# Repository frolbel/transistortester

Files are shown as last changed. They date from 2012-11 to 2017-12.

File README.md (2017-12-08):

# TransistorTester with AVR microcontroller

This repository is based on the software repository of the TransistorTester of Markus F. and Karl-Heinz Kubbeler.

The current revision of the authors you can see on the following: [https://www.mikrocontroller.net/svnbrowser/transistortester/](https://www.mikrocontroller.net/svnbrowser/transistortester/?sortby=author)

Initially, this repository is **GitHub** clone of **SVN** repo svn://mikrocontroller.net/transistortester/

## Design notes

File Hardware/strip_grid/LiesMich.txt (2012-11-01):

Die Datei ttester_strip_grid.diy ist ein Streifenleiter-Karten Entwurf für
den Transistortester. Die Datei TTester_strip.pdf zeigt das Ergebnis im PDF-Format.

Der Entwurf wurde mit der Software diy-layout-creator (DIYLC) gemacht.
Da das Programm DIYLC in Java programmiert ist, sollte es Betriebssystem unabhängig
genutzt werden können.
Siehe dazu für nähere Information: http://code.google.com/p/diy-layout-creator

Es wurde sowohl die Abschalt-Automatik als auch der Quarz und die Präzisions-
Spannungsreferenz integriert.
Aber die Pinbelegung des ATmega wurde für dieses Layout angepaßt!
Die erforderlichen Programm-Anpassungen für den ATmega werden mit der
Makefile Option STRIP_GRID_BOARD gemacht.
Das Programm mit der Standard Pinbelegung kann auf diesem Board nicht laufen !!
Genauso wenig läuft ein für die Streifenleiter-Karte angepaßtes Programm auf
einer Standard-Karte!

Eine Standard 100mm x 100mm Streifenleiter-Karte kann auf das erforderliche Maß
verkleinert werden.
Es ist ratsam, zuerst die Befestigungslöcher zu bohren und danach die Drahtbrücken
zu verlöten. Die Leiterbahnunterbrechungen sollten an den angegebenen Stellen auf
keinen Fall vergessen werden. Beim ISP-Stecker und bei REF1 liegen die Unterbrechungen
zwischen den Rasterpunkten!

Auf der Platine ist der Spannungsregler IC2 (78L05) eingezeichnet, ein Low Drop Regler
wie der MCP1702-5002 kann in der neben der Platine gezeichneten Weise eingebaut werden.
Die Anschlußbelegung ist nicht kompatibel!
Der Widerstand R1 (680 Ohm) ist unter dem ATmega-Sockel montiert und sollte deswegen
als einer der ersten Bauteile verlötet werden. Um einen Kurzschluß auszuschließen,
sollte der Anschlußdraht mit einem Isolierschlauch überzogen werden.

Die GND Leitung ist an den ATmega von beiden Seiten herangeführt und ist zusätzlich
unter dem Sockel gebrückt.
Der Widerstand R10 ist als einziger Widerstand stehend montiert.
Wenn das Potentiometer VR1 vom LCD-Display verdeckt wird, kann man das Potentiometer
auch auf der Lötseite verbauen. Anderenfalls muß man die VEE Spannung ohne das eingesteckte
Display einstellen.

Nach der Montage aller Bauteile, aber ohne das eingesteckte Display und den ATmega
sollte man die Verbindungen mit einem Ohmmeter oder Durchgangsprüfer testen.
Die GND Verbindungen sollten nur an den vorgesehenen Pinnen (ATmega, ISP und LCD) 
vorhanden sein. Ebenso sollten die VCC Verbindungen nur an den vorgesehenen Pinnen
vorhanden sein.
Nach diesem Test kann man die Spannungsquelle anschließen und die VCC Spannung bei
gedrücktem Taster überprüfen. Wenn hier die erwarteten 5V vorhanden sind, kann
man den ATmega und das LCD einstecken.

Wenn der ATmega noch nicht programmiert ist, muß als nächste Aktion die Programmierung
des ATmega über die ISP-Schnittstelle erfolgen.

Für die eventuelle Fehlersuche sollte man die Hinweise in der PDF-Dokumentation beachten.

Viel Erfolg beim Nachbau!

Karl-Heinz

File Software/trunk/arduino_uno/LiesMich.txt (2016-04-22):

Sie müssen eine "shield" Platine für den Arduino UNO benutzen, um das Transistortester Programm zu nutzen.
Sie finden eine Beispielplatine im Ordner Hardware/ArduinoUno_shield, welche aus einem Stück Streifenraster Platinenmaterial gebildet wurde.
Diese Implementation des Transistortesters benutzt derzeit kein LCD Display.
Alle Daten werden nur auf dem seriellen Port mit 115200 Baud ausgegeben.
Natürlich hat ein unabhängiger Tester einige Vorteile.
Aber der Arduino Uno ist ein einfacher Weg um die Software auszuprobieren
weil man keinen Programmierer oder keine externe Stromversorgung braucht.

Auf meinem Mint Linux-System habe ich die Arduino Sketch Entwicklungsumgebung benutzt, um das 
Board zu wählen (Tools/Board -> Arduino Uno).
Dann konnte ich den richtigen seriellen Port prüfen und auswählen (Tools/Serieller Port -> /dev/ttyACM0) .
Bitte überprüfen Sie auf ihrem Rechner die Port Nummer (ttyACM0, ttyACM1 ...).
Benutzen Sie bitte nicht die Sketch Umgebung, um das Transistortester Programm zu übersetzen.
Benutzen Sie bitte nur meine Makefile mit dem avr-gcc Paket und dem avrdude Programm um die Software
zu übersetzen und zum ATmega zu übertragen.
Ich habe das "make flash" Kommando auf einer Linux Terminal Fenster benutzt, um das Programm zum
ATmega328P auf der Arduino Platine zu übertragen.
Wenn ich den "make upload" Befehl benutzt habe, wurde die Programm-Daten zwar richtig zum ATmega328P
übertragen, aber die EEprom Daten wurden nicht korrekt übertragen.
Auf meinem Board hat das Laden der EEprom Daten einige Daten aus dem Flash Speicher zerstört und
deshalb war das Programm nicht mehr lauffähig.
Dieses Problem mit den EEprom Daten ist der Grund, warum Sie die Makefile Option USE_EEPROM nicht
benutzen sollten und warum Sie die Kalibration zwei Mal laufen lassen sollten.

Für die Tests habe ich zwei chinesische Arduino Uno Nachbildungen benutzt, die aber im Original Zustand
viele Probleme zeigten. Der Grund war ein Hardware Problem bei diesen Arduino Boards mit einer DIP Version
des ATmega328P. Das GND Signal von Pin 8 des ATmega328 war bei diesen Boards nicht angeschlossen.
Sie sollten also besser die chinesischen Boards prüfen, wenn Sie eine DIP version des ATmega328
auf einem Sockel finden.
Der Widerstand zwischen Pin 8 und Pin 22 des ATmega328P sollte unter 0.5 Ohm liegen!!!
Beide Pinne des ATmega328P sind auch intern verbunden, aber diese Verbindung hat gewöhnlich mehr als 1 Ohm.
Wenn Sie nicht sicher sind, ob Ihr Board das gleiche Problem hat, können Sie auch den ATmega328 (DIP)
entfernen und der Widerstand zwischen Pin 8 und Pin 22 des Sockels erneut messen.
Sie sollten im Fehlerfall eine Drahtbrücke auf der Arduino Uno Platine nachrüsten.
Sie können auch eine Beschreibung mit Bildern auf https://www.mikrocontroller.net/topic/395590 finden!
Ich habe zusätzlich auch einen SMD Kondensator (220nF) zwischen Pin 7 und Pin 8 nachgerüstet.

Um die Daten des Transistortesters anzuzeigen, wird der serielle Port (TXD, PD1) benutzt.
Dieser Port ist mit der USB-Schnittstelle des Arduino verbunden.
Um die Daten darzustellen, sollten Sie das Terminal Fenster (Tools/Serial Monitor) ihres Arduino Sketchs benutzen.
Das Terminal Fenster startet mit der vorher ausgewählten seriellen Schnittstelle (Tools/Serieller Port).
Sie müssen eine Baud Rate von 115200 auf ihrem "Seriell Monitor" Fenster einstellen.
Bitte beenden Sie den "Seriell Monitor", bevor Sie versuchen neue Software hochladen.

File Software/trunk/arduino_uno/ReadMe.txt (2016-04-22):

You must setup a shield board for the Arduino UNO to use the transistortester program.
You can find a board example build with strip grid material in the Hardware/ArduinoUno_shield.
This implementation currently don't use any LCD display.
All the data output is written only to the serial port at 115200 baud.
Of course a stand alone version of the tester have some advantages.
But the Arduino Uno is a easy way to test the software because you need no programmer
and no external power supply.

On my Mint Linux-system I have used the Arduino sketch environment to select the board (Tools/Board -> Arduino Uno).Then I could check and select the right serial port (Tools/Serieller Port -> /dev/ttyACM0).
Please check the number of the port (ttyACM0, ttyACM1 ...).
Your transistortester Makefile in the directory trunk/arduino_uno should use the same
USB PORT (behind PROGRAMMER=arduino).
Please do not use the sketch to build a transistortester program for the Arduino.
You should use my Makefile with the avr-gcc and the avrdude to build and upload the program data.
I did use the "make flash" command at the linux command window to upload the program data to the ATmega328P.
If you use the "make upload" command, the program data are loaded correctly, but the EEprom data are 
not written correctly.
With my board the loading of EEprom data had destroyed some data in the flash memory and the program
was not useable after this.
This problem with the EEprom is the reason why you should not use the Makefile option USE_EEPROM and 
why you should run the calibration twice.

For the tests I did use two chinese clones of the Arduino Uno, which have worked not proper in the original state.
The reason for this was a hardware problem at the Arduino boards with a DIP version of the ATmega328.
The GND signal for pin 8 of the ATmega was not connected at both boards. You should better check your
board, if you find a DIP ATmega328 at a socket.
The resistance between pin 8 and pin 22 of the ATmega328P should be below 0.5 Ohm!!!
Both pins of the ATmega328P are internaly connected, but this connection has usually a resistance
of more than 1 Ohm. When you are not shure, if your board has the same problem, you can remove the ATmega328 (DIP)
and check the resistance between pin 8 and pin 22 at the socket again.
You should solder a wire jumper to the Arduino Uno board, if you detect the same problem.
You can find a report with pictures at https://www.mikrocontroller.net/topic/395590  !
I have also added a additional SMD capacitor (220nF) between pin 7 and pin 8. 

To display the data of your transistor tester, the serial port (TXD, PD1) is used.
This is connected to the USB-port of your Arduino Board.
To show the results, you should start the terminal window (Tools/Serial Monitor) at your Arduino sketch.
The terminal window starts with the previous selected serial port (Tools/Serieller Port).
You must select a baud rate of 115200 at your "Serial Monitor" window.
Please finish your "Serial Monitor" before you try to upload new software !

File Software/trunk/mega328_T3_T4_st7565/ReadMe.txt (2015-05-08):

This configuration is made for the chinese printed board
T3 or T4  with a graphical display.
Pictures and some usefull information is published from user Tomas P.
at the transistortester thread:
https://www.mikrocontroller.net/topic/248078?goto=4120737#4105488

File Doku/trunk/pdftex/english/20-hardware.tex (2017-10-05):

\chapter{Hardware}

\section{Circuit of the TransistorTester}
\label{sec:hardware}
The circuit of the TransistorTester in figure \ref{fig:ttester} is based on the circuit of
 Markus F. released in Abb.~1 of AVR-Transistortester report \cite{Frejek}.
Changed or moved parts are marked with green color, optional parts are marked with red color.

Some changes are made because the electronical power switch make problems in some implementations.
Therefore the resistor R7 is reduced to \(3.3k\Omega\). The capacitor C2 is reduced to
10~nF and R8 is moved so that the PD6 output does not try to switch the C2 capacitor directly.
 Additional blocking capacitors are added and should be placed
near the power connection of the Atmega and near the Voltage regulator.

Because the PD7 input and PC6 (RESET) are the only pins, where pull up resistors where
needed, one extra \(27k\Omega\) resistor is added to the PD7 (pin~13) input. With this modification
the software can disable all internal pull up resistors of the ATmega.

The additional crystal with its \(22pF\) capacitors are optional added. 
The accuracy of a crystal has the benefit of more stable time measurement for getting the
capacitor values.

New software version can use a voltage scale switch of the ADC. The speed of switching is reduced
by the external capacitor C1 at the AREF (21) pin of the ATmega. To avoid slowing down the
measurement speed more than necessary, the value of this capacitor should be reduced to 1nF.
Removing of the capacitor C1 is also possible.
For adapting the software to the actual circuit take a look to the Makefile options in the
configuring chapter \ref{sec:config} at page~\pageref{sec:config}.

Some different versions of R11 / R12 resistor combinations circulates
in the internet. I~have adapted my software to the original of Markus F. \cite{Frejek} with \(10k\Omega\) and \(3.3k\Omega\).
The voltage ration of the divider can be set with Makefile options.

The additional \(2.5V\) precision voltage reference connected at pin PC4 (ADC4) can be used to
check and calibrate the VCC voltage, but is not required. You can use a LM4040-AIZ2.5 (0.1\%),
a LT1004CZ-2.5 (0.8\%) or a LM336-Z2.5 (0.8\%) as voltage reference.
If you don't install the precision voltage reference and you don't add the relay extension,
you should install a pull up resistor R16 to PC4 with a higher resistance value (\(47k\Omega\)).
This helps the software to detect the missing voltage reference.
A optional ISP connector has been added to easier load new software versions to the tester.

\begin{figure}[H]
\centering

\caption{New circuit of TransistorTester}
\label{fig:ttester}
\end{figure}

The table~\ref{tab:display-con} show the assignment of the port D for different display versions
and the assignment of the additional functions.
For the SPI interface a signal LCD-CE is available at the ATmega port. The controller input CE (Chip Enable) can 
be also connected to GND instead of connecting this input to the ATmega output LCD-CE.

\begin{table}[H]
  \begin{center}
    \begin{tabular}{| c || c | c | c | c | c | c |}
    \hline
           & Character     & ST7565 LCD & ST7920 LCD     & NT7108 LCD  & SSD1306     & additional function \\
      Port & LCD           &   SPI      & serial         & serial      &   I\textsuperscript{2}C      & \\
    \hline
    \hline
    PD0    &  LCD-D4       &  LCD-REST  & LCD-REST       & 595-PCLK        &            & \\
    \hline
    PD1    &  LCD-D5       &  LCD-RS    &                & LCD-CS2     &             & rotary encoder 2 \\
    \hline
    PD2    &  LCD-D6       &  LCD-SCLK  & LCD-B0         & 164-595-CLK &  LCD-SDA    & \\
    \hline
    PD3    &  LCD-D7       &  LCD-SI    &                & LCD-CS1     &             & rotary encoder 1 \\
    \hline
    PD4    &  LCD-RS       &            &                & LCD-RS      &             & frequency counter \\
           &               &            &                & 164-595-SER &             &                \\
    \hline
    PD5    &  LCD-E        & (LCD-CE)   & LCD-EN         & LCD-EN      &   LCD--SCL  & \\
    \hline
    PD7    &  pushbutton   & pushbutton & pushbutton     & pushbutton  & pushbutton  & \\
    \hline
    \end{tabular}
  \end{center}
  \caption{Pin assignments for different displays}
  \label{tab:display-con}
\end{table}

The software can follow to another pin assignment of port D for a simpler connection of the
LCD display. 
The following table \ref{tab:grid-change} shows the modifies assignments for the strip grid layout and
the alternativ connection of a graphical display for the micocontrollers ATmega328.
Also the using of port inputs for additional functions is shown.
With the connections for the graphical display with the strip grid option (STRIP\_GRID\_BOARD=1)
the frequency counter function can not be used, because the port PD4 (T0) is used.
But this connection is used by a chinese version with graphical display. 
In most cases the additional functions like rotary encoder or frequency counter are easier to
build with the board versions for a character display, because the required data signals are
routed to the display connector.

\begin{table}[H]
  \begin{center}
    \begin{tabular}{| c || c | c | c | c | c | c |}
    \hline
           & char. LCD    & ST7565 LCD & ST7565 LCD    & additional function \\
      Port &   =1         &   =1       & STRIP\_GRID   & \\
    \hline
    \hline
    PD0    &  pushbutton  &              &             & \\
    \hline
    PD1    &  LCD-D7      &  LCD-SI      & LCD-A0 (RS) &  rotary encoder 2  \\
    \hline
    PD2    &  LCD-D6      &  LCD-SCLK    & LCD-REST    & \\
    \hline
    PD3    &  LCD-D5      &  LCD-A0 (RS) & LCD-SCLK    & rotary encoder 1 \\
    \hline
    PD4    &  LCD-D4      &  LCD-REST    & LCD-SI      & frequency counter \\
    \hline
    PD5    &  LCD-E       &  (LCD-CE)    &             & \\
    \hline
    PD7    &  LCD-RS      &  pushbutton  & pushbutton  & \\
    \hline
    \end{tabular}
  \end{center}
  \caption{port assignments with option STRIP\_GRID\_BOARD}
  \label{tab:grid-change}
\end{table}

\section {Extensions for the TransistorTester}

\subsection{Protection of the ATmega inputs}

For better protection of the ATmega inputs one of the additional circuits~ \ref{fig:relay_addon} 
can be integrated. The de-energized contacts of the relay protect the ATmega without power.
The contacts will be opened by software only for measurement.
Also with the additional diode protection the chance of the ATmega will be better to survive the connection
of a capacitor with higher residual voltage.
A complete protection is not possible. Therefore capacitors should always be discharged before measuring.

\begin{figure}[H]
  \begin{subfigure}[b]{9cm}
    \centering
    
    \caption{with Relay}
  \end{subfigure}
  ~
  \begin{subfigure}[b]{9cm}
    \centering
    
    \caption{with Diodes}
  \end{subfigure}
  \caption{Additional protection of the ATmega inputs}
  \label{fig:relay_addon}
\end{figure}

You can get a better protection with a relay with 3 changeover contacts, which is shown in figure~\ref{fig:relay_um_addon}.
The discharge current is limited with the resistors and the ATmega-inputs are disconnected in the protected mode.
But you don't forget, that the tester remains unprotected during the measurement sequence.

\begin{figure}[H]
\centering

\caption{Improved protection with relay}
\label{fig:relay_um_addon}
\end{figure}

\subsection{Measurement of zener voltage above 4~Volt}

If the serial output of text is not required, the Pin PC3 of the ATmega can be used as analog
input for measuring a external voltage. The voltage can be up to \(50V\) with the optional 10:1 resistor
divider and can be used for measuring the breakdown voltage of a zener diode. 
A current limiting power supply with up to \(50V\) can be switched on with low signal at PD7 pin of the
ATmega to deliver current for testing the break down voltage of a zener diode.
Figure~\ref{fig:zener} shows a suggestion for this expansion.
The tester shows the external voltage as long as you hold the key pressed.
About \(40mA\) more battery current is used by this expansion during key pressing.

\begin{figure}[H]
\centering

\caption{Expansion for measuring of break down voltage of Zener diodes}
\label{fig:zener}
\end{figure}

The 10:1 voltage divider can be used with the optional dialog part for the ATmega328 without the 
activated DC-DC converter for the zener diode measurement.
Without the pressed key the voltage converter is not powered. For that the external voltage 
(for example battery voltage) can be measured at the zener diode port.
You can only measure positiv DC voltages up to \(50V\).
You have also to respect the correct polarity.

\subsection{Frequency generator}

With the dialog part of the ATmega you can also select a frequency generator, which supports
currently a selection of frequencies from \(1Hz\) up to \(2MHz\).
The output of the \(5V\) signal is done with a \(680\Omega\) resistor to test port TP2.
You can use the GND signal from the minus pin of the zener diode extension or the test port TP1.
The test port TP3 is connected to GND with a \(680\Omega\) resistor.
Of course you can also connect a driver circuit to the ATmega port PB2 with a separate output
driver circuit and a additional output terminal. But the input of this circuit should not insert a
big capacity load for the ATmega output.

\subsection{Frequency measurement}
\label{sec:frequency_counter}

For using the with the dialog selectable frequency measurement is a little hardware extension
necessary. The input pin PD4 (T0/PCINT20) of the ATmega is used for the frequency measurement.
The same pin is also used for the connection of the LCD. With normal layout, the PD4 pin is connected
to the LCD-RS signal, with the strip grid design it is connected to LCD-D4.
For both signals the PD4 pin can be switched to input as long as no output to the LCD is
required. The LCD respect the input value only, if the LCD-E signal is switched to GND.
For driving the input pin from external clock source at least one serial resistor of \(270\Omega\) should be used.
Better you should use the circuit of figure~\ref{fig:FreqMes} .
The voltage at the PD4 pin (LCD-RS or LCD-D4) should be adjusted to \(2.4V\) without the assembled ATmega
or during frequency measurement of the ATmega, to get the best sensivity for the input frequency signal.
The LCD should always be installed for adjusting, because the pull up resistor of the LCD change the voltage.

\begin{figure}[H]
\centering

\caption{Extension for measurement of frequency}
\label{fig:FreqMes}
\end{figure}

\subsection{Using of a rotary pulse encoder}

For easier control of the menu function for the ATmega328 you can expand the circuit 
by a rotary pulse encoder with a push button.
The circuit~\ref{fig:RotExt} shows a standard expansion for a normal character LCD.
All signals for the connection of the rotary pulse encoder are available at the plug connector
for the LCD. For this reason the expansion can also be easy upgraded for many existing testers.
In many cases the graphical LCD is assembled on a adapter board with some connection pins
of the character LCD. Also in this cases the upgrade with a rotary encoder is not very difficult to do.

\begin{figure}[H]
\centering

\caption{Expansion with a rotary pulse encoder}
\label{fig:RotExt}
\end{figure}

The figure~\ref{fig:RotEnc} shows the feature of two different rotary pulse encoder.
The version 1 has twice as much indexed positions (detents) per turn as pulses per turn.
The version 2 has the same count of detents as pulses per turn.
The slope of one of the two switch signals is sometimes exactly at the detent of the 
rotary pulse encoder.

\begin{figure}[H]
\centering

\caption{Feature of two different rotary pulse encoder}
\label{fig:RotEnc}
\end{figure}

The figure~\ref{fig:RotBounce} shows a rotary pulse encoder, which has not only
bouncing contacts, but also has a unstable state of one of the switches at the indexed
position (detent). Every change of the state of the switches is detected by the program
and saved in a cyclic buffer. Therefore the last three states of the switches can be checked
after every status change.
For every cycle of switch states a total of four sequences of state can be defined for every direction of rotation.
If there is only one indexed position (detent) for every cycle of switch states, only
one of the state sequence pair must be monitored (WITH\_ROTARY\_SWITCH=2 or 3) for correct counting.
If there are two indexed positions for every cycle of the switch states, as shown in figure~\ref{fig:RotBounce},
you must monitor two pairs of switch state sequences (WITH\_ROTARY\_SWITCH=1).
You can choise any resolution for the WITH\_ROTARY\_SWITCH for a rotary pulse encoder without
indexed positions. A value of 2 or 3 selects the lowest resolution, 1 selects a middle resolution
and 5 selects the highest resulution.
A oscillation of the selection (counter up, counter down) can be avoided with the type of monitoring,
but sometimes a count can be missed with a bad placement of the indexed position.

\begin{figure}[H]
\centering

\caption{A rotary pulse encoder with bouncing switches}
\label{fig:RotBounce}
\end{figure}

In place of the two switches of a rotary switch encoder you can also install two seperate
key buttons for Up and Down movement, if no rotation switch encoder is present or favored.
In this case the option WITH\_ROTARY\_SWITCH must be set to 4 for a correct handling of
the program.

\subsection{Connection of a graphical display}

Many thanks to Wolfgang Sch. for his work to support a chinese version with ST7565 controller.
By now you can also connect a graphical 128x64 pixel LCD with a ST7565 controller.
Because the ST7565 controller is connected with a serial interface, only four signal
lines are required. Two port D pins of the ATmega can be used otherwise.
The ATmega processor should have at least 32k flash memory for the support of a graphical display.
The ST7565 controller works with a operating voltage of \(3.3V\) .
Therefore a additional \(3.3V\) voltage regulator is required.
The data sheet of the ST7565 controller does not allow the direct connection of input pins to
\(5V\) signal level. So the extension of figure \ref{fig:ST7565lcd} uses a additional 74HC4050 CMOS
device for the conversion of the voltage level.
You can try to exchange the four 74HC4050 gates with four resistors of about \(2.7k\Omega\).
With the voltage drop at the resistors you will prevent the increase of the \(3.3V\) controller power voltage 
across the diodes of the controller inputs from the \(5V\) ATmega outputs signals.
You have to try, if the signal form with the resistors can be accepted from the ST7565 controller inputs.
The signal form at the controller inputs will be more simular to the output shape of the ATmega with the 74HC4050 gates in any case.\\

\begin{figure}[H]
\centering

\caption{Connection of a graphical display with ST7565 controller}
\label{fig:ST7565lcd}
\end{figure}

The table \ref{tab:spi-processor} shows more alternativs to connect a 
ATmega328 or other prozessors with the SPI (LCD\_INTERFACE\_MODE=4) or the
3LINE (LCD\_INTERFACE\_MODE=3) interface.
The different connector lists for one processor type
can be selected with the Makefile Option STRIP\_GRID\_BOARD.
The connector pin list is defined in the file config.h.
If you need a different wiring list, you should choose a new code number
for the option STRIP\_GRID\_BOARD and supplement the setting in the config.h file.

\begin{table}[H]
  \begin{center}
    \begin{tabular}{| c || c | c | c | c | c | c | c |}
    \hline
 Processor  & m644  & m1280 & m1280  & m328 & m328 & m328 & m328 \\
STRIP\_GRID\_BOARD &       &   -   &   1    &  -   &  1   &  2   &  5   \\
    \hline
    \hline
Signal:     &       &       &        &      &      &      &      \\
  RES       &  PB4  & PA0   &  PA4   & PD0  & PD4  & PD0  & PD2 \\
    \hline
  EN, CLK   &  PB6  & PA2   &  PA2   & PD2  & PD2  & PD2  & PD3 \\
    \hline
  RS, D/C   &  PB5  & PA1   &  PA3   & PD1  & PD3  & PD3  & PD1 \\
    \hline
  B0, MOSI  &  PB7  & PA3   &  PA1   & PD3  & PD1  & PD1  & PD4 \\
    \hline
  CE, CS    &  PB3  & PA4   &  PA5   & PD5  & PD5  & PD5  & PD5 \\
    \hline
    \end{tabular}
  \end{center}
  \caption{SPI wiring facility for different processors}
  \label{tab:spi-processor}
\end{table}

Normally the ST7565 or SSD1306 controller is connected with a 4-wire SPI interface.
But with the SSD1306 controller you can also use a I\textsuperscript{2}C interface with PD2 as SDA and PD5 as SCL signal.
The SDA and SCL signals must be equipped with pull-up resistors of about \(4.7k\Omega\) to \(3.3V\).
A solution for connecting the OLED display shows the figure  \ref{fig:ssd1306i2c}.
The outputs of the ATmega is only switched to \(0V\) for the I\textsuperscript{2}C signals.
Before connecting the pull-up resistors to \(5V\) you must check, if your display module can tolerate
a \(5V\) signal level. Normally the data inputs of the controller are protected with diodes to \(3.3V\).
You should make sure, that you have loaded a program with the I\textsuperscript{2}C support to the ATmega 
before the Display is connected. If you have loaded a program with another interface, 
the output are also switched to the \(5V\) side.
Because I have determined a influence to the tester results across the VCC connection of a OLED module,
a additional decoupling with a serial resistor of \(68\Omega\) with a additional \(10\mu F\) blocking capacitor
is recommended. Instead of the \(68\Omega\) resistor you can also use a inductor with about \(1mH\).
Without the additional filter my tester has reported collector residual currents with bipolar transistors and a
OLED display.
Also you should check the pin sequence of your OLED module, some moduls have a different location of GND and VCC.
 
\begin{figure}[H]
\centering

\caption{Connection of a graphical OLED display with I\textsuperscript{2}C interface}
\label{fig:ssd1306i2c}
\end{figure}

For connection to the ATmega644 series of processors the pins PB3 (SCL) and PB4 (SDA) instead of PD5 and PD2 are used.
For the ATmega1280 processor series the pins PA5 (SCL) and PA4 (SDA) are used.
The exchange of a text display to a graphical display is possible with a adapter printed board because
all required data signals and power signals are available at the LCD connector.

A little simpler is the connection of a graphical display with a ST7920 controller because
the controller can operate with \(5V\) power voltage.
For that the display should offer 128x64 visible pixels.
The display module with the ST7920 controller can be connected with the 4-bit parallel interface or with a
special serial interface., as shown in figure \ref{fig:ST7920lcd}.
 
\begin{figure}[H]
\centering

\caption{Connection of a display with ST7920 controller}
\label{fig:ST7920lcd}
\end{figure}

For both connection types the software must be configured in a special way.
The Makefile option ''WITH\_LCD\_ST7565 = 7920'' must be set in any case, for the serial
connection type you must set also the option ''CFLAGS += -DLCD\_INTERFACE\_MODE=5''.
The table~\ref{tab:ser-processor} shows the connection of the serial signals with
the INTERFACE\_MODE 5 (ST7920) and 7 (SSD1803) for different processors.

\begin{table}[H]
  \begin{center}
    \begin{tabular}{| c || c | c | c | c |}
    \hline
 Processor  & m644  & m644 & m1280  & m328 \\
STRIP\_GRID\_BOARD &   -   &   1   &        &     \\
    \hline
    \hline
Signal:     &       &       &        &         \\
  EN        &  PB3  & PB6   &  PA5   & PD5     \\
    \hline
  B0, R/W   &  PB4  & PB7   &  PA4   & PD2      \\
    \hline
  RESET     &  PB2  & PB4   &  PA0   & PD0      \\
    \hline
    \end{tabular}
  \end{center}
  \caption{Serial connection for different processors}
  \label{tab:ser-processor}
\end{table}

The orientation of the presentation can be changed with the options LCD\_ST7565\_H\_FLIP and 
LCD\_ST7565\_V\_FLIP in the same way as with the other graphical displays.\\

A special case is the connection of displays with a NT7108 (KS0108, S6B0108) controller. Because these displays can only use 
the 8-bit parallel interface, you must use a serial to parallel converter.
The simplest way seems to be the use of a 74HCT164 or a 74HCT595 chip.
A suitable suggestion of a connection circuit shows the figure \ref{fig:NT7108lcd} .

\begin{figure}[H]
  \begin{subfigure}[b]{9cm}
    \centering
    
    \caption{with 74HCT164}
  \end{subfigure}
  ~
  \begin{subfigure}[b]{9cm}
    \centering
    
    \caption{with 74HCT595}
  \end{subfigure}
  \caption{Connection of a graphical display with a NT7108 controller}
  \label{fig:NT7108lcd}
\end{figure}

You must check the pin layout of your LCD module, some moduls have different signal sequence.
Some different pin layouts found in data sheets for the ABG128064 series are shown in table~\ref{tab:NT7108types}.

\begin{table}[H]
  \begin{center}
    \begin{tabular}{| c || c | c | c | c |}
    \hline
           & 128064H  &  128064G  & 128064C  & 128064B \\
    Signal &         &          &         &         \\
    \hline
    \hline
  VDD (5V) &   1     &  2       &   4     & 2       \\
    \hline
  VSS (GND) &   2     &  1       &   3     & 1       \\
    \hline
 VO (Drive) &   3     &  3       &  (5)    & 3       \\
    \hline
  DB0-DB3   &   4-7   &  7-10    &   9-12  & 7-10    \\
    \hline
  DB4-DB7   &   8-11  &  11-14   &   13-16 & 11-14   \\
    \hline
  CS1       &   12    &  15      &   1     & 15      \\
  CS2       &   13    &  16      &   2     & 16      \\
    \hline
  Reset     &   14    &  17      &   -     & 17      \\
    \hline
  R/W       &   15    &  5       &   7     & 5       \\
    \hline
  RS        &   16    &  4       &   6     & 4       \\
    \hline
  E         &   17    &  7       &   8     & 6       \\
    \hline
  VEE       &   18    &  18      &   -     & 18      \\
    \hline
  LEDA      &   19    &  19      &   17    & (19)      \\
  LEDK      &   20    &  20      &   18    & -      \\
    \hline
    \end{tabular}
  \end{center}
  \caption{Pin layout of different NT7108 moduls}
  \label{tab:NT7108types}
\end{table}

The table \ref{tab:7108-processor} shows the connection of a serial NT7108 controller
for different processor series.
\begin{table}[H]
  \begin{center}
    \begin{tabular}{| c || c | c | c |}
    \hline
 Processor  & m644  &  m1280  & m328 \\
    \hline
    \hline
Signal:     &       &        &         \\
  EN        &  PB3  &  PA5   & PD5     \\
    \hline
  RS        &  PB2  &  PA4   & PD4      \\
  B0        &  PB2  &  PA4   & PD4      \\
    \hline
  CS1       &  PB7  &  PA3   & PD3      \\
    \hline
  CS2       &  PB5  &  PA1   & PD1      \\
    \hline
  CLK       &  PB6  &  PA2   & PD2      \\
    \hline
  PCLK      &  PB4  &  PA0   & PD0      \\
    \hline
    \end{tabular}
  \end{center}
  \caption{Serial NT7108 connection for different processors}
  \label{tab:7108-processor}
\end{table}

You can also use a display with a PCF8814 controller, which is usualy used in a Nokia 1100 handy for example.
You must check, which interface of the controller is used in your display module.
The PCF8814 controller can support the SPI-interface with 3 lines and 4 lines,
the I\textsuperscript{2}C-interface and a special 3-line interface, which receice
the data/instruction signal as first serial bit before the 8 data bits.
Because the display support only 96x65 pixels, the big icons for transistors are not
used with this controller. The output is simular to the character display.
As with the most graphical displays this controller also operated with 3.3~Volt.
Therefore a signal conversion for the \(5V\) outputs of the ATmega is required.
For the SPI interface and the 3-line interface you can use the outputs of the ATmega
like ''open collector'' outputs with the Makefile option LCD\_SPI\_OPEN\_COL.
You must use ''Pull-Up'' resistors with this option or you should not set
the option PULLUP\_DISABLE in the Makefile.
Currently only the 3-line interface is tested with the PCF8814 controller.

\begin{table}[H]
  \begin{center}
    \begin{tabular}{| c || c | c | c | c |}
    \hline
           &  PCF8814    & PCF8814        & PCF8814     & additional function \\
      Port &    SPI      & 3-line         &   I\textsuperscript{2}C      & \\
    \hline
    \hline
    PD0    &   LCD-RESet  & LCD-RESset       &            & \\
    \hline
    PD1    &   LCD-D/C   & LCD-SCE        &             & rotary encoder 2 \\
    \hline
    PD2    &   LCD-SCLK  & LCD-SCLK       &  LCD-SDIN   & \\
    \hline
    PD3    &   LCD-SDIN  & LCD-SDIN       &             & rotary encoder 1 \\
    \hline
    PD4    &             &                &             & frequency counter \\
    \hline
    PD5    &             & LCD-EN         &   LCD-SCLK  & \\
    \hline
    \end{tabular}
  \end{center}
  \caption{Pin assignments for different interface types of the PCF8814 controller}
  \label{tab:PCF8814-con}
\end{table}

Some code for supporting a PCF8812 controller with 102x65 pixels is also implemented,
but not yet tested.

\subsection{Connection of a graphical color display}

Some Chinese salesmen offer cheap color display modules with a SPI interface.
The picture \ref{fig:Color_both} shows the backsides of two supported modules with 128x128 pixel
and 128x160 pixel. 
The moduls are very small, so the shown text and symbols are very little.
But the appearance is sharp and clear.

\begin{figure}[H]
\centering
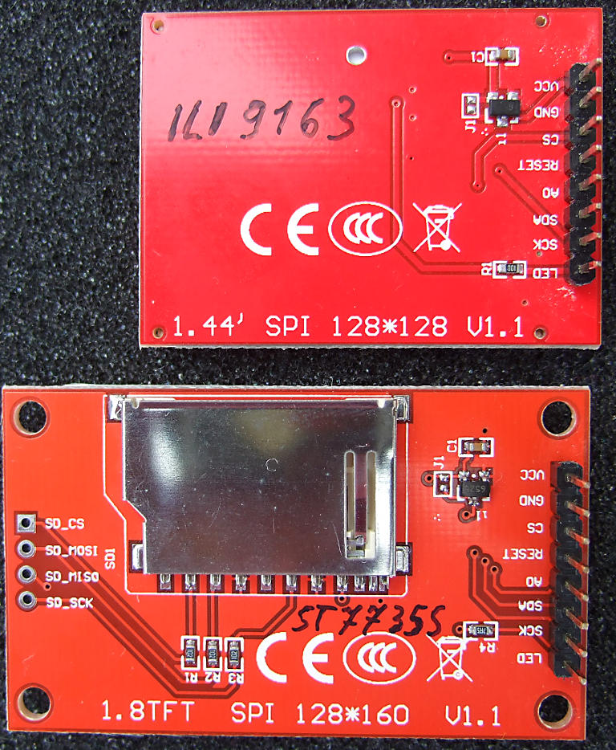
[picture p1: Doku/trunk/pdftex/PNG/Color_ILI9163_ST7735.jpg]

\caption{Back side of two Color-LCD's}
\label{fig:Color_both}
\end{figure}

The 128x128 pixel modul uses a ILI9163 controller.
The 128x160 pixel modul uses a very simular ST7735 controller.
The modules are tested with a adapter board, which connects the
SPI signals and the power to the terminal for the normal character display.
The adaption of the \(5V\) output signals of the ATmega to the \(3.3V\) inputs of the controller
is ensured with serial \(10k\Omega\) resistors.
The background light (LED) is required for this modules because nothing is readable without it.
Because of the high count of pixels in vertical direction you can display more text lines for this modules.
For the 128x128 pixel display you can display 8 lines of text with a 12x8 font,
for the 128x160 pixel display you can evel show 10 lines of text.
At the picture \ref{fig:Color_PNP} you can see the result of the measurement of a Germanium transistor
at a 128x128 pixel display.

\begin{figure}[H]
\centering
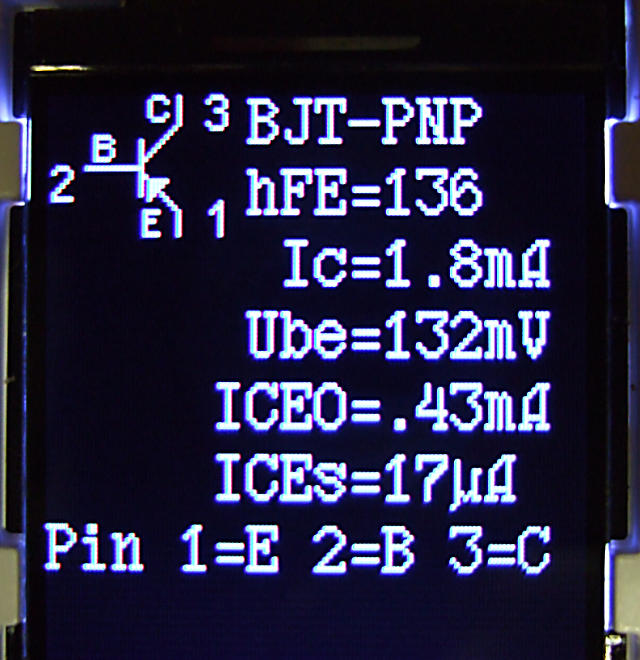
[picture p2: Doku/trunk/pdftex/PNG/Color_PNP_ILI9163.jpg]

\caption{Measurement of a bipolar PNP transistors}
\label{fig:Color_PNP}
\end{figure}

The color feature of the modules is currently not used.
Simply the background color and the foreground color can be changed in the file lcd\_defines.h or
in the Makefile.
The 16-bit color model of the controller is used by the software, the foreground color can be changed
with the constant LCD\_FG\_COLOR and the background color with the constant LCD\_BG\_COLOR .

\section{Hints for building the TransistorTester}
Every LCD-display with at least 2x16 character and a HD44780 compatible controller
can be used with the TransistorTester. You should respect the current needed for
illumination, some LCD need lower current than others.
I had tried OLED type displays, but this type cause interference with measurements
of the ATmega and are {\bf not} recommended. Also loading of special characters
for displaying the resistor symbol has caused problems with the OLED.

The resistors R1 to R6 are critical for measurements and this \(680\Omega\) and
\(470k\Omega\) resistors should be measurement type resistors (tolerance of 0.1\%) to
get the full accuracy.
You should use a precision socket for the ATmega microcontroller to enable
the replacement of the microcontroller.
The microcontroller ATmega8, ATmega168 and ATmega328 can be used.
Recommended is a ATmega328, if you wish to use all features.

Anyway you should assemble all parts to printed board without the microcontroller.
A up-to-date low voltage drop regulator like MCP1702-5002 is recommended as IC2, because it
need only \(2\mu A\) of standby current and can still deliver \(5V\), if your input
voltage is only \(5.4V\). But this part is not pin compatible to well known 78L05 with TO92 body!

After checking, that all needed parts are at the correct place, you should
first connect the battery or power supply to the printed board without LCD-display
and microcontroller. You should check the voltage at the power pins of the
microcontroller and LCD-display terminal during the Test key is pressed.
The voltage should disappear, if you release the Test key.
If the voltage had correct polarity and value,
you should disconnect the power and assemble the microcontroller with correct
alignment. Be careful and make sure, that all pins of the microcontroller
are in the socket holes.
Now you can also connect the LCD. Check if power pins of the LCD has the right connection to
GND and VCC of your board.

If you are sure that everything is all right, reconnect the power. 
If you have already programmed the ATmega, you can press the Test button.
By pressing the Test key, the background light of the LCD should switch on.
If you release the Test button, the LED should illuminate weak.
Notice, that the software for the microcontroller must be compiled for the
correct processor type. A program for the ATmega8 does not run on a ATmega168!

\section{Changeover for tester versions designed by Markus F.}
\label{sec:change_markus}
\begin{description}

\item[Voltage control]
If the problem exist, the tester will shut down immediately with every switch on.
With imy suggested setting of the fuses (Makefile) the voltage control of the different
ATmega versions is switched to \(4V\) (brown out level).
This may be the reason why the tester makes trouble with the power on sequence.
The Pin PD6 tries to switch the 100nF capacitor C2 to VCC level causing a voltage
breakdown of the VCC voltage (\(5V\)).
The capacitor C2 can be reduced to \textless~\(10nF\) without problems.
If possible, the direct connection of PD6 should be replaced by a resistor \textgreater~\(220\Omega\).
\item[Improvement of power on circuit]
Often this problem is the reason, if the tester starts with the button hold pressed, but switch off
directly by releasing. The problem is enforced by a high current background light for the LCD.
The resistor R7 to the base of the PNP transistor T3 was optimized with the value \(27k\Omega\) 
too much to save power consuming.
To improve the switching with lower battery voltage or lower current amplification factor of
the PNP transistor T3, you should reduce the resistance to \(3.3k\Omega\).
\item[Additional pull-up resistor at PD7]
The missing pull-up resistor results to a switch off of the tester with the message ''Timeout''
after a short display time.
The software is configured with the option PULLUP\_DISABLE, that all internal pull-up
resistors are switched off. For that reason the voltage of pin PD7 is not definded,
if the level is not switched by the push button or transistor T2 to GND.
One external pull-up resistor of \(27k\Omega\) to VCC avoid this error.
\item[Capacitor C1 at the AREF pin]
Many designs use a \(100nF\) capacitor at the AREF pin, like the design of Markus F. too.
As long as the reference voltage of the ADC is never changed, this is a good solution.
The software of the TransistorTester for the ATmega168/328 uses a automatic selection
of the internal \(1.1V\) reference voltage of the ADC, if the input voltage is below \(1V\).
With this solution a better resolution of the ADC can be reached for little input voltages.
Unfortunately the switching from \(5V\) to \(1.1V\) reference is very slowly. A additional
wait time of \(10ms\) must be respected for this reason.
With changing the capacity value to \(1nF\) this wait time can be reduced significant.
I have not noticed any degration of measurement quality with this change.
Even a removing of the capacitor has no significant change of measurement results.
If you prefer to leve the capacitor unchanged, you can remove the option NO\_AREF\_CAP
in the Makefile to activate longer wait times in the program.
\item[Expanding of a \(8MHz\) crystal]
With some skill you can expand a \(8MHz\) crystal to the backside of the printed board
directly to the pins PB6 and PB7 (pin 9 and pin 10).
My own expansion was done without the both \(22pF\) capacitors.
This solution has operated well with all tested ATmega.
But it is not required to use a crystal. You can still use the \(8MHz\) RC oszillator
by setting the fuses to get the better resolution of time constant for measuring  the capacity values.
\item[Smoothing of the operating voltage]
The original circuit of Markus F. shows only one \(100nF\) capacitor to block the VCC voltage.
This is clearly too little smoothing. You should at least use one \(100nF\) near the ATmega power pins
and one near the voltage regulator. The input of the voltage regulator should be
blocked with a \(100nF\) too.
Additional \(10\mu F\) capacitors (electrolytic or ceramic) at the input and
output of the voltage regulator can stable the voltage level.
Ceramic \(10\mu F\) capacitos with SMD mounting form are easier to use for backfitting
and have usually a lower ESR value. 
\item[Selection of the ATmega processor]
The using of the base function of the tester is still possible with a ATmega8.
The flash memory of that device is used near \(100\%\).
Because the ATmega168 or ATmeg328 processors are pin-compatible to the ATmega8,
I can recommend the replacement.
Actually the price for ATmega328 is so cheap, that there is no reason to take
a ATmega168 type.
With a ATmega168/328 you get the following advantages:
Self test with automatic calibration.\\
Improvement of measurement quality by automatic switching of ADC scale.\\
Measurement of inductors with resistance  below \(2100\Omega\).\\
Measurement of ESR value of capacitors with value of above  \(20nF\).\\
The resolution of resistor measurement below \(10\Omega\) is \(0.01\Omega\).\\
Using of pin PC4 as serial output.\\
\item[Missing precision voltage reference]
Usually the software should detect the missing voltage reference with the unconnected pin PC4.
In this case no VCC=x.xV message should appear in row 2 of the LCD on power on.
If this message appear without the reference, you should connect a \(2.2k\Omega\) resistor
to the PC4 input and VCC.

\end{description}

\section{Chinese clones with text display}
As I know, the tester is rebuild in China in two versions with character displays.
The first model is rebuild from the first design of Markus F. without the ISP port.
The assembled ATmega8 is placed in a socket, so you can replace it with a ATmega168 or ATmega328.
For this version you should consider all the hints of section \ref{sec:change_markus}.
Additional \(100nF\) ceramic cpacitors should be connected near by the VCC-GND and AVCC-GND pins of
the ATmega for better stabilization of the power voltage.
Because there is no ISP connector at the board, you must expand the board with a ISP connector or you
must plug the ATmega to a external socket for programming.
In addition you should notice, that if your ATmega should run with a \(8MHz\) crystal,
your external ISP programmer must have a external clock for programming or a crystal mounted at the socket.\\

The second version of rebuilded tester is build with SMD components. Also the fix installed ATmega168
is a SMD type with 32TQFP body.
Fortunately on the board is a 10-pole ISP connector provided for the programming.
I have analysed the board version ''2.1 2012/11/06''. One error is the assembly of the part ''D1'',
which should be a precision \(2.5V\) voltage reference. Assembled is only a zener diode.
This part should be removed. You can mount a LM4040AIZ2.5 or LT1004CZ-2.5 precision voltage reference
at this place. A missing voltage reference is noticed by the software, so that you must not install
the voltage reference.
My exemplar was delivered with software version 1.02k. The 10-pole ISP plug was not assembled and I must
install a jumper from ISP pin 6 to ISP pin 10. My programmer expect a GND connection at pin 10, but the
board has GND level only on pin 4 and pin 6 of the ISP.
The label of the ATmega168 was rub away and there was no documentation delivered with the part.
The lock fuses of the ATmega were set, so no readout was possible.
But I could install the software version 1.05k without any problems.
Another user has problems with the same software version 1.05k. This user has the chinese board ''2.2 2012/11/26''.
The software runs only without problems, if a additional \(100nF\) keramic capacitor was placed between
the pin 18-AVCC and 21-GND near by the ATmega.
The software 1.05k uses the sleep state of the ATmega for waiting time. For this reason the current alternates
often and the voltage regulator is stressed more.
Further I have noticed, that the VCC voltage is blocked with a \(100nF\) ceramic capacitor and with a
\(220\mu F\) electrolytic capacitor nearby the 78L05 voltage regulator.
The \(9V\) supply voltage is blocked with the same capacitors, but not at the input of the regulator but
at the emitter of the PNP transistor (parallel with the battery). 
The printed circuit board track from the ATmega168 to the test port is very thin, so that a resistance
of \(100m\Omega\) could be measured for one path. This will be the reason for measuring a resistance
of \(0.3\Omega\) for two direct connected pins.
The ESR measuring can usually consider this by zero compensation.
Beginning with version 1.07k  the software does respect this offset for measuring resistors below \(10\Omega\) too.

\section{Chinese clones with graphical display}
Newer rebuilds of the tester like a version from Fish8840  use a 128x64 pixel graphical display.
This version use a modified circuit for the switch on logic. 
The figure \ref{fig:Fish8840} shows a part of the modified circuit.

\begin{figure}[H]
\centering

\caption{Part of the circuit from the Fish8840 version}
\label{fig:Fish8840}
\end{figure}

How you can see at the values of resistor R8 and R15,
a 2:1 scaling factor for the battery voltage measurement is used instead of the original scaling factor.
In addition R15 is direct connected to the battery, what results to a power consumption in the switch off state.
The R15 should better be connected to the drain of Q1 or the input of the voltage regulator to prevent this
unneeded battery power consumption.
A suitable change of the printed board is shown in picture \ref{fig:Fish8840patch}.
A circuit path is cut between R17 and D5 and a new conductive path is inserted between Q1 and
R15 with a enameled copper wire.

\begin{figure}[H]
\centering
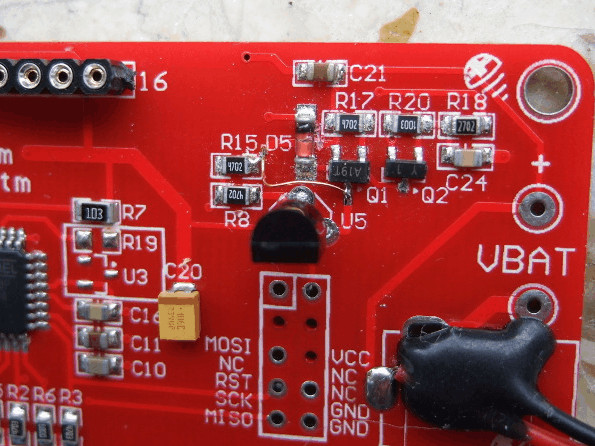
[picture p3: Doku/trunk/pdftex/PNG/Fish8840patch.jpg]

\caption{Picture of the changed Fish8840 printed board}
\label{fig:Fish8840patch}
\end{figure}

The scaling factor of the battery voltage must be specified in any case in the Makefile before any
attempt can be done to replace the original software (BAT\_NUMERATOR=66 for example).

The display module of the Fish8840 tester is equipped with a \(3.3V\) voltage regulator to adapt
the operating voltage of the display controller.
Because the \(3.3V\) operating voltage can be increased with the \(5V\) signal level of the data signals
from the ATmega, a adapter circuit according to the picture \ref{fig:Fish8840Adapt} is recommended.
The four data signal lines are equipped with four serial \(2.7k\Omega\) resistors at a little
breadboard.
Longer spacer bolts must be used to mount the display with the adapter board to the printed board
of the Fish8840 tester now.

\begin{figure}[H]
  \begin{subfigure}[b]{9cm}
    \centering
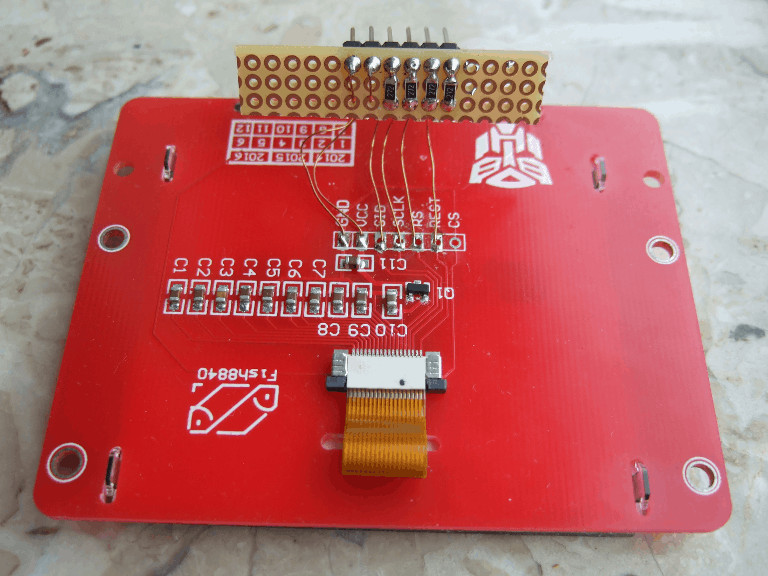
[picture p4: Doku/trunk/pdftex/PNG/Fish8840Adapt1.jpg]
    
    \caption{Display with the breadboard adapter}
  \end{subfigure}
  ~
  \begin{subfigure}[b]{9cm}
    \centering
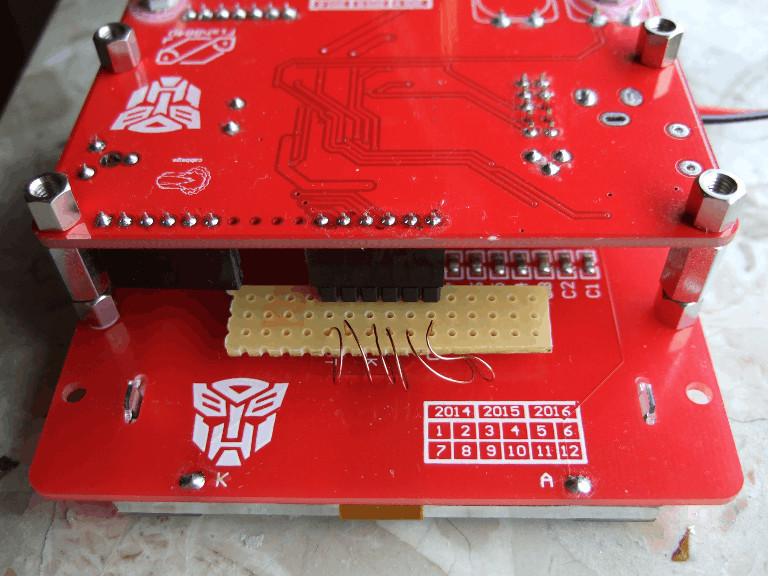
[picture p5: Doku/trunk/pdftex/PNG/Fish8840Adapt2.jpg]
    
    \caption{Ready mounted Tester}
  \end{subfigure}
  \caption{Adapter for a correctly display connection}
  \label{fig:Fish8840Adapt}
\end{figure}

Instead of this modification you can also use a special output mode of the 4~SPI signals of the ATmega
with the Makefile option LCD\_SPI\_OPEN\_COL .
With this option the outputs are not switched to VCC level,
but the internal ''pull-up'' resistors are switched on during the output of a high level.
If the option PULLUP\_DISABLE is set, additionally a external pull-up resistor for
the ''Reset'' signal (PD0) is required.
Because the data signals are never switched to VCC directly, the \(3.3V\) power of the LCD controller
can not be elevated.
My version of the Fish8840 tester has all signals for connecting a character display
routed to the LCD plug connector.
Therefore you can prepare the board for connection of a character display, if the
female header is completed and the potentiometer for the contrast level is added.
However the supply pin 15 for the background light is connected directly to the VCC level.
If you install a character display, you should check, that your display module
is equipped with a serial resistor for the background LED.
Of course iyou have to adapt the software for different displays. 
Also the hardware extension are possible with the Fish8840 board.\\

All attempt to replace the original software is allways done at one's own risk.
No guaranty can be given for operational capability of newer software versions.
Unfortunately the original state of the chinese software can not be saved because the 
security bits of the ATmega328 are set. So there is no way to get back to the original state.\\

A additional version with graphical display is the WEI\_M8 printed board, which is shown in picture~\ref{fig:WeiM8}.
This build use a LiIon accumulator with AA (mignon) size as power supply, which can be loaded
with the micro USB plug. Operating is also possible without the accumulator, only with the USB power.

\begin{figure}[H]
\centering
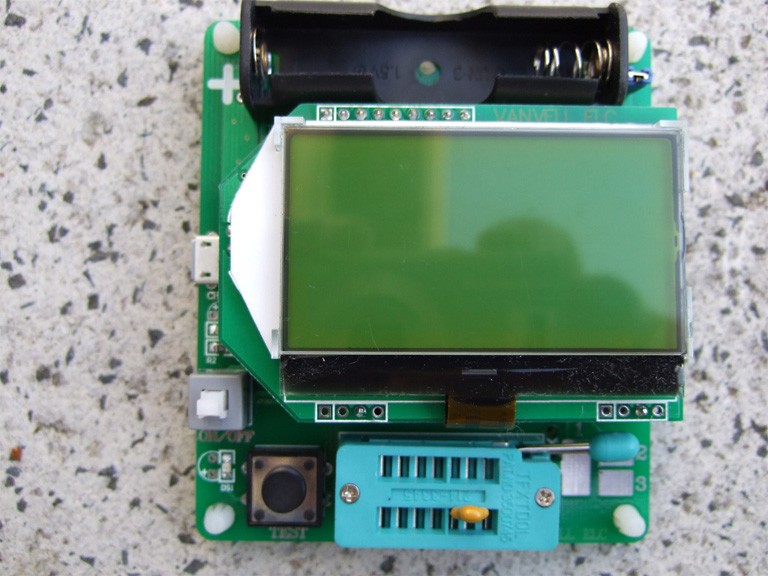
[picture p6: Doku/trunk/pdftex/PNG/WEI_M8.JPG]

\caption{Picture of the chinese WEI\_M8 tester}
\label{fig:WeiM8}
\end{figure}

It is pleasant, that the signal lines of the display are equipped with serial resistors
at the adapter board, as you can see in the left picture of~\ref{fig:WeiM8int}.
Therefore you must not be afraid that the \(5V\) signals of the ATmega can cause a excessive
increase of the \(3.3V\) power of the display controller.

\begin{figure}[H]
  \begin{subfigure}[b]{9cm}
    \centering
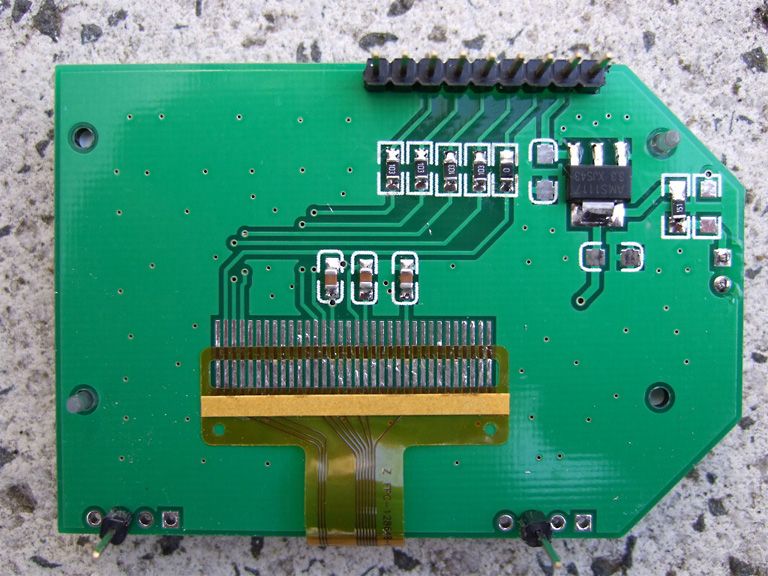
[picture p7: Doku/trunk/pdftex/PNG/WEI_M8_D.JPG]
    
    \caption{Adapter board for the display}
  \end{subfigure}
  ~
  \begin{subfigure}[b]{9cm}
    \centering
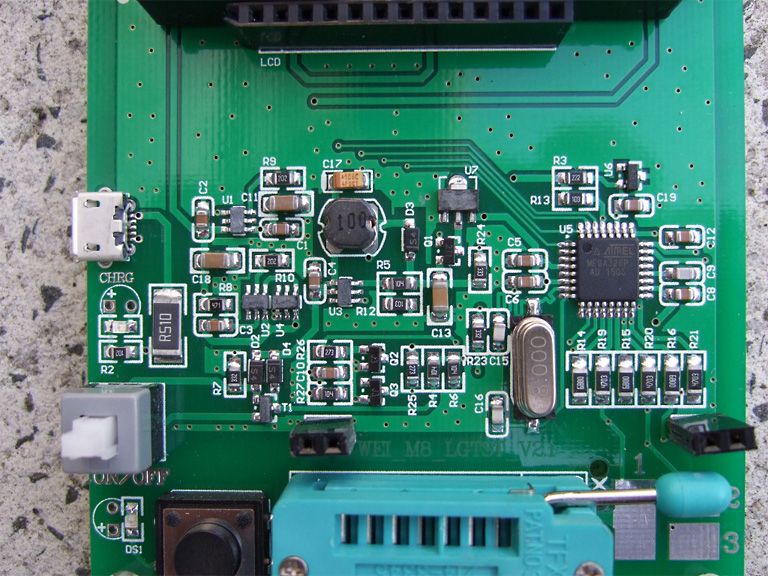
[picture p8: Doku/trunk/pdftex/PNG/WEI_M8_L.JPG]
    
    \caption{Base board}
  \end{subfigure}
  \caption{Inside look to the WEI\_M8 Testers}
  \label{fig:WeiM8int}
\end{figure}

With the upgrade to version 1.12k some problems has occured.
If the extended fuse is set to 0x04 (0xfc) as recommended, some measurements has
caused a ''Brown Out'' reset of the processor.
This resets are caused by short voltage drops of the VCC power.
I have added a additional \(4.7\mu F\) ceramic capacitor at the input side of
the voltage regulator and a \(10\mu F\) ceramic capacitor at the output side (VCC)
of the regulator.
Both before and after the upgrade I have noticed, that with bipolar transistors
a residual collector current (ICEO or ICEs) of about \(1\mu A\) was detected with this board.
Not until the unknown LDO voltage regulator was replaced with a MCP1702-5002 this
effect has disappeared. The figure \ref{fig:WeiM8mod} shows the modified board with
the slantwise mounted capacitors and the MCP1702 regulator.
If you don't wont to modify your board, you must set the extended fuse to 0x07 (0xff)
to enable a regular operation. With that setting the voltage drops remain undetected.

\begin{figure}[H]
\centering
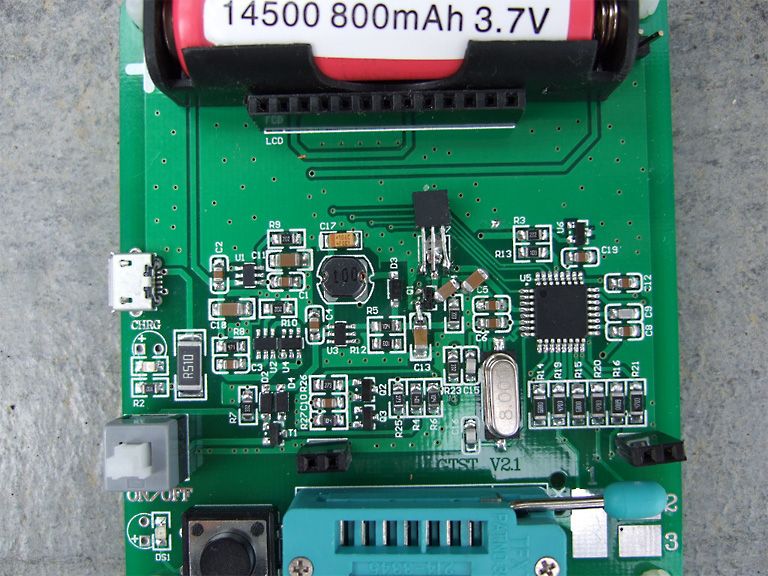
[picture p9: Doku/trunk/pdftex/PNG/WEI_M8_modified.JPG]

\caption{Picture of the modified WEI\_M8 Tester}
\label{fig:WeiM8mod}
\end{figure}

A additional chinese version with graphical display is the ''LCD-T4'' tester with a yellow 
printed board.
I have removed the display for replacing the software with a newer version.
At the right picture of figure~\ref{fig:T4_front} you can see in the right upper corner the ISP male connector
with correct orientation beside the six holes of the board.
For programming the ATmega I have not soldered the male connectorr. I have only pugged it into
the holes instead and have fixed it with a finger during the programming.
With that procedure the male connector can be easy removed an the display can be mounted again to
it's origin place.
The chinese software could be replaced with the 1.12k without any noticeable problem. 
Also the activating of the ''brown-out'' monitor by setting the extended fuse has not
shown any surprice.

\begin{figure}[H]
  \begin{subfigure}[b]{9cm}
    \centering
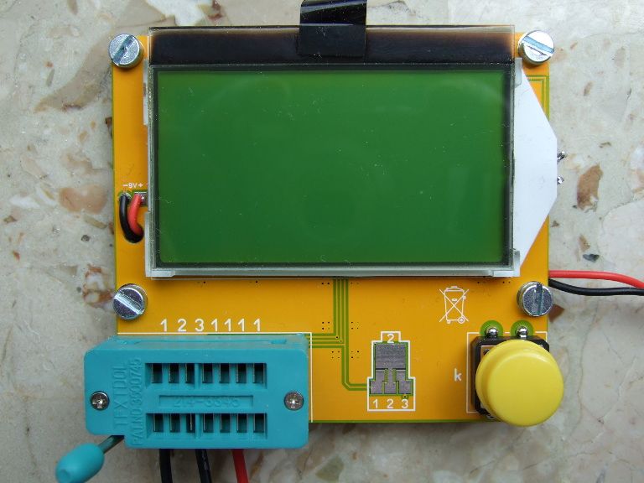
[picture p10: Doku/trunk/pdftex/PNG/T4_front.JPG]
    
    \caption{completely}
  \end{subfigure}
  ~
  \begin{subfigure}[b]{9cm}
    \centering
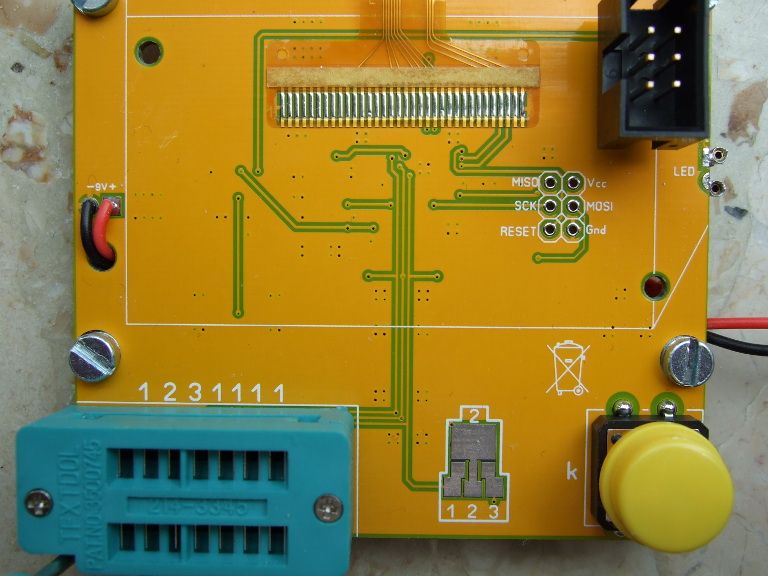
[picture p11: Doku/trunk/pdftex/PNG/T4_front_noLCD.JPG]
    
    \caption{with removed display}
  \end{subfigure}
  \caption{Front view of the T4 tester}
  \label{fig:T4_front}
\end{figure}

You can see the upgraded \(5mm\) threaded bolt and the upgraded cables with measurement clips
at the pictures of the back side in figure \ref{fig:T4_back}.
Because the data signals for the graphical LCD controller have also no
level adaption (\(5V\) -\textgreater~\(3.3V\)), the setting of the option LCD\_SPI\_OPEN\_COL is recommended.
Due to the fact, that the board can not be easy upgraded with a ''pull-up'' resistor,
it make sense to remove the option PULLUP\_DISABLE instead. 
This board is lesser practical for later extensions, a replacement of the display is
also difficult to realize.

\begin{figure}[H]
  \begin{subfigure}[b]{9cm}
    \centering
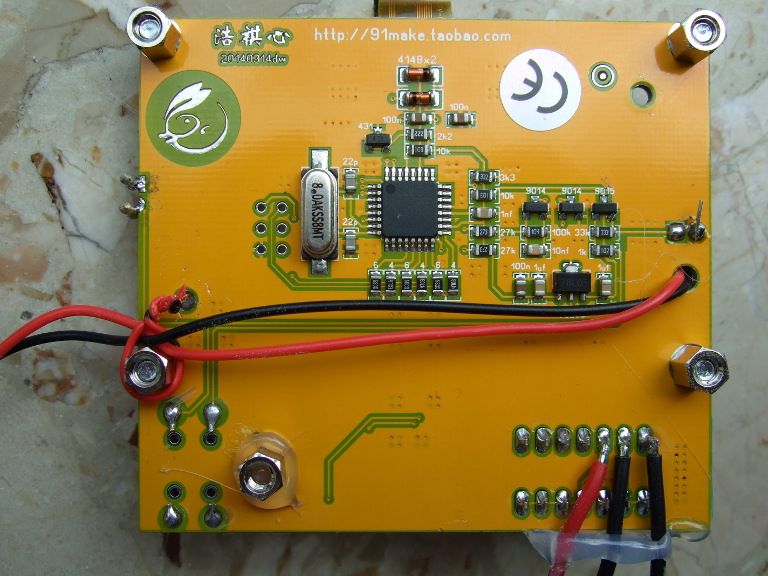
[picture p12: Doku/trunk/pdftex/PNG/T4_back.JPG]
    
    \caption{components side}
  \end{subfigure}
  ~
  \begin{subfigure}[b]{9cm}
    \centering
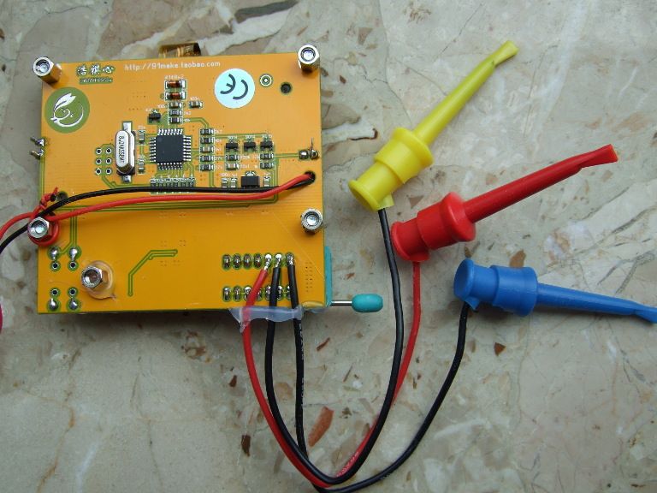
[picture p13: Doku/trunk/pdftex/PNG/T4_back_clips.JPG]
    
    \caption{with measurement cables}
  \end{subfigure}
  \caption{Back side of the T4 tester}
  \label{fig:T4_back}
\end{figure}

A additional chinese version with graphical display is offered with the name ''GM328''.
For this version the graphical display is connected with a adapter circuit board to the 16-pol female connector. 
The port PD5 of the ATmega is connected via pin 6 of the female connector to the CE (Chip Enable) input of the 
graphical controller.
The signal CE is also conneted at the adapter board to the \(0V\) power (GND).
This will resulte to a short-circuit if the ATmega will switch the PD5 output to \(5V\).
But newer versions of the software also switch the CE signal, even if the signal is not necessary for
correct operation.
For correct operation of the ''GM328'' tester with newer software versions you should cut the
connection of the CE signal to pin 6 of the male connector.

\section{Chinese kits with graphic displays}

Two different kit versions with graphical display and rotary encoder are known until now.
The first released kit use a display with a ST7565 or compatible controller (128x64 pixels).
In addition to the rotary encoder a additional input for frequency measurement is provided.
For the test ports a 14-pin Textool socket, three soldering pads for cables and a testpad
for SMD parts are provided at the main board.
The pictures~\ref{fig:Kit_mono} shows the mounted kid.
One of the both \(22 pF\) capacitors was replaced with a trimmer at the soldering side.
With a trimmer the frequency of the crystal can be adjusted for better accuracy of frequency measurement
and frequency generation. 

\begin{figure}[H]
  \begin{subfigure}[b]{9cm}
    \centering
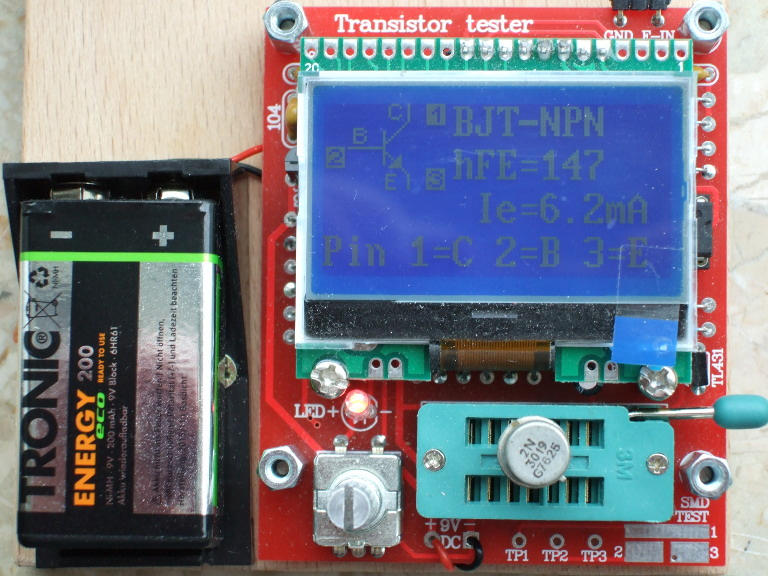
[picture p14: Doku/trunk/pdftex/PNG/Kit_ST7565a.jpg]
    
    \caption{build together}
  \end{subfigure}
  ~
  \begin{subfigure}[b]{9cm}
    \centering
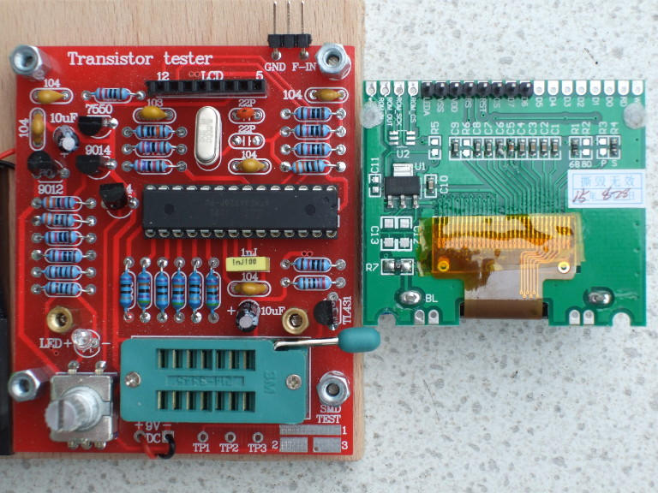
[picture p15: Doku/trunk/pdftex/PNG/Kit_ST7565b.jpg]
    
    \caption{with dismounted display}
  \end{subfigure}
  \caption{Assembled kit with 128x64 pixel display}
  \label{fig:Kit_mono}
\end{figure}

The later released kit use a color display with a ST7735 controller (160x128 pixel)
and is additionally equipped with a input for voltage measurement and a terminal for frequency output.
But the frequency output terminal is not buffered, it is simply connected parallel to the TP2 terminal.
The voltage measurement can handle positiv DC voltages up to 50V. A additional DC-DC converter
for the measurement of Zener diodes is not provided. 
The pictures~\ref{fig:Kit_color} shows this assembled kit.
Also in this version was one of the both \(22 pF\) capacitors replaced
by a trimmer (green color).

\begin{figure}[H]
  \begin{subfigure}[b]{9cm}
    \centering
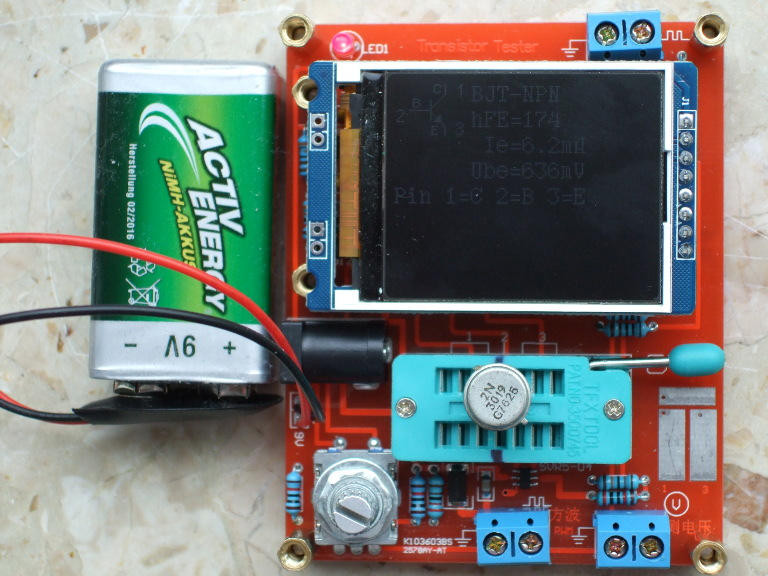
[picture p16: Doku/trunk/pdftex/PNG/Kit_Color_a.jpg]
    
    \caption{build together}
  \end{subfigure}
  ~
  \begin{subfigure}[b]{9cm}
    \centering
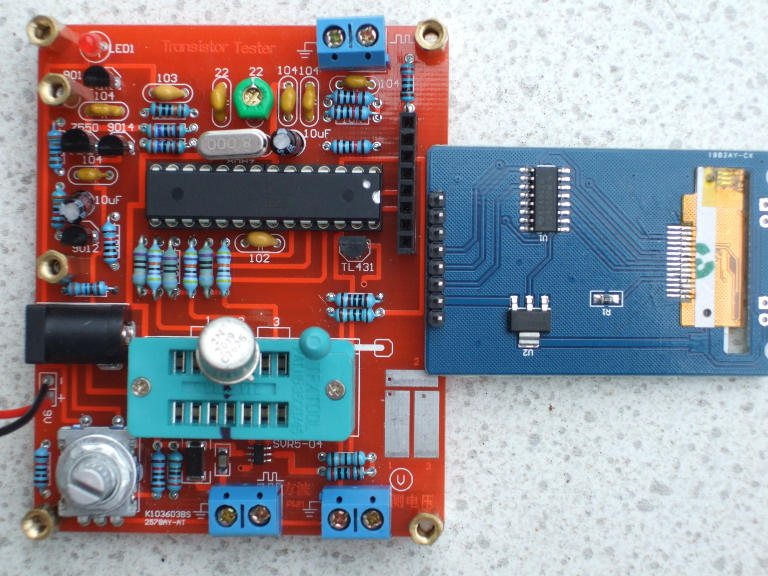
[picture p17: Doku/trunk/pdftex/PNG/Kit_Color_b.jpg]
    
    \caption{with dismounted display}
  \end{subfigure}
  \caption{Assembled kit with 160x128 pixel color display}
  \label{fig:Kit_color}
\end{figure}

Both kids use a DIP version of the ATmega328P mounted at a sockets and are
not equipped with a ISP connector for updating the ATmega with newer software versions.
The first version use
only leaded parts for the main circuit board. 
I have received measurement resistors \(680\Omega\) and \(470k\Omega\) with 0.1\% tolerance
with the Chinese kit. Also a \(220 nF\) capacitor for calibration was added
to the kit.
The kit with the color display was equipped with a connector for a DC power supply additionally
to the pads for the 9V battery.
Some few SMD parts was allready assembled at the main board, so that also only simple soldering
tasks are to do for this kit. 
A little disadvantage of the version with the color display is the speed of display output.
Especially for the menu handling the slower output speed will be noticed.
Otherwise the color display has a significant higher count of pixels, so more text can be shown at once.
Both kits use a 3.3V voltage regulator for the power of the display controller at the
full assembled display circuit boards.
Only the pin header must be soldered at the display circuit board.
The color version use a CD4050 buffer to adapt the different signal voltage levels.
I did not found any adaption of signal voltage levels at the board for the ST7565 version.
Probably the selected controller version tolerates the 5V signal levels of the ATmega328.
I could not find protection diodes at the input signals to the 3.3V supply side for this controller type.

\section{Extented circuit with ATmega644 or ATmega1284}

A extended circuit for ATmega644/1284 processors was developed with Nick L. from the Ukraine.
The circuit \ref{fig:t644tester} enables a additional test of crystals and a extended range
for the frequency measurement.
Although the basic circuit is very simular to the circuit \ref{fig:ttester}, the
port assignment is different.
A rotary pulse encoder with circuit \ref{fig:RotExt} can be connected here at the pins PB5 and PB7 (instead of PD1 and PD3).
Both signals and also the power signals VCC and GND are available at the ISP connector,
so that the extension can also be connected here.\\

The 16:1 frequency divider of the 74HC4060 is allways used for frequencies above \(2MHz\).
The frequency divider can also be used for frequencies between \(25kHz\) and \(400kHz\) to
upgrade the frequency resolution by using the period measurement.
For switching between the operational states (frequency divider and crystal oszillator)
the analog switches 74HC4052 are used.
The table \ref{tab:mega644-display} shows the pin assignments for the ATmega324/644/1284
microcontrollers for different display connections.
The using of the I\textsuperscript{2}C interface is only possible with the SSD1306 controller.
The signals of the I\textsuperscript{2}C interface require a pull-up resistor of \(4.7k\Omega\) to \(3.3V\).
The outputs of the ATmega is only switched to \(0V\) for the I\textsuperscript{2}C signals.

\begin{table}[H]
  \begin{center}
    \begin{tabular}{| c || c | c | c | c |}
    \hline
      Port & Character LCD &  Graphic LCD  & Graphic LCD  & additional function\\
           &               &  SPI 4-wire   &   I\textsuperscript{2}C        &            \\
    \hline
    \hline
    PB2    &  LCD-RS         &            &             &       \\
    \hline
    PB3    &  LCD-E          &  (LCD-CE)  &  LCD-SCL    &       \\
    \hline
    PB4    &  LCD-D4         &  LCD-REST  &  LCD-SDA    &       \\
    \hline
    PB5    &  LCD-D5         &  LCD-RS    &             & ISP-MOSI \\
           &                 &            &             & Rotary encoder 2 \\
    \hline
    PB6    &  LCD-D6         &  LCD-SCLK  &             & ISP-MISO \\
    \hline
    PB7    &  LCD-D7         &  LCD-SI    &             & ISP-SCK  \\
           &                 &            &             & Rotary encoder 1 \\
    \hline
    \end{tabular}
  \end{center}
  \caption{Different variations of the display port assignments}
  \label{tab:mega644-display}
\end{table}

You can also connect a display with the NT7108 (KS0108, S6B0108) controller to the ATmega644 or ATmega1284 by using
a little circuit as shown in figure~\ref{fig:NT7108lcd_644}.
You should also respect the different pin assignments of display modules with NT7108 controllers as 
shown in table~\ref{tab:NT7108types} at page~\pageref{tab:NT7108types}.

\begin{figure}[H]
  \begin{subfigure}[b]{9cm}
    \centering
    
    \caption{with 74HCT164}
  \end{subfigure}
  ~
  \begin{subfigure}[b]{9cm}
    \centering
    
    \caption{with 74HCT595}
  \end{subfigure}
  \caption{Connection of a NT7108 Controller to a ATmega644/1284}
  \label{fig:NT7108lcd_644}
\end{figure}

\begin{figure}[H]
\centering

\caption{Extended Transistor Tester circuit with ATmega644}
\label{fig:t644tester}
\end{figure}

\section{Buildup of a tester with ATmega1280 or Arduino Mega}
The basic circuit of the tester can also be also build with a Arduino Mega with a ATmega1280
or ATmega2560 microcontroller with a shield.
The required connections are shown in figure~\ref{fig:t1280tester}.
The names for the connections of the display signals of the Arduino are shown with green color.
Components with red color identification are not required for operating.
The ATmega2560 controller has many connectors, but only one connector has the required
functions for both techniques of the frequency measurement.
The connector must be used as clock input for a build in counter and must also be 
used as interrupt source for change of signal level.
This feature is only available for the pin PE6 (T3/INT6).
The other clock inputs of counters PD7 (T0), PD6 (T1), PH7 (T4) and PL2 (T5) can not be 
used as interrupt source for status change.
Unfortunately the PE6 pin is not connected to a pin of the Arduino female connector strip.
The PE5 pin (7) is connected to the connector 3 of the PWM socket strip and
can be jumpered with the PE6 pin (8) of the ATmega2560.
The output signal of the frequency generation is available at the PB6 (OC1B) pin.
This pin is connected to the connector 12 of the PWM socket strip.
The ISP-connector is not required, because the program can be loaded with the bootloader
and the USB interface to the ATmega. With the bootloader there is always a
little delay for the power up start of the program.

\begin{figure}[H]
\centering

\caption{TransistorTester circuit with ATmega1280, ATmega2560 or Arduino Mega}
\label{fig:t1280tester}
\end{figure}

Of course you can connect all supported displays also to the ATmega1280 or ATmega2560
as shown in table~\ref{tab:display-1280} .

\begin{table}[H]
  \begin{center}
    \begin{tabular}{| c || c | c | c | c | c | c |}
    \hline
           & Character     &  ST7565     & ST7920       & NT7108       & SSD1306     & additional function \\
      Port & LCD           &    SPI      & seriell      & seriell      &    I\textsuperscript{2}C      & \\
    \hline
    \hline
    PA0    &  LCD-D4       &   LCD-REST  &  LCD-RESET   & HC595-RCK      &             & \\
    \hline
    PA1    &  LCD-D5       &   LCD-RS    &              & LCD-CS2        &             & rotary encoder 2 \\
    \hline
    PA2    &  LCD-D6       &   LCD-SCLK  &              & HC164-CLK      &             & \\
    \hline
    PA3    &  LCD-D7       &   LCD-SI    &              & LCD-CS1        &             & rotary encoder 1 \\
    \hline
    PA4    &  LCD-RS       &             &   LCD-B0     & LCD-RS         &   LCD-SDA   & \\
           &               &             &              & HC164-SER      &             & \\
    \hline
    PA5    &  LCD-E        &   (LCD-CE)  &   LCD-EN     & LCD-EN         &   LCD--SCL  & \\
    \hline
    PA7    &  key signal   &             &              &                &             & \\
    \hline
    \end{tabular}
  \end{center}
  \caption{Connections for different display to the ATmega1280/2560 processors}
  \label{tab:display-1280}
\end{table}

\section{Programming of the microcontroller}
I release the software for the microcontroller with source code.
The developement is done with Linux operationg system (Ubuntu) and
is controlled with a Makefile. The Makefile makes sure, that your
software will be compiled with the prior selected Makefile options. Some constellations
are precompiled with the source. Please take a look to the ReadMe.txt file
in the directory Software/default and to the chapter~\ref{sec:config} at page~\pageref{sec:config}.
The result of compilation have the extensions .hex and .eep .
Usually the names will be TransistorTester.hex and TransistorTester.eep .
The .hex file contains the data for the program memory (flash) of the ATmega processor.
The .eep file contains the data for the EEprom memory of the ATmega. Both data files
must be loaded to the correct memory.

Additionally the operating state of the
ATmega processor must be programmed with the ``fuses''.
If you can use my Makefile and additionally the program avrdude \cite{avrdude}, you need no exact
knowledge of the details about the fuses. You have only to type ``make fuses'' if you
have no crystal or ``make fuses-crystal'' if you have installed the \(8MHz\) crystal to your printed board.
With the ATmega168 series of the microcontroller you can also use ``make fuses-crystal-lp'' to use
a crytal with the low power mode.
Never choose the crystal mode of clock generation, if you don't have installed
the \(8MHz\) crystal. If you are not sure with the fuses, leave them as default
set by manufactor and first bring the the tester to operation in this mode.
Maybe your program runs too slow, if you use program data compiled for
\(8MHz\) operation, but you can correct this later! But a wrong set of fuses may inhibit
later ISP-programming.

\subsection{Using the Makefile with Linux}
You can install packages with Debian based Linux versions by using a package manager as synaptic or dpkg.
The package ``subversion'' must be installed for downloading the sources or the documentation from the SVN archive.
With the command \\
``svn checkout svn://www.mikrocontroller.net/transistortester'' \\
you can download the complete archive.
Of course you can also download only subdirectories of the archive.
For using the Makefile in one of the subdirectories you must install the packages
make, binutils-avr, avrdude, avr-libc and gcc-avr.
Once you must prepare the access to the interfaces for the user.
If you open a consol window and you have also connected a ISP programmer with USB interface,
you can see the recognized USB devices with the command ''lsusb''.
A sample of the result of lsusb you can see here:
\begin{verbatim}
Bus 001 Device 001: ID 1d6b:0002 Linux Foundation 2.0 root hub
Bus 002 Device 003: ID 046d:c050 Logitech, Inc. RX 250 Optical Mouse
Bus 002 Device 058: ID 03eb:2104 Atmel Corp. AVR ISP mkII
Bus 002 Device 059: ID 2341:0042 Arduino SA Mega 2560 R3 (CDC ACM)
Bus 002 Device 001: ID 1d6b:0001 Linux Foundation 1.1 root hub
\end{verbatim}
A Device 58 is detected here a a AVR ISP mkII type (DIAMEX ALL-AVR).
The ID 03eb is a vendor ID and the ID 2104 is a product ID.
Both ID's are required for a entry in the file /etc/udev/rules.d/90-atmel.rules .
In this example the file 90-atmel.rules has one line:
\begin{verbatim}
SUBSYSTEM=="usb", ATTRS{idVendor}=="03eb", ATTRS{idProduct}=="2104", MODE="0660",
GROUP="plugdev"
\end{verbatim}
This entry allow the access to the USB device 58 for members of the group ''plugdev''.
The also detected USB device 59 allows a access to the serial device ''/dev/ttyACM0'' for
members of the group ''dialout''.

Therefore your user identification should be a member of the group plugdev and also
a member of the group dialout.
With the command ''usermod -a -G dialout,plugdev \$USER'' the membership of both groups should be established.
Now the program avrdude should have permission to access both devices.
In a console window you must first change the directory with the command ``cd'' to a proper
subdirectory of the directory trunk.
Now you can change options of the Makefile with any text editor.
For compiling the source you must only type the simple command ``make''.
If the ISP programmer is configured proper in the Makefile, a command ``make upload''
should result to load the program with the ISP interface to the ATmega.
The ``fuses'' of the ATmega must also be set correctly once.
You can achieve this with the command ``make fuses'' or ``make fuses-crystal''.
The program avrdude probably reports a error for setting the extended fuse efuse.
The reading of unused fuse bits is specified as ''1'' for the ATmega, but the
avrdude program mask the unused bits, so that it expect a ''0'' for all unused bits.
Normally the efuse should be set to 0xfc, but avrdude read back 0x04 with the mask.
You can change the file avrdude.conf to change the behaviour of avrdude or
you can set the efuse to 0x04. 
The value for all efuses can be set with the identifier EFUSE\_VAL at the begin of file setup.mk
in the trunk directory.
Probably the fuses are also set correctly with the error message.

\subsection{Using the WinAVR package with Windows}
If you use the Windows operating system, the easiest way to get a correct programmed
ATmega is to use the WinAVR package \cite{winavr1},\cite{winavr2}.
With my patch \cite{winavr3} you can also set the fuses by using the Makefile.
Of course the avrdude program must support your programmer and the configuration
in the Makefile must match to your environment.

The figures \ref{fig:WinAVR1} show the File menu of the graphical user interface of WinAVR for
open the file Makefile and for saving the changed Makefile (Save).

\begin{figure}[H]
  \begin{subfigure}[b]{9cm}
    \centering
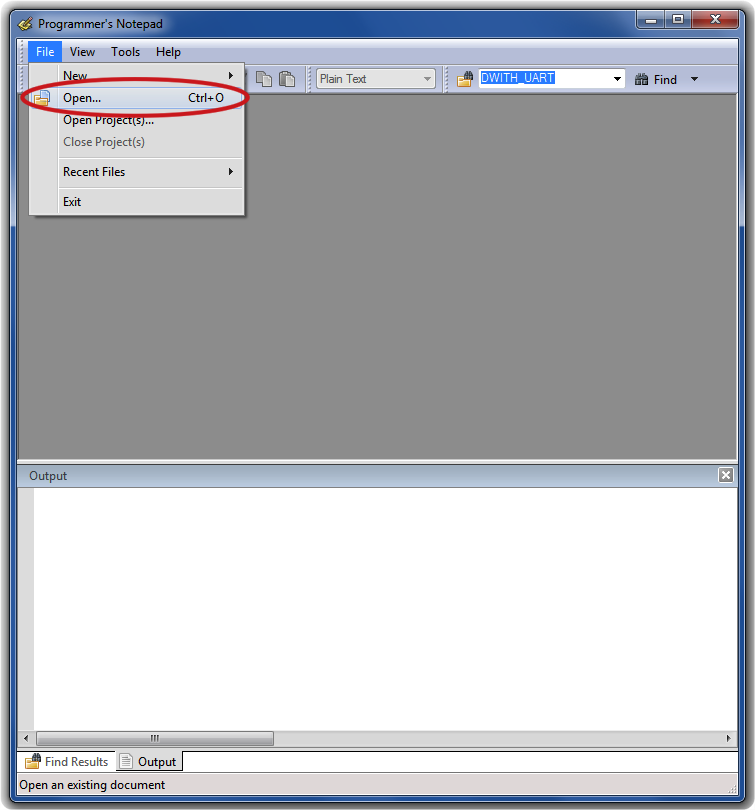
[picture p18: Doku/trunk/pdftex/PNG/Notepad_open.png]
    
    \caption{open Makefile}
  \end{subfigure}
  ~
  \begin{subfigure}[b]{9cm}
    \centering
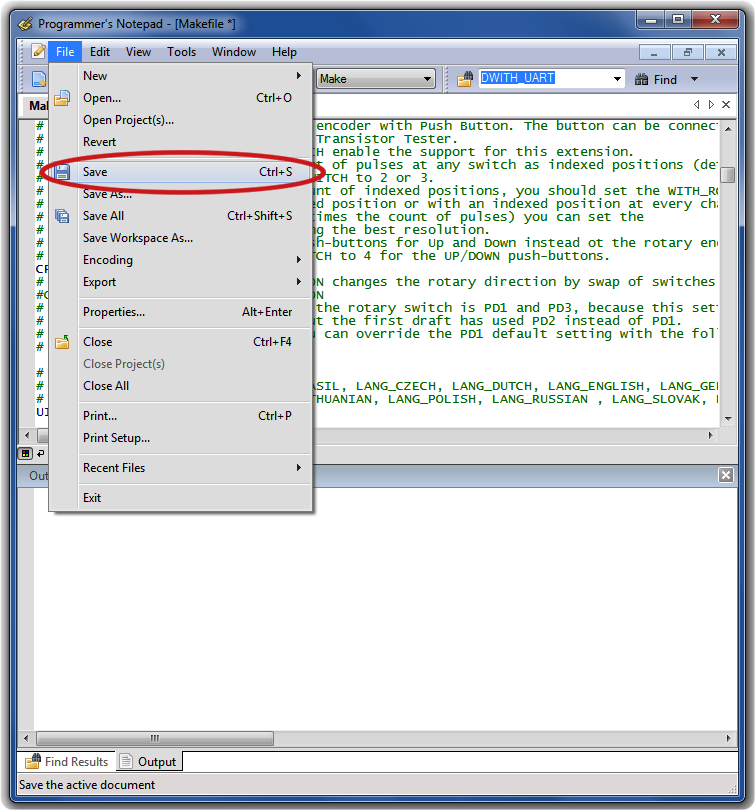
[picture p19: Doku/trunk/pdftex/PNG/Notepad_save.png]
    
    \caption{save Makefile}
  \end{subfigure}
  \caption{Using of the WinAVR user interface Programmer's Notepad}
  \label{fig:WinAVR1}
\end{figure}

The next figures \ref{fig:WinAVR2} show the Tools menu of the Programmer's Notepad
for compiling the program (Make All) and for programming the ATmega (Program) with avrdude.

\begin{figure}[H]
  \begin{subfigure}[b]{9cm}
    \centering
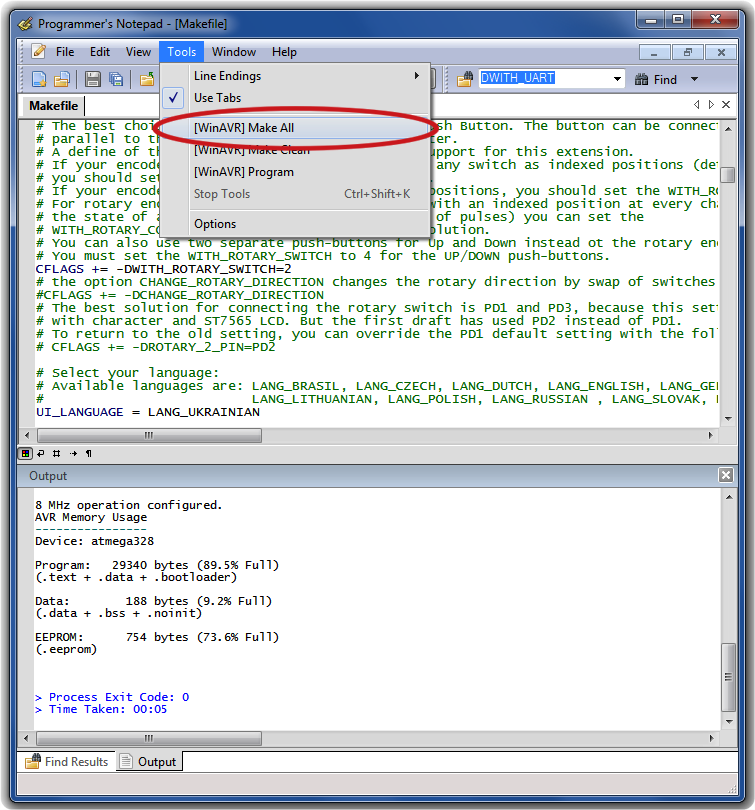
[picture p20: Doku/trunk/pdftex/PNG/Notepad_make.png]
    
    \caption{Build programming data (.hex/.eep)}
  \end{subfigure}
  ~
  \begin{subfigure}[b]{9cm}
    \centering
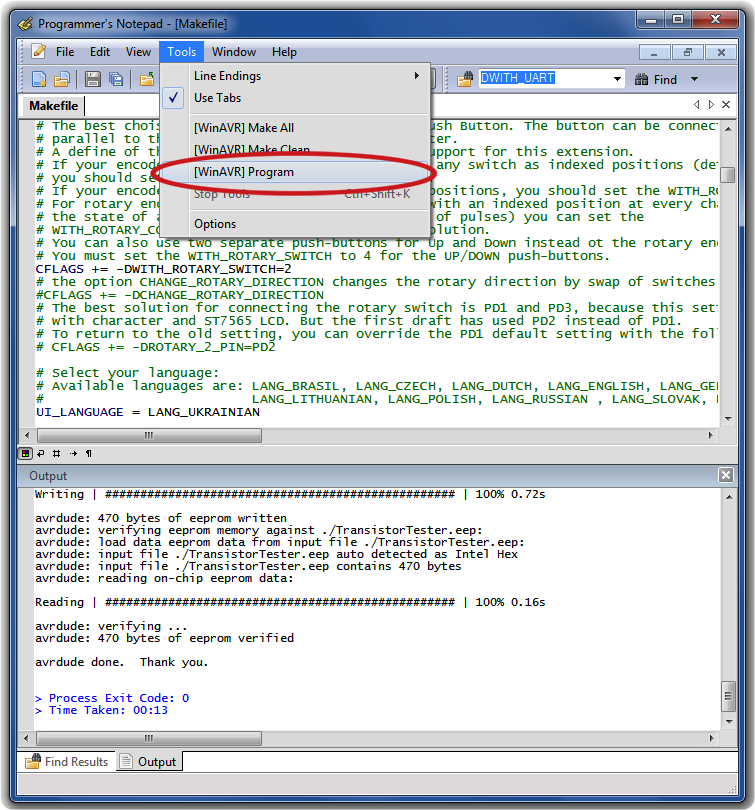
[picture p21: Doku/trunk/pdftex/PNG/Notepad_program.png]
    
    \caption{Programming the ATmega}
  \end{subfigure}
  \caption{Using of the WinAVR user interface Programmer's Notepad}
  \label{fig:WinAVR2}
\end{figure}

\section{Troubleshooting}
In most cases of problems you will miss the text output to the LCD-display.
At first you should check, if the LED was illuminated weak, if you release
the Test button. 
\begin{description}

\item[Power does not switch on.]
If the LED is without light and the VCC power has correct
\(5V\) voltage during holding the Test button, the microcontroller does not switch the power
correctly. The microcontroller should hold the power by switching the
PD6 output to \(5V\), which is usually done as one of the first actions.
If you hold the Test key pressed, the power is switched on anyway.
So you can check the value of VCC power and additionally the voltage value
of the PD6 output, if you hold the key pressed.
If VCC voltage has correct value (\(5V\)), but PD6 voltage is
below \(4V\), your microcontroller does not start the program. In this case
you should check if the microcontroller flash has been loaded with proper data for your
installed type and if ATmega is correctly configured with the fuses.
If your ATmega put the PD6 output to \(5V\) and the power does not stay if you
release the Test key, it is more difficult to find the reason.
First you can shorten the LED and try again. If your Tester now starts,
your LED may be faulty or mounted with wrong polarity. If this is not
the reason, the current amplification factor of your T3 transistor (BC557C)
is insufficient. The current to the base of T3 is lower in the microcontroller
state as in the ``key pressed'' state.

\item[Nothing is readable on the LCD display]
Check the voltage at the contrast pin at the LCD display (pin 3). Adjust to
correct value specified in the data sheet of your display and optimize by viewing.
If you have a high temperature display type, you must provide a negative contrast voltage
for operation. In this case you can use the ICL~7660 device for generating
a negative voltage from positive \(5V\).

The tester software can be configured for many different controller with different connection
types. You should check, if your software matches to your mounted display type.
If there is no output readable on the LCD and the background light is on,
you should disconnect the power and check all four data plus the two control signal connections.
If all connection are well, the only reason I see is a uncorrect timing of
control signals. This can be caused by a slower LCD controller than expected by
the software or the ATmega software runs at wrong clock speed. Please check for which
clock speed your programming data was compiled  and if the fuses of the
ATmega are correct set to that speed. You find the clock parameter in the corresponding
Makefile.
If the tester is build without the switch off electronic, you can test with
a LED connected to the test pins, if the program operates normally.
If the LED flickers, the program operates well. The missing text on the
LCD must be caused by wrong connection or timing.
For some graphical displays the contrast is changeable with a menu function.
If you have changed the contrast value, that nothing is readable at the screen,
you cannot handle the menu function any more. You can try to read the display
from a slanting look to the display, not from the front side.
In this case you can try to handle the menu function with this view.
Otherwise you can write the EEprom data new with a ISP programmer to reset the contrast value.

\item[Something but not all is readable on the LCD display]
Check if the .eep data are loaded to the EEprom memory of ATmega.
If all data are loaded correctly, you should check the clock speed of your
programming data (Makefile) and ATmega processor settings (fuses).

\item[Measurement is slow and Capacitors are measured about 8 times too small]
You run software compiled for \(8MHz\) clock at real clock speed of \(1MHz\).
Please set the fuses of the ATmega correctly.

\item[Measurement has strangely values]
Check if your programmer is still connected to the ISP-plug.
The ISP interface should be disconnected for measuring.
Very often the reason of wrong measurements is the use of software compiled with
the AUTOSCALE\_ADC option and with the option NO\_REF\_CAP, but the capacitor
at the AREF pin has still a value of \(100nF\).
Wrong assembly of components or remaining soft solder flux can disturb the 
measurements too. Please check with the selftest function of your TransistorTester software
if possible. For the details see Chapter \ref{sec:selftest}.

Otherwise inspect your board visually and check the resistor values
with a ohmmeter. You can use the pins of the ATmega for this check, for example
to check the R1 you can measure between pin 23 and pin 14. Take a look at the
circuit diagram \ref{fig:ttester} for details. There is no need to
remove the microcontroller, only battery or power supply should be removed before.

\item[The Tester switch off the power after 2 seconds display time] 
This condition exists, if the external Pull-Up resistor at the PD7 input
is missing or the key button is keep pressed.
The software switch off the internal Pull-Up resistors to prevent a influence
to the measurement results. Therefore a external Pull-Up resistor (27k) is required.

\item[Der Tester shows only Vext=xx.xV in row 2]
This problem exists, if the Pull-Up resistor at the PD7 input
is missing or the key button is keep pressed.
Additionally the software is configured without the serial output (without option WITH\_UART) and
without the internal Pull-Up resistors (with option PULLUP\_DISABLE).
You should install the Pull-Up resistor at pin PD7.

\end{description}

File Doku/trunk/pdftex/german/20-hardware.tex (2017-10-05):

\chapter{Hardware}

\section{Die Schaltung des TransistorTesters}
\label{sec:hardware}
Die Schaltung des TransistorTesters in Abbildung~\ref{fig:ttester} basiert auf der Schaltung von
Markus F., die er in Abb. 1 des AVR-Transistortester Reports \cite{Frejek} veröffentlicht hat.
Geänderte oder verschobene Bauteile sind mit \textcolor{green}{grüner Farbe} markiert, optionale Teile sind
mit \textcolor{red}{roter Farbe} gekennzeichnet.

Einige Änderungen wurden gemacht, weil die Strom-Abschaltung in einigen Nachbauten Probleme
bereitet hatte.
Deshalb ist der Widerstand R7 auf \(3,3k\Omega\) reduziert. 
Der Kondensator C2 ist auf 10nF verkleinert und der Widerstand R8 ist verschoben, so dass der
Ausgang PD6 nicht versucht, den C2-Kondensator direkt zu laden.
Zusätzliche Abblock-Kondensatoren wurden hinzugefügt und sollten nahe den Versorgungs-Anschlüssen
des ATmega und nahe bei dem Spannungsregler plaziert werden.

Weil der PD7-Eingang und der PC6-Anschluss (RESET) die einzigen Anschlüsse sind, wo
,,pull-up'' Widerstände gebraucht werden, wurde ein zusätzlicher \(27k\Omega\) Widerstand am PD7 (Pin 13) vorgesehen.
Mit dieser Änderung können die internen ,,Pull-Up''-Widerstände des ATmega abgeschaltet werden.

Ein Quarz mit seinen \(22pF\)-Kondensatoren wurde zusätzlich vorgesehen.
Ein Quarz hat Vorteile für die Kapazitätsmessung wegen der genaueren Zeitmessung.

Die neue Software kann den Spannungsbereich für den ADC umschalten. Die Um\-schalt-Ge\-schwin\-dig\-keit
wird durch den externen Kondensator C1 am AREF-Pin (21) des ATmega reduziert.
Um die Messung nicht langsamer als notwendig machen zu müssen, sollte der Kondensator auf
1nF reduziert werden. Ein Entfernen des Kondensators ist ebenfalls möglich.
Zum Anpassen der Software an die jeweilige Schaltung schauen Sie bitte in dem
Kon\-fi\-gura\-tions-Kapitel~\ref{sec:config} ab Seite~\pageref{sec:config} nach. 

Einige unterschiedliche Kombinationen von R11 / R12 zirkulieren im Internet.
Ich habe die Software an den Original-Entwurf von Markus F.~\cite{Frejek} mit \(10k\Omega\) und \(3,3k\Omega\) angepasst.
Da Spannungsverhältnis kann in der Makefile angepaßt werden.

Die zusätzliche \(2,5V\) Präzisions-Spannungsreferenz, die an Pin PC4 (ADC4) angeschlossen ist,
wird für die Überprüfung und Kalibration der VCC-Versorgungsspannung benutzt, ist aber nicht
erforderlich.
Sie können eine LM4040-AIZ2.5 (0,1\%),
eine LT1004CZ-2.5 (0,8\%) oder eine LM336-Z2.5 (0,8\%) Spannungsreferenz benutzen.
Wenn sie weder die Präzisionsreferenz noch die Relais-Erweiterung zum Schutz der Eingänge benutzen,
sollten Sie wenigstens einen ,,Pull Up''-Widerstand R16 an PC4 installieren mit einem
höheren Widerstandswert (\(47k\Omega\)).
Dies hilft der Software, die fehlende Spannungsreferenz zu entdecken.
Ein zusätzlicher ISP-Anschluss wurde hinzugefügt, um leichter neue Software-Versionen
laden zu können.

\begin{figure}[H]
\centering

\caption{Neue TransistorTester-Schaltung}
\label{fig:ttester}
\end{figure}

Die Tabelle~\ref{tab:display-con} zeigt die Belegung des PD Ports für verschiedene Display-Versionen
und die Belegung der Zusatzfunktionen.
Bei allen Varianten dieser Tabelle sollten die Zusatzfunktionen möglich sein.
Das Signal LCD-CE bei der SPI Schnittstelle ist am ATmega-Port verfügbar. Der Eingang CE (Chip Enable) des
Controllers kann aber auch fest auf GND gelegt werden anstelle mit dem LCD-CE Ausgang des ATmega verbunden zu werden.

\begin{table}[H]
  \begin{center}
    \begin{tabular}{| c || c | c | c | c | c | c |}
    \hline
           & Character     & ST7565 LCD & ST7920 LCD     & NT7108 LCD  & SSD1306     & Zusatzfunktion \\
      Port & LCD           &   SPI      & serial         & serial      &   I\textsuperscript{2}C      & \\
    \hline
    \hline
    PD0    &  LCD-D4       &  LCD-REST  & LCD-REST       & 595-PCLK        &            & \\
    \hline
    PD1    &  LCD-D5       &  LCD-RS    &                & LCD-CS2     &             & Drehgeber-2 \\
    \hline
    PD2    &  LCD-D6       &  LCD-SCLK  & LCD-B0         & 164-595-CLK &  LCD-SDA    & \\
    \hline
    PD3    &  LCD-D7       &  LCD-SI    &                & LCD-CS1     &             & Drehgeber-1 \\
    \hline
    PD4    &  LCD-RS       &            &                & LCD-RS      &             & Frequenzzähler \\
           &               &            &                & 164-595-SER &             &                \\
    \hline
    PD5    &  LCD-E        &  (LCD-CE)  & LCD-EN         & LCD-EN      &   LCD--SCL  & \\
    \hline
    PD7    & Tastensignal & Tastensignal & Tastensignal  & Tastensignal & Tastensignal & \\
    \hline
    \end{tabular}
  \end{center}
  \caption{Pinbelegung für verschiedene Displays}
  \label{tab:display-con}
\end{table}

Um einen einfacheren Anschluss des Displays an den ATmega auf Streifenleiterplatinen zu erreichen,
kann die Software auch eine andere Port-D-Belegung berücksichtigen.
Die folgende Tabelle \ref{tab:grid-change} zeigt die Änderungen der Pinbelegungen für ein Textdisplay und 
alternative Anschlüsse für graphische Displays bei einem ATmega328 Mikrocontroller.
Außerdem werden die Belegungen der Port-Eingänge für zusätzliche Funktionen gezeigt. 
Bei der Belegung für das grafische Display mit der Streifenraster-Option (STRIP\_GRID\_BOARD=1)
kann die Frequenzzähler-Funktion nicht benutzt werden, da diese den Port PD4 (T0) benutzt.
Diese Belegung wird aber von einer chinesischen Version mit graphischem Display benutzt.
In den meisten Fällen sind die Platinenversionen mit einem Textdisplay für die Nachrüstung der
Frequenzzähler Funktion und der Drehgeber Option besser geeignet, weil die erforderlichen
Signale am Displayanschluß zur Verfügung stehen. 

\begin{table}[H]
  \begin{center}
    \begin{tabular}{| c || c | c | c | c |}
    \hline
           & Char. LCD      & ST7565 LCD     & ST7565 LCD   & Zusatzfunktion \\
      Port &    =1          &    =1          &    =5        &  \\
    \hline
    \hline
    PD0    &  Tastensignal  &                &              &  \\
    \hline
    PD1    &  LCD-D7        & LCD-SI         &  LCD-A0 (RS) &  Drehgeber-2 \\
    \hline
    PD2    &  LCD-D6        & LCD-SCLK       &  LCD-REST    &  \\
    \hline
    PD3    &  LCD-D5        & LCD-A0 (RS)    &  LCD-SCLK    &  Drehgeber-1 \\
    \hline
    PD4    &  LCD-D4        & LCD-REST       &  LCD-SI      &  Frequenzzähler \\
    \hline
    PD5    &  LCD-E         & (LCD-CE)       &              &  \\
    \hline
    PD7    & LCD-RS         & Tastensignal   & Tastensignal &  \\
    \hline
    \end{tabular}
  \end{center}
  \caption{Alternative Pinbelegungen mit der Option STRIP\_GRID\_BOARD}
  \label{tab:grid-change}
\end{table}

\section{Erweiterungen für den TransistorTester}

\subsection{Schutz der ATmega-Eingänge}  

Zum besseren Schutz der ATmega-Eingänge kann eine Erweiterung mit einem Relais oder mit Dioden
nach Schaltbild~\ref{fig:relay_addon} angeschlossen werden.
Die Ruhekontakte des Relais schützen den ATmega im spannungslosen Zustand.
Die Konkakte werden von der Software nur für die Messung freigegeben.
Auch der Einbau von einem Überspannungsschutz mit Dioden verbessert die Chancen des ATmega
den Anschluss eines Kondensators mit höherer Restspannung zu überleben.
Ein vollständiger Schutz ist aber nicht möglich. Deshalb sollten Kondensatoren vor dem Messen immer
entladen werden.

\begin{figure}[H]
  \begin{subfigure}[b]{9cm}
    \centering
    
    \caption{mit Relais}
  \end{subfigure}
  ~
  \begin{subfigure}[b]{9cm}
    \centering
    
    \caption{mit Dioden}
  \end{subfigure}
  \caption{Zusätzlicher Schutz der ATmega-Eingänge}
  \label{fig:relay_addon}
\end{figure}

Ein noch besserer Schutz ist mit einem Relais mit 3 Umschaltkontakten nach Abbildung~\ref{fig:relay_um_addon} möglich.
Der Entladestrom wird hier durch Widerstände begrenzt und die ATmega-Eingänge sind im geschützten Zustand getrennt.
Man darf aber nicht vergessen, daß der Tester während der Messung trotzdem ungeschützt bleibt.

\begin{figure}[H]
\centering

\caption{Verbesserter Schutz mit Relais}
\label{fig:relay_um_addon}
\end{figure}

\subsection{Zenerspannungsmessung}

Wenn die Ausgabe der seriellen Texte nicht gebraucht wird, kann der Pin PC3 des ATmega für die Messung
einer externen Spannung benutzt werden. Die Spannung kann mit dem optionalen 10:1-Widerstandsteiler
bis zu \(50V\) betragen und kann für die Messung der Zenerspannung einer Diode benutzt werden.
Ein Strombegrenzendes Netzteil mit bis zu \(50V\) Ausgangsspannung kann mit dem \(0V\)-Signal des ATmega PD7-Pins
eingeschaltet werden, um zum Beispiel die Durchbruchspannung von Zenerdioden zu messen.
Einen Vorschlag für diese Erweiterung zeigt Abbildung~\ref{fig:zener}.
Der Tester zeigt die externe Spannung so lange an, wie man den Taster gedrückt läßt.
Ungefähr \(40mA\) mehr Batteriestrom wird für diese Erweiterung bei gedrückter Taste gebraucht.

\begin{figure}[H]
\centering

\caption{Erweiterung zum Messen von Zenerspannungen}
\label{fig:zener}
\end{figure}

Der 10:1-Spannungsteiler kann mit dem optionalen Dialogteil für den ATmega328 auch ohne 
den Spannungswandler benutzt werden. Ohne die gedrückte Taste ist der Spannungswandler nicht in 
Betrieb, sodass eine externe Spannung (z.B. Batteriespannung) am Zenerdioden-Port gemessen werden kann.
Es können nur positive Gleichspannungen bis \(50V\) gemessen werden.
Man muss also auf die richtige Polarität achten.

\subsection{Frequenzgenerator}

Mit dem Dialogteil des ATmega kann außerdem ein Frequenzgenerator angewählt werden, der derzeit
Frequenzen von \(2MHz\) bis \(1Hz\) ausgeben kann. Der Ausgang des \(5V\)-Signals erfolgt über
einen \(680\Omega\)-Widerstand auf den Testport TP2. Als Massesignal kann der Minus-Anschluss
der Zenerdiodenerweiterung oder Anschluss TP1 benutzt werden.
Auch TP3 ist über den \(680\Omega\) Widerstand mit Masse verbunden.
Natürlich kann an den ATmega-Port PB2 auch eine Schaltung zum Verstärken des Ausgangssignals 
für einen getrennten Ausgang angeschlossen werden. Dabei sollte der Eingang dieser Schaltung
aber keine hohe kapazitive Last für den ATmega-Ausgang darstellen.

\subsection{Frequenzzähler}
\label{sec:frequency_counter}

Für die ebenfalls über die Dialogfunktion wählbare Frequenz-Messung ist eine kleine Erweiterung
der Schaltung erforderlich. Als Eingang für die Frequenzmessung wird der PD4-Pin (T0/PCINT20) des
ATmega benutzt. Der gleiche Pin wird auch zum Anschluss des LCD benutzt. Bei dem normalen Layout
ist dies LCD-RS, beim Streifenraster-Layout ist dies LCD-D4. Für beide Signale kann der PD4-Pin
auf Eingang geschaltet werden und für die Messung benutzt werden, solange keine Ausgabe auf das
LCD erfolgt. Das LCD interessiert sich für das Signal nur, wenn LCD-E auf GND geschaltet wird.
Für die Einspeisung des Testsignals ist mindestens ein Serienwiderstand von \(270\Omega\) erforderlich.
Besser ist eine Schaltung nach Abbildung~\ref{fig:FreqMes} zu benutzen. Die Spannung am PD4-Pin (LCD-RS oder
LCD-D4) sollte ohne eingesteckten ATmega oder im Frequenz-Messbetrieb auf etwa \(2,4V\) eingestellt sein,
damit die größte Empfindlichkeit für das Eingangssignal erzielt wird. Das LCD sollte aber eingesteckt sein,
weil dessen Pull-Up Widerstände die Spannung verändern.

\begin{figure}[H]
\centering

\caption{Erweiterung zum Messen von Frequenzen}
\label{fig:FreqMes}
\end{figure}

\subsection{Impulsdrehgeber}

Zur leichteren Bedienung der Menüfunktion für den ATmega328 kann die Schaltung um einen
Impulsdrehgeber mit Taster erweitert werden. Die Schaltung~\ref{fig:RotExt} gibt die Standard-Belegung
für ein normales LCD an. Alle Anschlüsse für den Impulsdrehgeber sind an der Steckerleiste für das LCD 
verfügbar. 
Deswegen kann der Impulsdrehgeber in vielen Fällen leicht nachgerüstet werden. 
Vielfach ist das graphische Display auch mit einem Adapter-Board an die Steckerleiste des LCD angeschlossen. 
Deswegen ist auch hier die Nachrüstung des Impulsdrehgebers nicht sehr schwierig.

\begin{figure}[H]
\centering

\caption{Erweiterung um einen Impulsdrehgeber}
\label{fig:RotExt}
\end{figure}

Die Abbildung~\ref{fig:RotEnc} zeigt zwei Versionen von Drehgebern.
Die Version 1 hat doppelt so viele Raststellungen (detent) pro Umdrehung
wie Pulse pro Umdrehung.
Die Version 2 hat gleich viele Pulse pro Umdrehung wie Raststellungen.
Manchmal liegt bei einigen Drehgebern die Schaltflanke eines der beiden Schalter genau an der
Raststellung.

\begin{figure}[H]
\centering

\caption{Zwei unterschiedliche Versionen eines Impulsdrehgeber}
\label{fig:RotEnc}
\end{figure}

Die Abbildung~\ref{fig:RotBounce} zeigt einen Impulsdrehgeber, der nicht nur
prellende Kontakte hat, sondern auch an den Raststellungen (detent) einen unsicheren Zustand
eines der Kontakte besitzt. Jeder Wechsel eines Schalterzustandes wird vom Programm 
überwacht und in einem zyklischen Puffer gespeichert. Damit kann bei einem Wechsel des
Zustandes auch die beiden vorigen Zustände geprüft werden.
Insgesamt können für einen Zyklus der Schaltzustände vier Zustandsfolgen für jede Drehrichtung
festgelegt werden. Wenn nur eine Raststellung pro Zyklus vorhanden ist, reicht die Abfrage eines
Paares dieser Zustandsfolgen für das Zählen der Raststellung in beide Richtungen aus (WITH\_ROTARY\_SWITCH=2 oder 3).
Bei zwei Raststellungen, wie in der Abbildung~\ref{fig:RotBounce} gezeigt ist,
müssen zwei Paare abgefragt werden (WITH\_ROTARY\_SWITCH=1).
Für Impulsdrehgeber ohne Rasterung kann die Einstellung für WITH\_ROTARY\_SWITCH beliebig auf
2 oder 3 für die niedrigste Empfindlichkeit, auf 1 für eine mittlere Empfindlichkeit und auf 5 für
die höchste Empfindlichkeit gesetzt werden. 
Ein Pendeln der Einstellung (Zähler rauf, Zähler runter) wird durch die Art der Abfrage vermieden, bei
ungünstiger Lage der Schaltflanken kann aber ein Zählpuls für eine Raststellung ausbleiben.

\begin{figure}[H]
\centering

\caption{Ein Impulsdrehgeber mit prellenden Kontakten}
\label{fig:RotBounce}
\end{figure}

Anstelle der beiden Kontakte für den Impulsdrehgeber können auch zwei Taster für Rauf (Up) und Runter (Down)
eingebaut werden, wenn kein Impulsdrehgeber vorhanden oder gewünscht ist.
Für diesen Fall muss die Option WITH\_ROTARY\_SWITCH auf 4 gesetzt werden, damit das Programm
entsprechend reagiert.

\subsection{Anschluss eines graphischen Displays}

Dank der Arbeit von Wolfgang Sch. für die Unterstützung der chinesischen Version mit
grafischem 128x64 Pixel LCD, kann mittlerweile auch ein grafisches LCD
mit ST7565-Controller angeschlossen werden. Da der ST7565-Controller seriell angesteuert wird,
werden nur vier Signalleitungen benötigt.
Dadurch werden zwei Pinne des Port D für andere Verwendung frei.
Der ATmega-Prozessor sollte mindestens 32k Flash-Speicher besitzen.
Der ST7565-Controller wird mit einer Betriebsspannung von \(3,3V\) betrieben.
Deswegen ist ein zusätzlicher Spannungsregler notwendig.
Nach dem Controller Datenblatt dürfen keine \(5V\) Signale direkt mit den Controller-Eingängen verbunden
werden. Deshalb ist in der Erweiterung nach Bild \ref{fig:ST7565lcd} ein zusätzlicher CMOS 74HC4050
für die Pegelanpassung vorgesehen. 
Man kann auch versuchen, die vier Gatter des 74HC4050 durch vier Widerstände von etwa \(2,7k\Omega\) zu ersetzen.
Über den Spannungsabfall an den Widerständen wird verhindert, dass die \(3,3V\)-Versorgung des Controllers über die Schutzdioden
der Controllereingänge von den \(5V\) ATmega-Ausgängen über die \(3,3V\)-Grenze angehoben werden kann.
Ob die Signalform für den ST7565-Controller so noch akzeptiert wird, sollte man vorher testen.
Mit den Gattern des 74HC4050 bleibt die Signalform jedenfalls besser erhalten.\\
 
\begin{figure}[H]
\centering

\caption{Anschluss eines graphischen Displays mit ST7565 Controller}
\label{fig:ST7565lcd}
\end{figure}

Die Tabelle \ref{tab:spi-processor} zeigt weitere Anschlußmöglichkeiten
für den ATmega328 und andere Prozessoren mit der SPI (LCD\_INTERFACE\_MODE=4)
oder der 3LINE (LCD\_INTERFACE\_MODE=3) Schnittstelle. Verschiedene Belegungen für
einen Prozessor werden mit der Makefile Option STRIP\_GRID\_BOARD
eingestellt.
Die Belegungen sind in der Datei config.h festgelegt. 
Wenn weitere Varianten der Belegung erforderlich sind, sollten diese
mit weiteren Kennziffern der Option STRIP\_GRID\_BOARD auswählbar sein
und in config.h ergänzt werden.

\begin{table}[H]
  \begin{center}
    \begin{tabular}{| c || c | c | c | c | c | c | c |}
    \hline
 Processor  & m644  & m1280 & m1280  & m328 & m328 & m328 & m328 \\
STRIP\_GRID\_BOARD &       &   -   &   1    &  -   &  1   &  2   &  5   \\
    \hline
    \hline
Signal:     &       &       &        &      &      &      &      \\
  RES       &  PB4  & PA0   &  PA4   & PD0  & PD4  & PD0  & PD2 \\
    \hline
  EN, CLK   &  PB6  & PA2   &  PA2   & PD2  & PD2  & PD2  & PD3 \\
    \hline
  RS, D/C   &  PB5  & PA1   &  PA3   & PD1  & PD3  & PD3  & PD1 \\
    \hline
  B0, MOSI  &  PB7  & PA3   &  PA1   & PD3  & PD1  & PD1  & PD4 \\
    \hline
  CE, CS    &  PB3  & PA4   &  PA5   & PD5  & PD5  & PD5  & PD5 \\
    \hline
    \end{tabular}
  \end{center}
  \caption{SPI Anschlußbelegungen für verschiedene Prozessoren}
  \label{tab:spi-processor}
\end{table}

Normalerweise wird der ST7565- oder der SSD1306-Controller mit einer 4-Wire SPI-Schnittstelle angeschlossen.
Beim SSD1306-Controller kann auch eine I\textsuperscript{2}C-Schnittstelle mit PD2 als SDA- und PD5 als SCL-Signal benutzt werden.
Die SDA- und SCL-Signale müssen mit einem ,,Pull-up'' Widerstand von ungefähr \(4,7k\Omega\) nach \(3,3V\) versehen sein.
Eine Anschlußmöglichkeit zeigt die Abbildung \ref{fig:ssd1306i2c}.
Vor der Verwendung der ,,Pull-up'' Widerstände nach \(5V\) sollte überprüft werden, ob die Eingänge dieses Signal vertragen.
Normalerweise sind die Eingänge des Kontrollers über Dioden nach \(3.3V\) geschützt.
Die Ausgänge des ATmega werden für die I\textsuperscript{2}C-Signale nur nach \(0V\) geschaltet.
Es sollte aber sichergestellt sein, daß das Programm mit der I\textsuperscript{2}C Schnittstelle in den ATmega geladen wurde,
bevor das Display angeschlossen wird. Wenn ein Programm für eine andere Schnittstelle geladen wurde,
werden die Ausgänge auch nach \(5V\) geschaltet.
Da ich eine Beeinflussung der Meßergebnisse der Testers über den VCC-Anschluß der OLED-Module festgestellt habe, 
ist eine Entkopplung über einen Serienwiderstand von \(68\Omega\) mit zusätzlichem \(10\mu F\)
 Abblock-Kondensator zu empfehlen. 
Anstelle des \(68\Omega\) Widerstand kann auch eine Drossel von etwa \(1mH\) verwendet werden.
Ohne das zusätzliche Filter wurde bei meinem Tester Kollektorrestströme bei bipolaren Transistoren mit einem OLED angezeigt.
Außerdem sollte die Belegung der Pinne beim OLED Modul geprüft werden, bei einigen Modulen ist GND und VCC vertauscht!
 
\begin{figure}[H]
\centering

\caption{Anschluss eines graphischen OLED Displays mit I\textsuperscript{2}C Schnittstelle}
\label{fig:ssd1306i2c}
\end{figure}

Bei der ATmega644 Prozessorserie werden die Pinne PB3 (SCL) und PB4 (SDA) anstelle PD5 und PD2 für den Anschluss benutzt.
Bei der ATmega1280 Prozessorserie werden die Pinne PA5 (SCL) und PA4 (SDA) benutzt.
Ein Austausch des Textdisplays gegen ein grafisches Display ist mit einer Adapterplatine möglich, da
alle notwendigen Datensignale und Versorgungssignale an der LCD-Steckerleiste vorhanden sind.
Etwas einfacher ist der Anschluß eines graphischen Displays mit einem ST7920 Controller weil 
der Controller mit \(5V\) Betriebsspannung läuft.
Dabei sollte das Display 128x64 sichtbare Pixel besitzen.
Das Display Modul mit dem ST7920 Controller kann entweder mit der 4-Bit Parallelschnittstelle oder mit einer 
speziellen Seriellschnittstelle angeschlossen werden, wie die Abbildung \ref{fig:ST7920lcd} zeigt.
 
\begin{figure}[H]
\centering

\caption{Anschluss eines Displays mit ST7920 Controller}
\label{fig:ST7920lcd}
\end{figure}

Für beide Anschlußarten muß die Software speziell konfiguriert werden. 
Die Makefile Option ,,WITH\_LCD\_ST7565 = 7920'' muß dazu auf jeden Fall gesetzt werden, für die serielle
Anschlußart muß außerdem die Option ,,CFLAGS += -DLCD\_INTERFACE\_MODE=5'' gesetzt sein.
Die Tabelle~\ref{tab:ser-processor} zeigt die Belegung der seriellen Anschlußsignale bei 
dem Anschlußtyp 5 (ST7920) und 7 (SSD1803) für verschiedene Prozessoren.

\begin{table}[H]
  \begin{center}
    \begin{tabular}{| c || c | c | c | c |}
    \hline
 Processor  & m644  & m644 & m1280  & m328 \\
STRIP\_GRID\_BOARD &       &   1   &        &     \\
    \hline
    \hline
Signal:     &       &       &        &         \\
  EN        &  PB3  & PB6   &  PA5   & PD5     \\
    \hline
  B0, R/W   &  PB4  & PB7   &  PA4   & PD2      \\
    \hline
  RESET     &  PB2  & PB4   &  PA0   & PD0      \\
    \hline
    \end{tabular}
  \end{center}
  \caption{Serielle Anschlußbelegungen für verschiedene Prozessoren}
  \label{tab:ser-processor}
\end{table}

Die Ausrichtung der Darstellung kann wie bei allen graphischen Displays  mit den Optionen
LCD\_ST7565\-\_H\_FLIP und LCD\_ST7565\-\_V\_FLIP angepaßt werden. \\
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

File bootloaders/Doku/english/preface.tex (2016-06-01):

\section*{Preface}

My interest for the AVR boot-loaders begun, as some users had told
me their interest to run the transistor tester software at
some boards of the Arduino family.
Of course the transistor tester software does not run as Arduino Sketch.
The Arduino development environment Sketch is only used to show
the output of the serial interface.
The transistor tester software do not use the Arduino library.
This is not necessary to use the boot-loader.
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

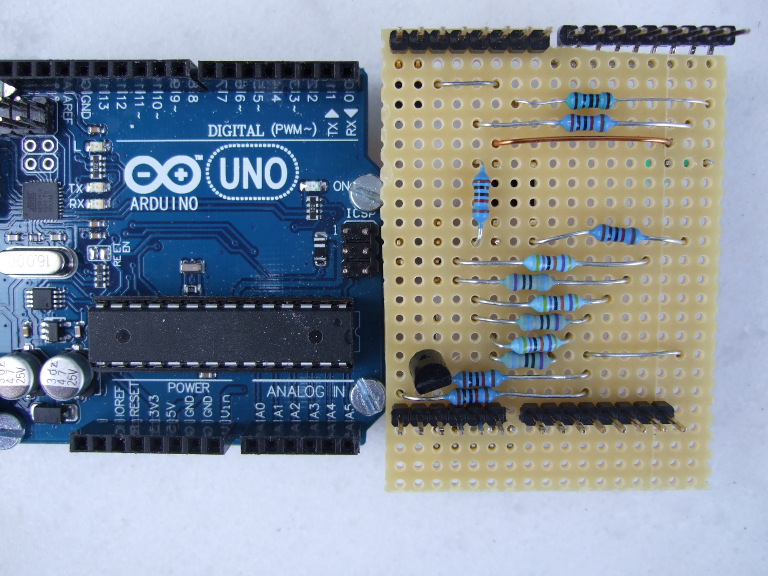
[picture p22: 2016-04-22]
Hardware/ArduinoUno_shield/ArduinoUno_TTshield_back.JPG

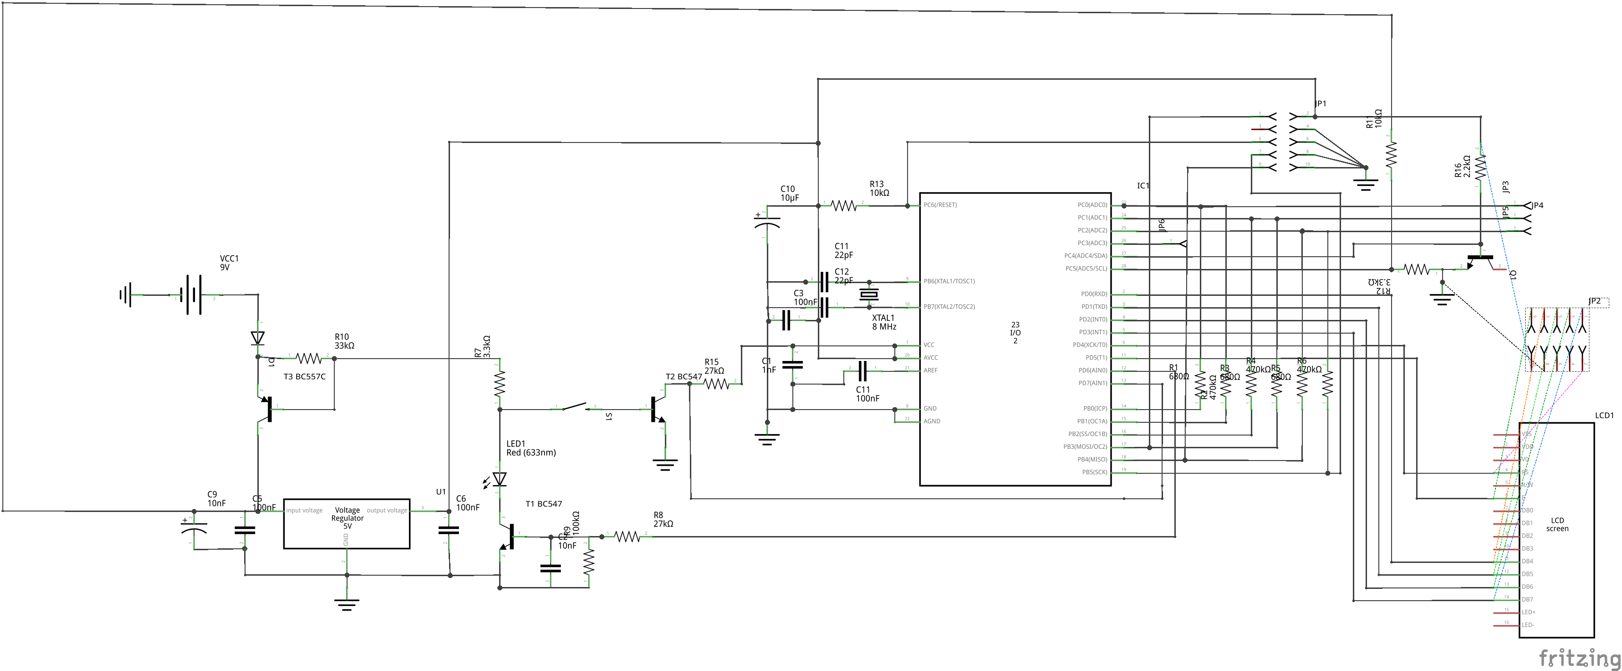
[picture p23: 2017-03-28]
Hardware/Max/fritzing_diagram.png

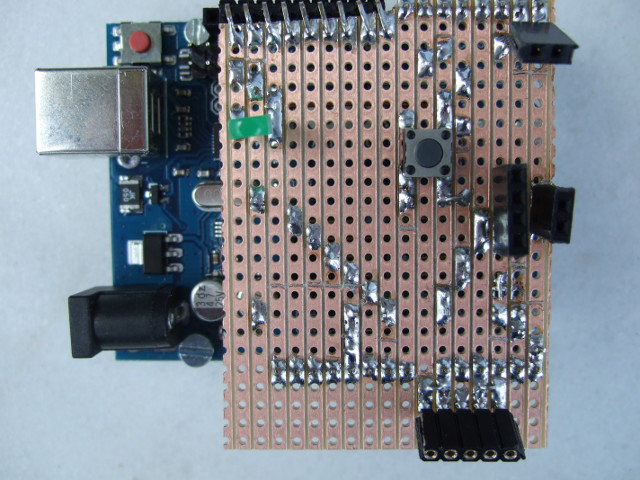
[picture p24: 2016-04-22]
Hardware/ArduinoUno_shield/ArduinoUno_TTshield_front.JPG

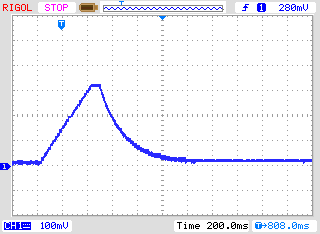
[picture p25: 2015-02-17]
Doku/trunk/pdftex/PNG/charge_5mF.png

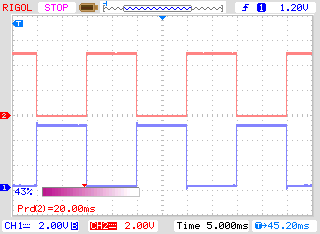
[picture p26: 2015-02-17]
Doku/trunk/pdftex/PNG/Frequency50.png

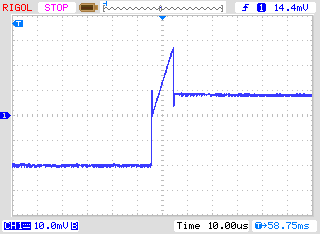
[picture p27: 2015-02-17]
Doku/trunk/pdftex/PNG/NewEsr2u2F2R7zoom.png

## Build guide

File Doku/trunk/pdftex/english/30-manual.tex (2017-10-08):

\chapter{Instructions for use}
\label{sec:manual}
\section{The measurement operation}
Using of the Transistor-Tester is simple.
Anyway some hints are required.
In most cases are wires with alligator clips connected to the test ports with plugs.
Also sockets for transistors can be connected.
In either case you can connect parts with three pins to the three test ports in any order.
If your part has only two pins, you can connect this pins to any two of the tree test ports.
Normally the polarity of part is irrelevant, you can also connect pins of electrolytical capacitors in any order. 
The measurement of capacity is normally done in a way, that the minus pole is at the test port with the lower number.
But, because the measurment voltage is only between \(0.3V\) and at most \(1.3V\), the polarity doesn\'t matter.
When the part is connected, you should not touch it during the measurement. You should put it down to a nonconducting pad
if it is not placed in a socket. You should also not touch to the isolation of wires connected with the test ports.
Otherwise the measurement results can be affected.
Then you should press the start button.
After displaying a start message, the measurement result should appear after two seconds.
If capacitors are measured, the time to result can be longer corresponding to the capacity.

How the transistor-tester continues, depends on the configuration of the software.
\begin{description}
  \item[Single measurement mode] If the tester is configured for single measurement mode (POWER\_OFF option), the tester shut off automatical 
after displaying the result for 28~seconds for a longer lifetime of battery. 
During the display time a next measurement can be started by pressing the start button.
After the shut off a next measurement can be started too of course.
The next measurement can be done with the same or another part.
If you have not installed the electronic for automatic shut down, your
last measurement result will be displayed until you start the next measurement.

  \item[Endless measurement mode] A special case is the configuration without automatical shut off.
For this case the POWER\_OFF option is not set in the Makefile.
This configuration is normally only used without the transistors for the shut off function.
A external off switch is necessary for this case. The tester will repeat measurements until power
is switched off.

  \item[Multi measurement mode] In this mode the tester will shut down not after the first measurement but 
after a configurable series of measurements.
For this condition a number (e.g.~5) is assigned to the POWER\_OFF option.
In the standard case the tester will shut down after five
measurements without found part. If any part is identified by test, the tester is shut down after double of
five (ten) measurements. A single measurement with unknown part after a series of measurement of known parts will
reset the counter of known measuerements to zero. Also a single measurement of known part will reset the counter
of unknown measurements to zero. This behavior can result in a nearly endless series of measurements without
pressing the start button, if parts are disconnected and connected in periodical manner.

In this mode there is a special feature for the display period. If the start button is pressed only short for switching
on the tester, the result of measurement ist only shown for 5 seconds. Buf if you press and hold the start button until
the first message is shown, the further measurement results are shown for 28~seconds.
The next measurement can started earlier by pressing the start button during the displaying of result.

\end{description}

\section{Optional menu functions for the ATmega328}
If the menu function is selected, the tester start a selection menu after a long key press (\textgreater~500ms)
for additional functions.
This function is also available for other processors with at least 32K flash memory.
The selectable functions are shown in row two of a 2-line display or as marked function in row 3 of a 4-line display.
The previous and next function is also shown in row 2 and 4 of the display in this case.
After a longer wait time without any interaction the program leave the menu and returns to the normal transistor tester function.
With a short key press the next selection can be shown.
A longer key press starts the shown or marked function.
After showing the last function ''switch off'', the first function will be shown next.

If your tester has also the rotary pulse encoder installed, you can call the menu with the additional functions
also with a fast rotation of the encoder during the result of a previous test is shown.
The menu functions can be selected with slow rotation of the encoder in every direction.
Starting of the selected menu function can only be done with a key press.
Within a selected function parameters can be selected with slow rotation of the encoder.
A fast rotarion of the encoder will return to the selection menu.

\begin{description}
 \item[frequency]
The additional function ''frequency'' (frequency measurement) uses the ATmega Pin PD4, which is also connected to the LCD.
First the frequency is allways measured by counting.
If the measured frequency is below \(25kHz\), additionally the mean period of the input signal
is measured and with this value the frequency is computed with a resolution of up to \(0.001Hz\).
By selecting the POWER\_OFF option in the Makefile, the period of frequency measurement is limited to 8~minutes.
The frequency measurement will be finished with a key press and the selectable functions are shown again.\\

 \item[f-Generator]
With the additional function ''f-Generator'' (frequency generator) you can select output frequencies between 1Hz and 2MHz.
You can change the selected frequency only at the highest shown digit location. 
For the locations 1Hz up to 10kHz digits between 0 and 9 can be selected.
For the highest 100kHz location you can select numericals between 0 and 20.
In row 1 of the frequency line is indicated with the symbol \textgreater~~or \textless~, 
if a longer key press (\textgreater~0.8s) select a higher or lower digit location.
You can only select a lower location (\textless), if the current location has selected the 0 digit and 
if the current location is not the lowest with 1Hz steps.
If you have selected the 100kHz location, the \textgreater~symbol is replaced by a R character. 
A longer key press (\textgreater~0.8s) will result a reset of the frequency value to the initial value of 1Hz in this case.
If the POWER\_OFF option is selected in the Makefile, the key must be pressed longer, because a
short key press (\textless~0.2s) only reset the time limit of 4~minutes.
The elapsed time is shown with a point for every 30 seconds in row 1 of the display.
With periodical short key press you can prevent the time out of the frequency generation.
With a long key press (\textgreater~2s) you will stop the frequency generator and return to the function menu.\\

\item[10-bit PWM]
The additional function ''10-bit PWM'' (Pulse Width Modulation) generates a fixed frequency with selectable
puls width at the pin TP2.
With a short key press (\textless~0.5s) the pulse width is increased by \(1\%\), with a longer key press the pulse width
is increased by \(10\%\).
If \(99\%\) is overstepped, \(100\%\) is subtracted from the result.
If the POWER\_OFF option is selected in the Makefile, the frequency generation is finished after 8~minutes without any key press.
The frequency generation can also be finished with a very long key press (\textgreater~1.3s).\\

\item[C+ESR@TP1:3]
The additional function ''C+ESR@TP1:3'' selects a stand-alone capacity measurement with 
ESR (Equivalent Series Resistance) measurement at the test pins TP1 and TP3. 
Capacities from \(2\mu F\) up to \(50mF\) can be measured. 
Because the measurement voltage is only about \(300mV\), in most cases the capacitor can be
measured ''in circuit'' without previous disassembling.
If the POWER\_OFF option is selected in the Makefile, the count of measurements is limited
to 250, but can be started immediately again.
The series of measurements can be finished with a long key press.\\

 \item[Resistor meter]
With the \mbox{1 \electricR 3} symbol the tester changes to a resistor meter at TP1 and TP3 . 
This operation mode will be marked with a {\bf[R]} at the right side of the first display line.
Because the ESR measurement is not used in this operation mode, the resolution of the measurement
result for resistors below \(10\Omega\) is only \(0.1\Omega\).
If the resistor measurement function is configured with the additional inductance measurement,
a \mbox{1 \electricR \electricL 3} symbol is shown at this menu.
Then the resistor meter function includes the measurement of inductance for resistors below \(2100\Omega\).
At the right side of the first display line a {\bf[RL]} is shown.
For resistors below \(10\Omega\) the ESR measurement is used,
if no inductance is find out. For this reason the resolution for resistors below \(10\Omega\) 
is increased to \(0.01\Omega\).
With this operation mode the measurement is repeated without any key press.
With a key press the tester finish this operation mode and returns to the menu.
The same resistor meter function is started automatically, if a single resistor is connected between TP1 and TP3
and the start key was pressed in the normal tester function. In this case the tester returns
from the special mode opration to the normal tester function with a key press.

 \item[Capacitor meter]
With the \mbox{1 \electricC 3} symbol the tester changes to a capacitor meter function at TP1 and TP3.
This operation mode will be marked with a {\bf[C]} at the right side of the first display line.
With this operation mode capacitors from \(1pF\) up to \(100mF\) can be measured.
In this operation mode the measurement is repeated without key press.
With a key press the tester finish this operation mode and returns to the menu.
In the same way as with resistors, the tester changes automatically to the capacitor meter function,
if a capacitor between TP1 and TP3 is measured with the normal tester function.
After a automatically start of the capacitor meter function the tester returns with a key press to
the normal tester function.

\item[rotary encoder]
With the function ''rotary encoder'' a rotary encoder can be checked.
The three pins of the rotary encoder must be connected in any order to the three probes of the transistor tester 
before the start of the function. 
After starting the function the rotary knob must be turned not too fast.
If the test is finished successfully, the connection of the encoder switches  is shown symbolic in display row 2.
The tester finds out the common contact of the two switches and shows, if the indexed position has
both contacts in open state ('o') or in closed state ('C').
A rotary encoder with open switches at the indexed positions is shows in row 2 for two seconds as ''1-/-2-/-3 o''.
This type of encoder has the same count of indexed positions as count of pulses for every turn. 
Of course the pin number of the right common contact is shown in the middle instead of '2'.
If also the closed switches state is detected at the indexed positions, the row 2 of the display is also
shown as ''1---2---3 C'' for two seconds.
I don't know any rotary encoder, which have the switches always closed at any indexed position.
The interim state of the switches between the indexed positions is also shown in row 2 for a short time (\textless\(~0.5s\))
without the characters 'o' or 'C'.
If you will use the rotary encoder for handling the tester, you should set the Makefile option WITH\_ROTARY\_SWITCH=2
for encoders with only the open state ('o') and set the option WITH\_ROTARY\_SWITCH=1 for encoders 
with the open ('o') and closed ('C') state at the indexed positions.\\

\item[C(\(\mu F\))-correction]
With this menu function you can change a correction factor for bigger capacity values.
You can preset the same factor with the Makefile option C\_H\_KORR.
Values above zero reduce the output value of the capacity with this percent value, values below zero will increase
the shown capacity value. A short key press will reduce the correction value about 0.1\%, a longer key press will
increase the correction value. A very long key press will save the correction value.
It is a characteristic of the used measurement method, that capacitors with low quality like electrolytic type will
result to a too high capacity value. You can detect a capacitor with low quality by a higher value of the Vloss parameter.
High quality capacitors have no Vloss or only 0.1\%.
For adjusting this parameter you should only use capacitors with high quality and a capacity value above \(50\mu F\).
By the way the exactly capacity value of electrolytic capacitors is unimportant, because the capacity value differ
with temperature and DC-voltage.

\item[Selftest]
With the menu function ''Selftest'' a full selftest with calibration is done.
With that call all the test functions T1 to T7 (if not inhibited with the NO\_TEST\_T1\_T7 option) 
and also the calibration with external capacitor is done every time.\\

\item[Voltage]
The additional function ''Voltage'' (Voltage measurement) is only possible, if the serial output is deselected
or the ATmega has at least 32 pins (PLCC) and one of the additional pins ADC6 or ADC7 is used for the measurement.
Because a 10:1 voltage divides is connected to PC3 (or ADC6/7), the maximum external voltage can be \(50V\).
A installed DC-DC converter for zener diode measurement can be switched on by pressing the key.
Thus connected zener diodes can be measured also.
By selecting the POWER\_OFF option in the Makefile and without key pressing, the period of voltage measurement is limited to 4~minutes.
The measurement can also be finished with a extra long key press (\textgreater~4~seconds).

\item[Contrast] 
This function is available for display controllers, which can adjust the contrast level with software.
The value can be decreased by a very short key press or left turn with the rotary encoder.
A longer key press (\textgreater~0.4s) or a right turn of the rotary encoder will increase the value.
The function will be finished and the selected value will be saved nonvolatile in the EEprom memory 
by a very long key press (\textgreater~1.3s).

\item[BackColor]
For color displays this menu item can be enabled with the Makefile option LCD\_CHANGE\_COLOR 
for selecting the background color. The rotary encoder extension must be installed.
You can select the colors red, green and blue with a longer key press. The intensity value of the
selected color, which is marked with a > symbol in column 1, can be changed by a turn of the rotary encoder.

\item[FrontColor]
For color displays this menu item can be enabled with the Makefile option LCD\_CHANGE\_COLOR 
for selecting the foreground color. The rotary encoder extension must be installed.
You can select the colors red, green and blue with a longer key press. The intensity value of the
selected color, which is marked with a > symbol in column 1, can be changed by a turn of the rotary encoder.

 \item[Show data]
The function ,,Show Data'' shows besides the version number of the software the data of the calibration.
These are the zero resistance (R0) of the pin combination 1:3, 2:3 and 1:2 .
In addition the resistance of the port outputs to the \(5V\) side (RiHi) and
to the \(0V\) side (RiLo) are shown.
The zero capacity values (C0) are also shown with all pin combinations (1:3, 2:3, 1:2 and 3:1, 3:2 2:1).
Next the correction values for the comparator (REF\_C) and for the reference voltage (REF\_R) are also shown.
With graphical displays the used icons for parts and the font set is also shown.
Every page is shown for 15 seconds, but you can select the next page by a key press or a right turn of the rotary encoder.
With a left turn of the rotary encoder you can repeat the output of the last page or return to the previous page.

\item[Switch off]
With the additional function ''Switch off'' the tester can be switched off immediately.\\

\item[Transistor]
Of course you can also select the function ''Transistor'' (Transistor tester) to return to a normal Transistor tester measurement. 
\end{description}

With the selected POWER\_OFF option in the Makefile, all additional functions are limited in time without interaction to prevent a discharged battery.

\section{Selftest and Calibration}

If the software is configured with the selftest function, the selftest can be prepared by connecting all three
test ports together and pushing of the start button.
To begin the self test, the start butten must be pressed again within 2 seconds, or else the tester will continue
with a normal measurement.

If the self test is started, all of the documented tests in the Selftest chapter \ref{sec:selftest} will be done.
If the tester is configured with the menu function (option WITH\_MENU), 
the full selftest with the tests T1 to T7 are only done with the ''Selftest'' function, 
which is selectable as menu function.
In addition the calibration with the external capacitor is done with every call from function menu,
otherwise this part of calibration is only done first time.
Thus the calibration with the automatically started selftest (shorted probes) can be done faster.
The repetition of the tests T1 to T7 can be avoided, if the start button is hold pressed.
So you can skip uninteresting tests fast and you can watch interresting tests by releasing the start button.
The test 4 will finish only automatically if you separate the test ports (release connection).

If the function AUTO\_CAL is selected in the Makefile, 
the zero offset for the capacity measurement will be calibrated with the selftest.
It is important for the calibration task, that the connection between the three test ports is relased 
during test number 4. 
You should not touch to any of the test ports or connected cables when calibration (after test 6) is done.
But the equipment should be the same, which is used for further measurements.
Otherwise the zero offset for capacity measurement is not detected correctly.
The resistance values of port outputs are determined at the beginning of every measurement with this option.\\

If you have selected the samplingADC function in the Makefile with the option ''WITH\_SamplingADC = 1'',
two special steps are included to the calibration precedure.
After the normal measuring of the zero capacity values, also the zero capacity values for the samplingADC function is
measured (C0samp). As last step of the calibration the connection of a test capacitor at pin~1 and pin~3 is requested for
later measurement of little coils with the message \mbox{1 \electricC 3  10-30nF[L]}.
The capacity value should be between \(10nF\) and \(30nF\),
to get a measurable resonant frequency by later parallel connection to a coil with less than \(2mH\).
For inspection of coils with more than \(2mH\) inductance the normal measurement method should result to a
sufficient accuracy. The parallel connection of the capacitor to use the other measurement method should
not be usefull.\\

A capacitor with any capacity between \(100nF\) and \(20\mu F\) connected to pin~1 and pin~3 is
required after the measurement of the zero capacity values.
To indicate that, the message \mbox{1 \electricC 3 \textgreater 100nF} is shown in row 1 of the display.
You should connect the capacitor not before the message C0= or this text is shown.
With this capacitor the offset voltage of the analog comparator will be compensated for better measurement
of capacity values.  
Additionally the gain for ADC measurements using the internal reference voltage will be adjusted too 
with the same capacitor for better resistor measurement results with the AUTOSCALE\_ADC option.
If the menu option is selected for the tester and the selftest is not started as menu function,
the calibration with the external capacitor is only done for the first time calibration.
The calibration  with the external capacitor can be repeated with a selftest call as menu selection.

The zero offset for the ESR measurement will be preset with the option ESR\_ZERO in the Makefile.
With every self test the ESR zero values for all three pin combinations are determined.
The solution for the ESR measurement is also used to get the values of resistors below \(10\Omega\) with
a resolution of \(0.01\Omega\).

\section{special using hints}
Normally the Tester shows the battery voltage with every start. If the voltage fall below a limit,
a warning is shown behind the battery voltage. If you use a rechargeable \(9V\) battery, you should replace
the battery as soon as possible or you should recharge.
If you use a tester with attached \(2.5V\) precision reference, the measured supply voltage will be shown
in display row two for 1 second with ''VCC=x.xxV''.

It can not repeat often enough, that capacitors should be discharged before measuring.
Otherwise the Tester can be damaged before the start button is pressed.
If you try to measure components in assembled condition, the equipment should be allways disconnected from power source.
Furthermore you should be sure, that no residual voltage reside in the equipment.
Every electronical equipment has capacitors inside!

If you try to measure little resistor values, you should keep the resistance of plug connectors and cables in mind.
The quality and condition of plug connectors are important, also the resistance of cables used for measurement.
The same is in force for the ESR measurement of capacitors.
With poor connection cable a ESR value of \(0.02\Omega\) can grow to \(0.61\Omega\).
If possible, you should connect the cables with the test clips steady to the tester (soldered).
Then you must not recalibrate the tester for measuring of capacitors with low capacity values,
if you measure with or without the plugged test cables. 
For the calibration of the zero resistance there is normaly a difference, if you connect the
three pins together directly at a socket or if you connect together the test clips at the end of cables.
Only in the last case the resistance of cables and clips is included in the calibration.
If you are in doubt, you should calibrate your tester with jumpers directly at the socket 
and then measure the resistance of shorten clips with the tester.

You should not expect very good accuracy of measurement results, especially the ESR measurement and the results of inductance measurement are not very exact.
You can find the results of my test series in chapter \ref{sec:measurement} at page~\pageref{sec:measurement}.

\section{Compoments with problems}
You should keep in mind by interpreting the measurement results, that the circuit of the TransistorTester is
designed for small signal semiconductors. In normal measurement condition the measurement current can only reach about \(6mA\).
Power semiconductors often make trouble by reason of residual current with the identification an the measurement of junction capacity value.
The Tester often can not deliver enough ignition current or holding current for power Thyristors or Triacs.
So a Thyristor can be detected as NPN transistor or diode. Also it is possible, that a Thyristor or Triac is detected as unknown.

Another problem is the identification of semiconductors with integrated resistors.
So the base - emitter diode of a BU508D transistor can not be detected by reason of the parallel connected
internal \(42\Omega\) resistor.
Therefore the transistor function can not be tested also.
Problem with detection is also given with power Darlington transistors. We can find often internal
base - emitter resistors, which make it difficult to identify the component with the undersized measurement current.

\section{Measurement of PNP and NPN transistors}
For normal measurement the three pins of the transistor will be connectet in any order to the measurement
inputs of the TransistorTester.
After pushing the start button, the Tester shows in row 1 the type (NPN or PNP), 
a possible integrated protecting diode of the Collector - Emitter path and the
sequence of pins. The diode symbol is shown with correct polarity.
Row 2 shows the current amplification factor \(B\) or \(hFE\) and the current, by which the
amplification factor is measured. If the common emitter circuit is used for the hFE determinatation,
the collector current \(Ic\) is output. If the common collector circuit is used for measuring of the
amplification factor, the emitter current \(Ie\) is shown.
Further parameters are shown for displays with two lines in sequence, one after the the other in line 2.
For displays with more lines further parameters are shown directly until the last line is allready used.
When the last line is allready used before, the next parameter is shown also in the last line
after a time delay automatically or earlier after a key press.
If more parameters are present than allready shown, a + character is shown at the end of the last line.
The next shown parameter is anyway the Base - Emitter threshold voltage.
If any collector cutoff current is measurable, the collector current without base current \(I_CE0\)
and the collector current with base connected to the emitter \(I_CES\) is also shown.
If a protecting diode is mounted, the flux voltage \(Uf\) is also shown as last parameter.

With the common Emitter circuit the tester has only two alternative to select the base current:
\begin{enumerate}
\item The \(680\Omega\) resistor results to a base current of about \(6.1mA\). 
This is too high for low level transistors with high amplification factor, because the base is saturated.
Because the collector current is also measured with a \(680\Omega\) resistor, the collector current
can not reach the with the amplification factor higher value.
The software version of Markus F. has measured the Base - Emitter threshold voltage in this ciruit (Uf=...).\\
\item The \(470k\Omega\) resistor results to a base current of only \(9.2\mu A\) .
This is very low for a power transistor with low current amplification factor.
The software version of Markus F. has identified the current amplification factor with this circuit (hFE=...).\\
\end{enumerate}

The software of the Tester figure out the current amplification factor additionally with the common Collector circuit.
The higher value of both measurement methodes is reported.
The common collector circuit has the advantage, that the base current is reduced by negative current feedback corresponding
to the amplification factor. 
In most cases a better measurement current can be reached with this methode for power transistors
with the \(680\Omega\) resistor and for Darlington Transistors with \(470k\Omega\) resistor.
The reported Base - Emitter threshold voltage Uf is now measured with the same current used 
for determination of the current amplification factor.
However, if you want to know the Base - Emitter threshold voltage with a measurement current of about \(6mA\),
you have to disconnect the Collector and to start a new measurement.
With this connection, the Base - Emitter threshold voltage at \(6mA\) is reported. The capacity value
in reverse direction of the diode is also reported.
Of course you can also analyse the base - collector diode.

With Germanium transistors often a Collector cutoff current \(I_{CE0}\) with currentless base or 
a Collector residual current \(I_{CES}\) with base hold to the emitter level is measured.
Only for ATmega328 processors the Collector cutoff current is shown in this case at the row 2 of the LCD 
for 5 seconds or until the next keypress before showing the current amplification factor. 
With cooling the cutoff current can be reduced significant for Germanium transistors.

\section{Measurement of JFET and D-MOS transistors}
Because the structure of JFET type is symmetrical, the Source and Drain of this transistores can not
be differed.
Normally one of the parameter of this transistor is the current of the transistor with the Gate at the same level as Source.
This current is often higher than the current, which can be reached with the measurement circuit of the TransistorTester
with the \(680\Omega\) resistor.
For this reason the \(680\Omega\) resistor is connected to the Source. Thus the Gate get with the growing of current a negative
bias voltage.
The Tester reports the Source current of this circuit and additionally the bias voltage of the Gate.
So various models can be differed.
The D-MOS transistors (depletion type) are measured with the same methode.

\section{Measurement of E-MOS transistors and IGBTs}
You should know for enhancement MOS transistors (P-E-MOS or N-E-MOS), that the measurement of the gate threshold voltage (Vth)
is more difficult with little gate capacity values. You can get a better voltage value, if you connect a capacitor with a value
of some nF parallel to the gate /source.
The gate threshold voltage will be find out with a drain current of about \(3.5mA\) for a P-E-MOS and about \(4mA\) for a N-E-MOS.
The RDS or better R\textsubscript{DSon} of E-MOS transistors is measured with a gate - source voltage of nearly \(5V\),
which is probably not the lowest value.
In addition, the RDS resistance is determined at a low drain current, which limits the resolution of the resistance value.
Often in the case of IGBTs and sometimes also withn enhancement MOS transistors, the available \(5V\) of the tester
is not sufficient to drive the transistor across the gate.
In this case, a battery with about \(3V\) will help to make a detection and measurements with the tester possible.
The battery is connected to the gate of the transistor with one pole and the other pole of the battery
is then connected to a test port (TP) of the tester instead of the transistor gate.
When the battery is correctly polarized, the battery voltage is added to the control voltage of the tester and
the detection of the transistor succeeds.
The battery voltage must then be added to the indicated gate threshold voltage of course,
in order to get the correct threshold voltage for this component

\section{Measurement of capacitors}
The capacity values are always computed from the time constant, which is build by the serial connection of the
build in resistors with the capacitor during charging. With little capacity values the \(470k\Omega\) resistors are
used for the measurement the time to reach a threshold voltage.
For bigger capacity values with some \(10\mu F\) the voltage grow at the capacitor is monitored after charge pulses with the
\(680\Omega\) resistors. With this voltage grow the capacity can be computed together with the count of fixed length pulses.
Very low capacity values can be measured with the samplingADC method.
For analysing the same load pulse is repeated many times and the voltage is monitored with the time shift of the ADC S\&H time
using interval-tics build from the processor clock. But a complete AD conversion take 1664 processor tics!
Up to 250 ADC samples are build by this way and from the voltage curve the capacity value is computed.
If the samplingADC function is selected in the Makefile, all capacitors with less than \(100pF\) are measured with
the samplingADC function in the capacitor-meter mode {\bf[C]}. The resolution is up to \(0.01pf\) with a clock 
frequency of \(16MHz\). The calibrated condition is difficult to build with this high resolution.
You can assume the use of the samplingADC methode every time, fractions of \(1pF\) are displayed at the screen.
By the way it should mentiored, that the junction capacitance of single diodes can also be measured with
this method. Because this method can measure the capacity value by charging or discharging, two capacity results are shown.
Both values differ be reason of the capacity diode effect.

\section{Measurement of coils}
The normal measurement of the inductance is based on the measurement of the time constant of the current grow.
The detection limit is about \(0.01mH\), if the resistance of the coil is below \(24\Omega\).
For bigger resistance values the resolution is only \(0.1mH\).
If the resistance is above \(2.1k\Omega\), this technique can never be used to detect coils.
The measurement results of this normal measurement is shown in the second line (resistance and inductance).
With the samplingADC method a resonant frequency of coils can be detected with greater inductance values.
If this effect is noticeable, the frequency and the quality factor Q of the coil is shown additionally in line 3. 

The method of resonant frequency measurement can also be used for the determination of the inductance value,
if a sufficient big capacitor mith know capacity value is connected parallel to a little inductance (\textless\(2mH\)).
With a parallel connected capacitor the normal measurement of inductance can no more operate well.
If the resonant frequency let assume a parallel connected capacitor, the inductance of the normal measurement
is not shown and the resistance value is shown in line 1.
For this resonant circuit the quality factor Q is also computed and shown behind the frequency value in line 3.
You can identify this type of measurement with the inductance value at the first position of line 2,
followed by the text '' if '' and the value of the assumed parallel capacity.
The value of this parallel capacitor can currently only be set with the calibration function (\mbox{1 \electricC 3 \(10-30nF\)(L)}).

For displays with only two lines, the content for the third line is shown time-delayed in line 2.

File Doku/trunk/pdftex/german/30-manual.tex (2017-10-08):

\chapter{Bedienungshinweise}
\label{sec:manual}
\section{Der Messbetrieb}
Die Bedienung des Transistortesters ist einfach.
Trotzdem sind einige Hinweise erforderlich.
Meistens sind an die drei Testports über Stecker-Leitungen mit Krokodilklemmen oder anderen Klemmen angeschlossen.
Es können auch Fassungen für Transistoren angeschlossen sein.
In jedem Fall können Sie Bauteile mit drei Anschlüssen mit den drei Testports in beliebiger Reihenfolge verbinden.
Bei zweipoligen Bauteilen können Sie die beiden Anschlüsse mit beliebigen Testports verbinden.
Normalerweise spielt die Polarität keine Rolle, auch Elektrolytkondensatoren können beliebig angeschlossen werden.
Die Messung der Kapazität wird aber so durchgeführt, dass der Minuspol am Testport mit der kleineren Nummer liegt.
Da die Messspannung aber zwischen \(0,3V\) und maximal \(1,3V\) liegt, spielt auch hier die Polarität keine wichtige Rolle.
Wenn das Bauteil angeschlossen ist, sollte es während der Messung nicht berührt werden. Legen Sie es auf einen
isolierenden Untergrund ab, wenn es nicht in einem Sockel steckt. Berühren Sie auch nicht die Isolation der Messkabel,
das Messergebnis kann beeinflusst werden.
Dann sollte der Starttaster gedrückt werden.
Nach einer Startmeldung erscheint nach circa zwei Sekunden das Messergebnis. Bei einer Kondensatormessung kann es
abhängig von der Kapazität auch deutlich länger dauern.

Was dann weiter geschieht, hängt von der Softwarekonfiguration des Testers ab.
\begin{description}
  \item[Einzelmessung] Wenn der Tester für Einzelmessung konfiguriert ist (POWER\_OFF-Option),
 schaltet der Tester nach einer Anzeigezeit
von 28 Sekunden (konfigurierbar) wieder automatisch aus, um die Batterie zu schonen.
Während der Anzeigezeit kann aber auch vorzeitig eine neue Messung gestartet werden.
Nach der Abschaltung kann natürlich auch wieder eine
neue Messung gestartet werden, entweder mit dem gleichen Bauteil oder mit einem anderen Bauteil.
Wenn die Elektronik zum Abschalten fehlt, wird das letzte Messergebnis weiter angezeigt.

  \item[Dauermessung] Einen Sonderfall stellt die Konfiguration ohne die automatische Abschaltfunktion dar.
Hierfür wird die POWER\_OFF-Option in der Makefile nicht gesetzt.
Diese Konfiguration wird normalerweise nur ohne die Transistoren für die Abschaltung benutzt.
Es wird stattdessen ein externer Ein-/Aus-Schalter benötigt. Hierbei wiederholt der Tester die
Messungen solange, bis ausgeschaltet wird.

  \item[Serienmessung] In diesem Konfigurationsfall wird der Tester nicht nach einer Messung sondern erst nach einer konfigurierbaren
Zahl von Messungen abgeschaltet. Hierfür wird der POWER\_OFF-Option in der Makefile eine Wiederholzahl (z.B. 5) zugewiesen.
Im Standardfall wird der Tester nach fünf Messungen ohne erkanntes Bauteil abgeschaltet.
Wird ein angeschlossenes Bauteil erkannt, wird erst bei der doppelten Anzahl, also zehn Messungen abgeschaltet.
Eine einzige Messung mit nicht erkanntem Bauteil setzt die Zählung für erkannte Bauteile auf Null zurück.
Ebenso setzt eine einzige Messung mit erkannten Bauteil die Zählung für die nicht erkannten Bauteile auf Null zurück.
Dies hat zur Folge, dass auch ohne Betätigung des Starttasters immer weiter gemessen werden kann,
 wenn Bauteile regelmässig gewechselt werden.
Ein Bauteilwechsel führt in der Regel durch die zwischenzeitlich leeren Klemmen zu einer Messung ohne erkanntes Bauteil.

Eine Besonderheit gibt es in diesem Betriebsmodus für die Anzeigezeit. Wenn beim Einschalten der Starttaster nur kurz
gedrückt wurde, beträgt die Anzeigezeit der Messergebnisse nur 5 Sekunden. Wenn der Starttaster bis zum Erscheinen der
ersten Meldung festgehalten wurde, beträgt die Anzeigezeit wie bei der Einzelmessung 28 Sekunden.
Ein vorzeitiger neuer Messbeginn ist aber während der Anzeigezeit durch erneutes Drücken des Starttasters möglich.

\end{description}

\section{Optionale Menüfunktionen für den ATmega328}
Wenn die Menüfunktion eingeschaltet ist, startet der Tester nach einem längeren Tastendruck (\textgreater~\(0.5s\)) ein Auswahlmenü
für zusätzliche Funktionen.
Diese Funktion ist auch für andere Prozessoren mit mindestens 32K Flash Speicher verfügbar.
Die wählbaren Funktionen erscheinen in Zeile~2 eines zweizeiligen Displays oder werden als gekennzeichnete
Funktion in Zeile 3 eines vierzeiligen Displays gezeigt. Dabei wird die vorige und nächste Funktion in Zeile 2 und 4 angezeigt.
Nach einer längeren Wartezeit ohne jegliche Bedienung kehrt das Programm zu der normalen Transistortester-Funktion zurück.
Durch kurzen Tastendruck kann zur nächsten Auswahl gewechselt werden.
Mit einem längeren Tastendruck startet die angezeigte Zusatzfunktion.
Nach Anzeige der letzten Funktion ,,Schalte aus'' wird wieder die erste Funktion angezeigt.\\

Wenn der Tester mit einem Drehimpulsgeber ausgerüstet ist, kann die Menü-Auswahl auch mit einem schnellen
Drehen des Encoders während der Anzeige einer vorausgegangenen Messung aufgerufen werden.
Die Menüfunktionen können mit einem langsamen Drehen des Encoders in beliebiger Richtung ausgewählt werden.
Die ausgewählte Menüfunktion kann aber nur mit einem längeren Tastendruck gestartet werden.
Innerhalb einer Menüfunktion können Parameter durch eine langsame Drehung des Encoders ausgewählt werden.
Eine schnelle Drehung des Encoders kehrt zur Menü-Auswahl zurück.

\begin{description}
 \item[Frequenz]
Die Zusatzfunktion ,,Frequenz'' (Frequenzmessung) benutzt als Eingang den PD4-Pin des ATmega, der auch an das LCD angeschlossen ist.
Es wird immer zunächst die Frequenz gemessen, bei Frequenzen unter \(25kHz\) wird auch die mittlere Periode des Eingangssignals
bestimmt und daraus die Frequenz mit einer Auflösung von bis zu \(0,001Hz\) berechnet.
Bei gesetzter POWER\_OFF-Option in der Makefile wird die Dauer der Frequenzmessung auf 8~Minuten beschränkt.
Die Frequenzmessung wird durch Tastendruck beendet und in das Auswahlmenü zurückgekehrt.\\

 \item[f-Generator]
Bei der Zusatzfunktion ,,f-Generator'' (Frequenz-Generator) können die Frequenzen zwischen 1Hz und 2MHz gewählt werden.
Die Einstellung der Frequenz kann jeweils nur für die höchste dargestellte Stelle (Ziffernposition) verändert werden.
Für die Stellen 1Hz bis 10kHz sind jeweils die Ziffern 0-9 wählbar. Bei der 100kHz Stelle ist 0-20 wählbar.
In Spalte 1 der Frequenzzeile wird durch ein \textgreater~oder \textless~Symbol angezeigt, ob durch einen längeren
Tastendruck (\textgreater~0.8s) zur höheren oder niedrigen Stelle geschaltet wird.
Zur niedrigeren Stelle (\textless) kann nur geschaltet werden, wenn die augenblickliche Stellee auf 0 gestellt wurde
und wenn nicht die Stelle mit 1Hz Schritten gewählt wurde.
Bei der gewählten 100kHz Stelle ist das \textgreater~Symbol durch ein R Zeichen ersetzt. Der längere Tastendruck bewirkt dann eine
Rücksetzung der Frequenz auf den Startwert 1Hz.
Bei gesetzter POWER\_OFF-Option in der Makefile muss für den Frequenzwechsel die Taste länger gedrückt werden, da
durch einen kurzen Tastendruck (\textless~0,2s) nur die Zeitüberwachung von 4~Minuten zurückgesetzt wird.
Die abgelaufene Zeit wird in Zeile 1 durch einen Punkt für jede abgelaufene 30 Sekunden angezeigt.
Durch einen regelmäßigen kurzen Tastendruck kann die vorzeitige Abschaltung der Frequenzerzeugung verhindert werden.
Ein längerer Tastendruck (\textgreater~2s) kehrt wieder zur Auswahl der Funktionen zurück.\\

 \item[10-bit PWM]
Bei der Zusatzfunktion ,,10-bit PWM'' (Pulsweitenmodulation) wird eine feste Frequenz mit einstellbarer Pulsweite an Pin TP2 erzeugt.
Mit einem kurzen Tastendruck (\textless~0,5s) wird die Pulsweite um \(1\%\) erhöht, mit einem längeren Tastendruck um \(10\%\).
Bei Überschreiten von \(99\%\) werden \(100\%\) vom erhöhten Wert abgezogen.
Bei gesetzter POWER\_OFF-Option in der Makefile wird die Frequenzerzeugung nach 8 Minuten ohne Bedienung beendet.
Durch sehr langen Tastendruck (\textgreater~1,3s) kann die Frequenzerzeugung auch beendet werden.\\

 \item[C+ESR@TP1:3]
Bei der Zusatzfunktion ,,C+ESR@TP1:3'' wird eine separate Kondensatormessung mit ESR-Messung an TP1 und TP3 gestartet.
Messbar sind Kondensatoren mit mehr als \(2\mu F\) bis zu \(50mF\). Wegen der geringen Messspannung von etwa 300mV sollte
in vielen Fällen die Messung in der Schaltung ohne vorherigen Ausbau möglich sein.
Bei gesetzter POWER\_OFF-Option in der Makefile ist die Anzahl der Messungen auf 250 beschränkt,
kann aber sofort wieder gestartet werden.
Die Mess-Serie kann durch einen längeren Tastendruck beendet werden.\\

 \item[Widerstandsmeßgerät]
Mit dem \mbox{1 \electricR 3} Symbol wird der Tester in ein Ohmmeter an TP1 und TP3 verwandelt. Diese Betriebsart wird durch
ein {\bf[R]} in der rechten Ecke der ersten Displayzeile angezeigt. Weil bei dieser Betriebsart die
ESR-Meßfunktion nicht benutzt wird, beträgt auch für Widerstände unter \(10\Omega\) die Auflösung
nur \(0.1\Omega\). Wenn die Ohmmeter Funktion mit der Induktitivitätsmessung konfiguriert wurde,
erscheint hier ein \mbox{1 \electricR \electricL 3} Symbol.
Dann beinhaltet die Ohmmeter Funktion die Messung von Induktivitäten für Widerstände unter \(2100\Omega\). 
In der rechten Ecke der ersten Zeile des Displays wird dann ein {\bf[RL]} angezeigt.
Für Widerstände unter \(10\Omega\) wird dann auch die ESR-Meßmethode benutzt,
wenn keine Induktivität festgestellt wurde. Damit erhöht sich die Auflösung für Widerstände
unter \(10\Omega\) auf \(0.01\Omega\).
In dieser Betriebsart werden die Meßwerte fortlaufend ermittelt.
Mit einem Tastendruck beendet der Tester diese Betriebsart und kehrt wieder zum Menü zurück.
Die gleiche Betriebsart wird auch automatisch gestartet, wenn zwischen TP1 und TP3 ein einzelner Widerstand
angeschlossen wurde und der Start-Taster gedrückt wurde. In diesen Fall kehrt der Tester mit einem Tastendruck 
wieder zu der normalen Teseterfunktion zurück.

 \item[Kondensatormeßgerät]
Mit dem \mbox{1 \electricC 3} Symbol wird der Tester
in ein reines Kondensator-Meßgerät an TP1 und TP3 verwandelt.
Die Betriebsart wird durch ein {\bf[C]} in der rechten Ecke der ersten Zeile des Displays angezeigt.
Bei dieser Betriebsart können Kondensatoren ab \(1pF\) bis zu \(100mF\) gemessen werden.
In dieser Betriebsart werden die Meßwerte fortlaufend ermittelt.
Mit einem Tastendruck wird dieser Sonderbetrieb beendet und der Tester kehrt wieder zum Menü zurück.
Auch hier wird wie bei der Widerstands-Meßfunktion in den  Betriebs-Modus automatisch gewechselt,
 wenn zwischen TP1 und TP3 ein Kondensator mit der normalen Testerfunktion gemessen wurde.
Der Tester kehrt nach dem automatischen Start wieder zu der normalen Testerfunktion zurück, wenn der Taster gedrückt wird.

 \item[Impulsdrehgeber]
Mit der Zusatzfunktion ,,Impulsdrehgeber'' kann ein Drehgeber untersucht werden.
Die drei Kontakte des Impulsdrehgebers müssen vor dem Start der Zusatzfunktion beliebig an die drei Testpins
 des Transistortesters angeschlossen werden.
Nach dem Start der Funktion muss der Drehknopf nicht zu schnell gedreht werden.
Wenn der Test erfolgreich abgeschlossen ist, wird die Pinbelegung der Kontakte symbolisch in Zeile 2 dargestellt.
Dabei wird der gemeinsame Anschluss herausgefunden und für etwa zwei Sekunden angezeigt,
ob an den Raststellung beide Kontake offen ('o') oder beide Kontakte geschlossen ('C') sind.
Ein Impulsdrehgeber mit offenen Kontakten an den Raststellungen wird so mit der Zeile 2 ,,1-/-2-/-3~o'' zwei Sekunden lang angezeigt.
Natürlich wird die richtige Pinnummer des gemeinsamen Kontaktes in der Mitte anstelle der '2' angezeigt.
Wenn auch die geschlossene Schalterstellung an den Raststellungen vorkommt,
wird außerdem in Zeile 2 ,,1---2---3~C'' zwei Sekunden lang angezeigt.
Mir ist kein Impulsdrehgeber bekannt, der immer nur geschlossene Kontakte an jeder Raststellung hat.
Die Stellungen der Kontakte zwischen den Raststellungen werden nur kurz (\textless\(~0,5s\)) ohne die Kennbuchstaben 'o' oder 'C' 
in Zeile 2 angezeigt.
Wenn der Impulsdrehgeber für die Bedienung des Testers eingesetzt werden soll, muß die Makefile Option WITH\_ROTARY\_SWITCH=2
für Drehgeber mit nur den offenen Kontakten ('o') und die Option WITH\_ROTARY\_SWITCH=1 für Drehgeber mit
offenen ('o') und geschlossenen ('C') Kontakten an den Raststellungen.\\

\item[C(\(\mu F\))-Korrektur]
Mit dieser Menüfunktion kann ein Korrekturwert für die Messung grösserer Kapazitätswerte geändert werden.
Die Funktion ist die gleiche, die auch mit der Makefile Option C\_H\_KORR voreingestellt werden kann.
Werte über Null reduzieren den Ausgabewert der Kapazität um diesen Prozent Wert, Werte unter Null würden den Ausgabewert
anwachsen lassen. Ein kurzer Tastendruck verringert den Korrekturwert um 0.1\%, ein längerer Tastendruck vergrößert
den Korrekturwert um 0.1\%. Ein sehr langer Tastendruck speichert den Wert.  Es ist eine Eigenschaft des
Meßverfahrens, daß Kondensatoren mit geringer Güte wie Elektrolyt-Kondensatoren mit zu großer Kapazität gemessen werden.
Erkennbar ist die Güte über den Parameter Vloss. Gute Kondensatoren haben kein Vloss oder nur 0.1\%.
Zum Abgleich dieses Parameters sollten also nur Kondensatoren mit über \(50\mu F\) hoher Güte verwendet werden.
Übrigens halte ich die Bestimmung des exakten Kapazitätswertes von Elektrolyt-Kondensatoren für überflüssig,
da die Kapazität sowohl von der Temperatur als auch der DC-Spannung abhängt.

 \item[Selbsttest]
Mit der Zusatzfunktion ,,Selbsttest'' wird ein vollständiger Selbsttest mit Kalibration durchgeführt.
Dabei werden sowohl die Testfunktionen T1 bis T7 (wenn nicht verhindert mit der Option NO\_TEST\_T1\_T7) 
als auch die Kalibration mit dem externen Kondensator jedes Mal durchgeführt.\\

 \item[Spannung]
Die Zusatzfunktion ,,Spannung'' (Spannungsmessung) ist nur möglich, wenn die serielle Ausgabe deaktiviert wurde
oder der ATmega mindestens 32 Pinne hat (PLCC) und einer der zusätzlichen Pinne ADC6 oder ADC7 für die Messung benutzt wird.
Da am Port PC3 (oder ADC6/7) ein 10:1-Spannungsteiler vorgesehen ist, können Spannungen bis \(50V\) gemessen werden.
Ein installierter DC-DC-Wandler für die Zenerdioden-Messung wird durch Tastendruck eingeschaltet.
So können auch angeschlossene Zenerdioden gemessen werden.
Bei gesetzter POWER\_OFF-Option in der Makefile und ohne Bedienung wird die Messung nach 4~Minuten beendet.
Die Messung kann aber durch einen besonders langen Tastendruck (\textgreater~4~Sekunden) vorher beendet werden.\\

\item[Kontrast] 
Diese Funktion steht für Controller mit Kontrasteinstellung per Software zur Verfügung.
Der Einstellwert kann mit einem sehr kurzen Tastendruck oder einer Linksdrehung des Impulsdrehgebers verringert werden.
Ein längerer Tastendruck oder eine Rechtsdrehung des Impulsdrehgebers vergrößert den Einstellwert.
Die Funktion wird beendet und der eingestellte Wert wird permanent in den EEPROM geschrieben, 
wenn die Taste noch länger gedrückt wird.

\item[BackColor]
Für Farbdisplays kann dieser Menüpunkt mit der Makefile Option LCD\_CHANGE\_COLOR eingeschaltet werden,
um die Hintergrundfarbe einstellen zu können. Die Impulsdrehgeber-Erweiterung muß dafür installiert sein.
Sie können eine der drei Farben rot, grün und blau mit einem längeren Tastendruck wählen.
Die Intensität der gewählten Farbe, die mit einem > Zeichen in Spalte 1 gekennzeichnet wird,
kann durch Drehen des Impulsdrehgebers verändert werden.

\item[FrontColor]
Für Farbdisplays kann dieser Menüpunkt mit der Makefile Option LCD\_CHANGE\_COLOR eingeschaltet werden,
um die Vordergrundfarbe einstellen zu können. Die Impulsdrehgeber-Erweiterung muß dafür installiert sein.
Sie können eine der drei Farben rot, grün und blau mit einem längeren Tastendruck wählen.
Die Intensität der gewählten Farbe, die mit einem > Zeichen in Spalte 1 gekennzeichnet wird,
kann durch Drehen des Impulsdrehgebers verändert werden.

 \item[Zeige Daten]
Die Funktion ,,Zeige Daten'' zeigt neben der Software-Versionsnummer die Daten des Abgleichs an.
Dies sind die Nullwiderstände R0 von Pin 1:3, 2:3 und 1:2 .
Außerdem werden die Ausgangswiderstände der Ports zur \(5V\)-Seite (RiHi) und 
zur \(0V\) Seite (RiLo) angezeigt.
Die Nullkapazitätswerte (C0) werden ebenfalls in allen Pinkombinationen angezeigt (1:3, 2:3, 1:2 und 3:1, 3:2 2:1).
Danach werden auch die Spannungskorrekturen für die Komparatorspannung (REF\_C) und für die Referenzspannung (REF\_R) angezeigt.
Bei Graphikdisplays werden danach noch die verwendeten Symbole für die Bauteile und der Fontsatz angezeigt.
Jede Seite wird 15 Sekunden angezeigt.
Es kann aber auch durch Tastendruck oder einer Rechtsdrehung des Impulsdrehgebers
zur nächsten Seite geblättert werden.
Mit einer Linksdrehung des Impulsdrehgebers kann die Ausgabe wiederholt werden oder zur vorigen Seite zurückgeblättert werden.

 \item[Schalte aus]
Mit der Zusatzfunktion ,,Schalte aus'' kann der Transistortester abgeschaltet werden.\\

 \item[Transistor]
Natürlich kann mit der Funktion ,,Transistor'' (Transistortester) wieder zu der normalen Transistortester-Funktion
zurückgekehrt werden.

\end{description}

Bei gesetzter POWER\_OFF-Option in der Makefile sind alle Zusatzfunktionen zeitbeschränkt, damit die Batterie nicht verbraucht wird.

\section{Selbsttest und Kalibration}

Wenn die Software mit der Selbsttestfunktion konfiguriert ist, kann der Selbsttest durch einen Kurzschluss aller drei
Testports und Drücken der Starttaste eingeleitet werden.
Für den Start des Selbsttests muss die Starttaste innerhalb von 2 Sekunden noch einmal gedrückt werden,
sonst wird mit einer normalen Messung fortgefahren.
Beim Selbsttest werden die im Selbsttest-Kapitel \ref{sec:selftest} beschriebenen Tests ausgeführt.
Wenn der Tester mit einer Menüfunktion (Option WITH\_MENU) konfiguriert ist, 
wird der vollständige Selbsttest mit den Tests T1 bis T7 nur bei dem ,,Selbsttest'' ausgeführt, 
der als Menüfunktion ausgewählt werden kann.
Außerdem wird beim Aufruf über die Menüfunktion der Abgleich mit dem externen Kondensator jedesmal durchgeführt,
sonst nur für den ersten Aufruf.
Damit kann der durch die kurgeschlossenen Testports automatisch gestartete Abgleich schneller durchgeführt werden. 
Die viermalige Testwiederholung bei T1 bis T7 kann vermieden werden, wenn der Starttaster gedrückt gehalten wird.
So kann man uninteressante Tests schnell beenden und
sich durch Loslassen des Starttasters interessante Tests viermal wiederholen lassen.
Der Test 4 läuft nur automatisch weiter, wenn die Verbindung zwischen den Testports gelöst wird.

Wenn die Funktion AUTO\_CAL in der Makefile gewählt ist, wird beim Selbsttest
eine Kalibration der Nullwertes für die Kondensatormessung durchgeführt.
Für die Kalibration des Nullwertes für die Kondensatormessung ist wichtig, 
dass die Verbindung zwischen den Testpins (Kurzschluß) während des Tests 4 wieder gelöst wird!
Sie sollten während der Kalibration (nach dem Test 6) weder die Testports noch angeschlossene Kabel berühren.
Die Ausrüstung sollte aber die gleiche sein, die später zum Messen verwendet wird.
Anderenfalls wird der Nullwert der Kondensatormessung nicht richtig bestimmt.
Die Kalibration des Innenwiderstandes der Port-Ausgänge wird mit dieser Option vor jeder
Messung durchgeführt. \\

Bei der Kalibration werden zwei Sonderschritte gemacht, wenn die samplingADC Funktion in der Makefile gewählt wurde (WITH\_SamplingADC = 1).
Nach der normalen Bestimmung der Nullwerte der Kapazitätsmessung werden dann auch die Nullwerte mit
der Sampling Methode (C0samp) bestimmt. Als letzter Teil der Kalibration wird der Anschluß eines Testkondensators für die
Spulenmessung an Pin~1 und Pin~3 angefordert mit der Meldung \mbox{1 \electricC 3  10-30nF(L)}.
Der Kapazitätswert sollte hierbei zwischen \(10nF\) und \(30nF\) liegen,
um eine meßbare Resonanzfrequenz bei der späteren Parallelschaltung mit einer Spule (\textless~\(2mH\)) zu erreichen.
Für Spulen mit mehr als 2mH Induktivität sollte die normale Testfunktion ohne die Parallelschaltung eines
Kondensators ausreichen. Ein Parallelschalten des Kondensators sollte hier nicht mehr 
zu einer Verbesserung des Meßergebnisses führen.\\

Nach der Bestimmung der Nullkapazitäten ist der Anschluss eines Kondensators 
mit einer beliebiger Kapazität zwischen \(100nF\) und \(20\mu F\) an Pin~1 und Pin~3 erforderlich.
Dazu wird in Zeile 1 ein \mbox{1 \electricC 3\textgreater 100nF} angezeigt.
Sie sollten den Kondensator erst nach der Ausgabe der C0 Werte oder nach der Ausgabe dieser Aufforderung anschließen.
Mit diesem Kondensator wird die Offset-Spannung des analogen Komparators kompensiert,
um genauere Kapazitätswerte ermitteln zu können.
Die Verstärkung für ADC-Messungen mit der internen Referenz-Spannung wird ebenfalls mit diesem Kondensator abgeglichen, um
bessere Widerstands-Messergebnisse mit der AUTOSCALE\_ADC-Option zu erreichen.
Wenn die Menüfunktion beim Tester ausgewählt wurde (Option WITH\_MENU) und der Selbsttest
nicht als Menüfunktion gestarte wurde, wird der Abgleich mit dem externen Kondensator nur bei
der ersten Kalibration durchgeführt.
Die Kalibration mit dem externen Kondensator kann nur wiederholt werden, wenn der Selbsttest
als Menüfunktion ausgewählt wird.

Der Nullwert für die ESR-Messung wird als Option ESR\_ZERO in der Makefile vorbesetzt.
Mit jedem Selbsttest wird der ESR Nullwert für alle drei Pinkombinationen neu bestimmt.
Das Verfahren der ESR-Messung wird auch für Widerstände mit Werten unter \(10\Omega\) benutzt um
hier eine Auflösung von \(0,01\Omega\) zu erreichen.

\section{Besondere Benutzungshinweise}
Normalerweise wird beim Start des Testers die Batteriespannung angezeigt. Wenn die Spannung eine Grenze unterschreitet, 
wird eine Warnung hinter der Batteriespannung ausgegeben. Wenn Sie eine aufladbare \(9V\)-Batterie benutzen, sollten Sie
den Akku möglichst bald austauschen oder nachladen.
Wenn Sie eine Version mit eingebauter \(2,5V\)-Präzisionsreferenz besitzen, wird beim Start für eine Sekunde die
gemessene Betriebsspannung in der Zeile 2 mit ,,VCC=x.xxV'' angezeigt.

Es kann nicht oft genug erwähnt werden, dass Kondensatoren vor dem Messen entladen sein müssen.
Sonst kann der Tester schon defekt sein, bevor der Startknopf gedrückt ist.
Wenn man versucht, Bauelemente im eingebauten Zustand zu messen, sollte das Gerät immer von
der Stromquelle getrennt sein. Außerdem sollte man sicher sein, dass keine Restspannung mehr
im Gerät vorhanden ist. Alle Geräte haben Kondensatoren verbaut!

Beim Messen kleiner Widerstandswerte muss man besonders auf die Übergangswiderstände achten.
Es spielt die Qualität und der Zustand von Steckverbindern eine große Rolle, genau so wie die
Widerstandwerte von Messkabeln. Dasselbe gilt auch für die Messung des ESR-Wertes von Kondensatoren.
Bei schlechten Anschlusskabeln mit Krokodilklemmen wird so aus einem ESR von \(0,02\Omega\) leicht
ein Wert von \(0,61\Omega\).
Wenn möglich sollte man Kabel mit Testklemmen an die drei Testports parallel zu vorhandenen Sockeln fest anschließen (anlöten).
Dann braucht der Tester für kleine Kapazitäten nicht jedesmal neu kalibriert werden, wenn mit oder ohne eingesteckte
Testkabel gemessen wird. Für die Kalibration des Nullwiderstandes macht es aber im allgemeinen einen Unterschied, 
ob die Testpins direkt am Sockel oder am Ende der Kabel mit den den Testklemmen verbunden wird. Nur im letzteren
Fall ist der Widerstand von Kabel und Klemmen mit kalibriert. Im Zweifelsfall kann man die Kalibration mit dem
Kurzschluß am Testsockel durchführen und danach den Widerstand der kurzgeschlossenen Klemmen mit dem Tester messen.

An die Genauigkeit der Messwerte sollte man keine übertriebenen Erwartungen haben, dies gilt besonders
für die ESR Messung und die Induktivitätsmessung.
Die Ergebnisse meiner Messreihen kann man im Kapitel \ref{sec:measurement} ab Seite~\pageref{sec:measurement} finden.

\section{Problemfälle}
Bei den Messergebnissen sollten Sie immer im Gedächtnis behalten, dass die Schaltung des Transistortesters für
Kleinsignal-Bauelemente ausgelegt ist. Normalerweise beträgt der maximale Messstrom etwa \(6mA\).
Leistungshalbleiter machen oft wegen hoher Reststöme Probleme bei der Erkennung oder beim Messen der
Sperrschicht-Kapazität.
Bei Thyristoren und Triacs werden oft die Zündströme oder die Halteströme nicht erreicht. Deswegen kann es
vorkommen, dass ein Thyristor als NPN-Transistor oder Diode erkannt wird. Ebenso ist es möglich, dass ein 
Thyristor oder Triac gar nicht erkannt wird.

Probleme bei der Erkennung machen auch Halbleiter mit integrierten Widerständen.
So wird die Basis-Emitter-Diode eines BU508D-Transistors wegen eines parallel geschalteten internen
\(42 \Omega\) Widerstandes nicht erkannt.
Folglich kann auch die Transistorfunktion nicht geprüft werden.
Probleme bei der Erkennung machen oft auch Darlington-Transistoren höherer Leistung. Hier sind auch
oft Basis-Emitter-Widerstände verbaut, welche die Erkennung wegen der hier verwendeten kleinen Messströme erschweren.

\section{Messung von PNP- und NPN-Transistoren}
Normalerweise werden die drei Anschlüsse des Transistors in beliebiger Reihenfolge an die Messeingänge des
Transistortesters angeschlossen.
Nach dem Drücken des Starttasters meldet der Tester in der Zeile 1 den Typ (NPN oder PNP), 
eine eventuell vorhandene Schutzdiode der Kollektor-Emitter-Strecke und
die Anschlussbelegung. Das Diodensymbol wird  polungsrichtig angezeigt.
In der Zeile 2 wird der Stromverstärkungsfaktor \(B\) oder \(hFE\) angegeben und der Strom, bei der die Verstärkung
bestimmt wurde. Wenn die Emitterschaltung für die Bestimmung des Verstärkungsfaktors verwendet wurde,
wird der Kollektorstrom \(Ic\) genannt. Bei Bestimmung des Verstärkungsfaktors in Kollektorschaltung (Emitterfolger)
wird der Emitterstrom \(Ie\) angegeben. Weitere Parameter werden bei einem zweizeiligen Display
nacheinander in Zeile 2 angegeben. Bei Displays mit mehr Zeilen werden weitere Zeilen benutzt bis
die letzte Zeile schon benutzt war.
Erst bei der letzten Zeile erfolgen weitere Ausgaben nacheinander in der letzten Zeile.
Wenn weitere Parameter vorhanden sind, wird am Ende der letzten Zeile ein + Zeichen ausgegeben.
Der nächste Wert erscheint auf Knopfdruck oder nach einer Wartezeit auch automatisch.
Der nächste ausgegebene Parameter ist jedenfalls die Basis-Emitter-Schwellspannung \(Ube\),
bei der der Verstärkungsfaktor bestimmt wurde.
Falls meßbar, werden auch der Kollektor-Reststrom mit offener Basis \(I_{CE0}\) und mit kurzgeschlossener
Basis \(I_{CES}\) ausgegeben.
Falls eine Schutzdiode vorhanden ist, wird die Flußspannung \(Uf\) dieser Schutzdiode als letzter Parameter ausgegeben.

Bei der Emitterschaltung hat der Tester nur zwei Möglichkeiten, den Basisstrom einzustellen:
\begin{enumerate}
\item Mit dem \(680\Omega\) Widerstand ergibt sich ein Basisstrom von etwa \(6,1mA\). Das ist für einen
Kleinsignaltransistor mit hohem Verstärkungsfaktor meist zu viel, weil die Basis gesättigt ist.
Da der Kollektorstrom ebenfalls mit einem \(680\Omega\) Widerstand gemessen wird, kann der Kollektorstrom
den um den Verstärkungsfaktor höheren Strom gar nicht erreichen. Die Softwareversion vom Markus F. hat
in diesem Zustand die Basis-Emitter Spannung gemessen (Uf=...).\\
\item Mit dem \(470k\Omega\) Widerstand] ergibt sich ein Basisstrom von nur \(9,2\mu A\) .
Das ist für einen Leistungstransistor mit geringem Verstärkungsfaktor sehr wenig.
Die Softwareversion von Markus F. hat in diesem Zustand den Stromverstärkungsfaktor bestimmt (hFE=...).\\
\end{enumerate}

Die Software des Testers bestimmt die Stromverstärkung jetzt auch in der Kollektorschaltung.
Ausgegeben wird der höhere Wert der beiden Mess-Methoden.
Die Kollektorschaltung hat den Vorteil, dass sich durch die Stromgegenkopplung der Basisstrom abhängig vom
Verstärkungsfaktor reduziert. Dadurch kann für Leistungstransistoren mit dem \(680\Omega\) und für Darlington-Transistoren
mit dem \(470k\Omega\) Widerstand meist ein günstigerer Messstrom ergeben.
Die ausgegebene Basis-Emitter-Schwellspannung \(Ube\) ist jetzt die Spannung,
die bei der Bestimmung des Stromverstärkungsfaktors gemessen wurde.
Wenn man trotzdem eine Basis-Emitter-Schwellspannung bei circa \(6mA\) ermitteln möchte, muss man den Kollektor
vom Tester trennen und noch einmal messen.
Dann wird die Schwellspannung bei etwa \(6mA\) ausgegeben und die Kapazität der Diode in Sperr-Richtung ermittelt.
Natürlich kann so auch die Basis-Kollektor-Diode gemessen werden.

Bei Germanium-Transistoren wird meistens ein Kollektor-Emitter-Reststrom \(I_{CE0}\) mit stromloser Basis oder
ein Kollektor-Emitter-Reststrom \(I_{CES}\) mit Basis auf Emitterpotential gemessen.
Durch Kühlen kann der Reststrom bei Germanium-Transistoren erheblich gesenkt werden. 

\section{Messung von JFET- und D-MOS-Transistoren}
Wegen des symmetrischen Aufbaus von JFET-Transistoren kann Source und Drain nicht unterschieden werden.
Normalerweise wird bei JFETs als eine Kenngröße der Strom bei kurzgeschlossenem Gate-Source angegeben.
Dieser Strom ist aber oft höher als der, der sich bei der Messschaltung mit dem \(680\Omega\) Widerstand erreichen läßt.
Deswegen wird der \(680\Omega\) Widerstand an den Source-Anschluss geschaltet. Dadurch erhält das Gate
stromabhängig eine negative Vorspannung. Als Kenngröße wird sowohl der ermittelte Strom als auch die
Gate-Source-Spannung ausgegeben. 
Damit können verschiedene Typen unterschieden werden.
Für D-MOS-Transistoren (Verarmungs-Typ) wird das gleiche Messverfahren verwendet.

\section{Messung von E-MOS Transistoren und IGBTs}
Für Anreicherungs-MOS-Transistoren (P-E-MOS oder N-E-MOS) sollte man wissen, dass die Bestimmung der Gate-Schwellspannung (Vth)
bei kleiner Gatekapazität schwierig wird. Hier können mit dem Tester genauere Spannungswerte ermittelt werden, wenn ein
Kondensator mit einigen nF parallel zum Gate / Source angeschlossen wird.
Die Schwellspannung wird bei Drain-Strömen von etwa \(3,6mA\) für P-E-MOS und bei etwa \(4mA\) für N-E-MOS bestimmt.
Der Widerstand RDS or besser R\textsubscript{DSon} von E-MOS Transistoren wird mit einer Gate - Source Spannung von annähernd \(5V\) bestimmt,
 was wahrscheinlich nicht der niedrigste Wert ist.
Außerdem wird der RDS Widerstand bei niedrigem Drain-Strom ermittelt, was die Auflösung des Widerstandswertes begrenzt.
Oft bei IGBTs und manchmal auch bei Anreicherungs-MOS Transistoren reichen die verfügbaren \(5V\) des Testers nicht aus, 
um den Transistor über das Gate anzusteuern.
In diesem Fall hilft eine Batterie mit etwa \(3V\) aus, um eine Erkennung und Messungen mit dem Tester möglich zu machen.
Die Batterie wird dazu mit einem Pol an das Gate des Transistors angeschlossen und der andere Pol der Batterie
 wird dann anstelle des Transistor-Gates an einen Testport (TP) des Testers angeschlossen.
Bei richtiger Polung der Batterie  addiert sich die Batteriespannung zu der Steuerspannung des Testers und die 
Erkennung des Transistors gelingt.
Natürlich muß dann die Batteriespannung zu der angezeigten Gate-Schwellspannung addiert werden,
um die richtige Schwellspannung für dieses Bauteil zu erhalten.

\section{Messen von Kondensatoren}
Die Kapazitätswerte werden immer aus einer Zeitkonstanten berechnet, die sich aus der Serienschaltung von eingebauten
Widerständen mit dem Kondensator bei Ladevorgängen ergeben. Bei kleineren Kondensatoren werden die \(470k\Omega\) Widerstände
für die Messung benutzt und die Zeit bis zum Erreichen einer Schwellspannung gemessen.
Bei größeren Kondensatoren mit einigen \(10\mu F\) wird die Spannungserhöhung des Kondensators nach Ladepulsen mit den \(680\Omega\) Widerständen 
beobachtet und daraus die Kapazität berechnet. Ganz kleine Kapazitäten können mit der samplingADC Methode gemessen werden.
Dabei wird ein Aufladevorgang immer wieder erzeugt und durch Verschiebung der ADC S\&H Zeit mit dem Zeitabstand abgetastet,
der sich aus der Taktfrequenz des Prozessors ergibt. Eine komplette ADC Wandlung braucht hingegen 1664 Prozessortakte!
Bis zu 250 ADC-Werte werden so ermittelt und aus dem Spannungsverlauf die Kapazität berechnet.
Wenn die samplingADC Funktion in der Makefile gewählt wurde, werden alle Kondensatoren \textless~\(100pF\) in der 
Kondensatormeßfunktion  {\bf[C]} mit der samplingADC Methode gemessen. Die Auflösung beträgt hier bis zu \(0.01pF\) bei
\(16MHz\) Taktfrequenz. Der Abgleich der Nullkapazität stellt bei dieser Auflösung eine besondere Herausforderung dar.
Die samplingADC Methode des Kapazitätsbestimmung wurde immer angewendet, wenn es Bruchteile von \(1pF\) dargestellt werden.
Übrigens können auch die Sperrschichtkapazitäten von Einzeldioden mit dieser Methode gemessen werden. Da die Methode
die Kapazität sowohl beim Laden als auch beim Entladen messen kann, werden zwei Kapazitätswerte angegeben. Wegen
des Kapazitätsdioden-Effektes unterscheiden sich die beiden Werte.

\section{Messen von Spulen}
Das angewandte Verfahren zum Messen der Induktivität besteht aus einer Zeitkonstantenbestimmung des Stromanstiegs.
Die Detektionsgrenze ist hier \(0.01mH\), wenn der Widerstandswert der Spule kleiner \(24\Omega\) beträgt.
Bei größeren Widerstandswerten beträgt die Auflösung nur \(0.1mH\).
Bei Widerstandswerten über \(2.1k\Omega\) kann die Methode gar nicht angewendet werden. 
Die Ausgabewerte der normalen Messung erscheinen in der zweiten Zeile (Widerstand und Induktivität).
Mit dem samplingADC Verfahren können bei größeren Spulenwerten Eigenresonanzen festgestellt werden.
Wenn diese deutlich genug ist, wird die Frequenz und die Güte Q zusätzlich zu der normalen Messung in Zeile 3 ausgegeben.

Daneben läßt sich diese Methode der Schwingfrequenz-Messung auch für die Bestimmung des Induktivitätswertes benutzen,
wenn ein ausreichend großer Kondensator mit bekanntem Kapazitätswert einer Spule mit kleiner Induktivität (\textless~\(2mH\))
parallelgeschaltet wird. Durch die Parallelschaltung des Kondensators funktioniert die normale Messung der
Zeitkonstante nicht mehr. Die Induktivität der normalen Messung wird gar nicht ausgegeben und der
Widerstandswert wird in der ersten Zeile ausgegeben, wenn die Resonanzfrequenz eine Parallelschaltung
des Kondensators erwarten lässt. Auch für diesen Fall wird eine Güte Q aus den Schwingverhalten berechnet.
Für diesen Fall wird die berechnete Induktivität an erster Stelle in Zeile 2 angegeben. Dahinter steht dann
der Text " if " gefolgt von dem Kapazitätswert des Parallelkondensators. Der Wert dieses Kondensators kann derzeit
nur in der Kalibrationsfunktion durch Messung festgelegt werden (\mbox{1 \electricC 3 \(10-30nF\)(L)}) .
Die dritte Zeile zeigt wieder die Schwingfrequenz und die ermittelte Güte Q. 
Bei zweizeiligen Displays wird der Inhalt der 3. Zeile zeitverzögert in Zeile 2 ausgegeben.

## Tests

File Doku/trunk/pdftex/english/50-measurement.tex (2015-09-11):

\chapter{Description of the measurement procedures}
\label{sec:measurement}
The simplified schematic of a Input/Output-Port pin of the ATmega is shown in figure~\ref{fig:port}.
The PUD switch isolates all ``pull up'' resistors of the ATmega. The output of a pin can be switched off
with the DD switch. The Input can operate regardless to the state of the switch DD.
The PORT switch usually defined the output level, but also switches the pull up resistor.
Because the Switches PORT and DD can not be changed at the same time but only one after another, the
pull up resistors can disturb the measurement. Therefore I prefere to disable the pull up resistors with the
PUD switch.
Of course all the switches are electronic type and the resistors \(19\Omega\) and \(22\Omega\) are approximated values.

\begin{figure}[H]
\centering

\caption{simplified diagram of each ATmega port pin}
\label{fig:port}
\end{figure}

Every of the three terminal probes of your Transistor Tester is build with three ATmega port pins,
which is shown as simplified diagram for the terminal probe TP2 (middle of three pins) in figure~\ref{fig:terminal}.

\begin{figure}[H]
\centering

\caption{simplified circuit of each measurement terminal probe TP}
\label{fig:terminal}
\end{figure}

Every test pin (measurement port) can be used as digital or analog input. This measurement capability is
independent of using the port as output.
Every test pin can be switched to output and in this mode it can be directly connected to GND (\(0V\)) or VCC (\(5V\)), 
or it can be connected via a \(680\Omega\) resistor or a \(470k\Omega\) resistor to either GND or VCC.
Table \ref{tab:case} shows all possible combination of measurements.
Notice, that the positive state can be switched directly to VCC (Port C) or it can be connected with the 
\(680\Omega\) resistor to VCC (Port B). The same possibility has the negative state of terminal probe to the GND side.
The test state means, that probe can be open (Input), connected with the \(470k\Omega\) resistor to VCC or GND,
or that the probe can be connected with the \(680\Omega\) resistor to VCC or GND.

\begin{table}[H]
  \begin{center}
    \begin{tabular}{| l | c | c | c |}
    \hline
      & state pin 1 & state pin 2 & state pin 3 \\
    \hline
   1. & positive    &  negative    &  test \\
   2. & positive    &  test       & negative \\
   3. & test        &  negative    & positive \\
   4. & test        &  positive    & negative \\
   5. & negative     &  test       & positive \\
   6. & negative     &  positive    &  test  \\
    \hline
    \end{tabular}
  \end{center}
  \caption{all combinations of measurement}
  \label{tab:case} 
\end{table}

If the capacitor measuring is configured for the tester, the tester will try to discharge the capacitors connected at all
test pins.
If discharge will fail, that means the remaining voltage is to high, the discharging will be aborted after about 12 seconds
with the meassage ''Cell!''. This can also be happen, if no capacitor is connected to any test pin.
The cause for this can be, that the cut-off voltage is choosed to low for this ATmega.
You can choose a higher voltage with the Makefile option CAP\_EMPTY\_LEVEL.

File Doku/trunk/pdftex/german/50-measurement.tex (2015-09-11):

\chapter{Beschreibung des Messverfahrens}
\label{sec:measurement}
Ein vereinfachtes Schaltbild eines Eingangs-/Ausgangs-Pin des ATmega wird in Abbildung~\ref{fig:port} gezeigt.
Der Schalter PUD schaltet die Versorgung für alle ,,Pull Up''-Widerstände des ATmega ab.
Mit dem Schalter DD kann der Ausgang abgeschaltet werden, der Eingang funktioniert sowohl im Ausgabe- wie im
Eingabe-Modus. Im Eingabe-Modus wird mit dem Ausgabewert (PORT) der ,,Pull Up''-Widerstand des Eingangs mit geschaltet.
Die beiden Schalter PORT und DD können nicht gleichzeitig, sondern nur nacheinander geschaltet werden.
Weil beim Umschalten der ,,Pull Up''-Widerstand die Messung stören könnte, bevorzuge ich die komplette
Abschaltung aller ,,Pull Up''-Widerstände mit dem PUD-Schalter.
Natürlich sind die Schalter elektronisch und die Widerstände \(19\Omega\) und \(22\Omega\) sind angenäherte Werte.
\begin{figure}[H]
\centering

\caption{Vereinfachtes Schaltbild jedes ATmega-Portpins}
\label{fig:port}
\end{figure}

Jeder der drei Testpins Ihres TransistorTesters wird aus drei ATmega-Portpins gebildet,
was im vereinfachten Schaltbild des Testpins TP2 (mittlerer der drei Pins) in Abbildung~\ref{fig:terminal} gezeigt wird.

\begin{figure}[H]
\centering

\caption{Vereinfachtes Schaltbild des Testpins TP2}
\label{fig:terminal}
\end{figure}

Jeder Testpin (Messport) kann als digitaler oder analoger Eingang benutzt werden.
Diese Mess\-fähig\-keit ist un\-abhän\-gig von der Verwendung des Ports als Ausgang.
Jeder Testpin kann als Ausgang verwendet werden und in diesem Zustand mit GND (\(0V\)) oder VCC (\(5V\)) verbunden werden,
oder er kann über die Widerstände (\(680\Omega\) oder \(470k\Omega\)) mit entweder GND oder VCC verbunden werden.
Tabelle \ref{tab:case} zeigt alle denkbaren Messmöglichkeiten.
Beachten Sie, dass der positive Zustand durch direktes Verbinden mit VCC (Port C) oder
durch Verbinden mit dem \(680\Omega\) Widerstand mit VCC (Port B) erreicht werden kann.
Die gleiche Möglichkeit hat der negative Zustand des Testpins zu der GND-Seite.
Der Test-Zustand meint, dass der Pin offen sein kann (Eingang), verbunden über den \(470k\Omega\)-Widerstand
mit VCC oder GND, oder der Pin kann über den \(680\Omega\)-Widerstand mit VCC oder GND verbunden sein.

\begin{table}[H]
  \begin{center}
    \begin{tabular}{| l | c | c | c |}
    \hline
      & Zustand Pin 1 & Zustand Pin 2 & Zustand Pin 3 \\
    \hline
   1. & positiv    &  negativ   &  test \\
   2. & positiv    &  test      & negativ \\
   3. & test       &  negativ   & positiv \\
   4. & test       &  positiv   & negativ \\
   5. & negativ    &  test      & positiv \\
   6. & negativ    &  positiv   &  test  \\
    \hline
    \end{tabular}
  \end{center}
  \caption{alle Messmöglichkeiten}
  \label{tab:case} 
\end{table}

Wenn die Kondensatormessung des Testers konfiguriert ist, versucht der Tester vor allen Messungen erst einmal,
die Kondensatoren an allen Anschlusspins zu entladen. Wenn das nicht gelingt, also die Restspannung zu hoch bleibt,
wird das Entladen nach etwa 12 Sekunden mit der Meldung ,,Cell!'' abgebrochen. Dies kann auch dann vorkommen, wenn
gar kein Kondensator angeschlossen ist. Die Ursache kann in diesem Fall sein, dass die Entlade-Grenzspannung für diesen
ATmega zu niedrig gewählt ist. Man kann eine höhere Restspannung mit der Makefile-Option CAP\_EMPTY\_LEVEL wählen.

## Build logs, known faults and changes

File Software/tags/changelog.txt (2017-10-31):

Geringerer Flash Benutzung mit Funktionen signed_diff und vcc_diff.
Maximale Anzahl der Auswahlzeilen für das Menü mit der Option MAX_MENU_LINES wählbar (Standard 5).
Einstellbarer Vorteiler für Frequenzmessung mit Option WITH_FREQUENCY_DIVIDER.
Keine Ausgabe von RDS bei IGBTs.
Zusätzliche Makefile Option NO_FREQ_COUNTER.
Anzeige  IDss mit der Option FET_Idss für JFETs, wenn unter 40mA.
Änderung der Anzeige bei unbekanntem Bauteil mit vielen Dioden.
Messung der Cut-off Spannung bei Verarmungs-FET und JFET (Pieter-Tjerk).
Fortschrittsanzeige durch Punktreihe beim Test (Pieter-Tjerk).
Bereich von get_log erweitert.
Analyse in sampling_lc und peaksearch überarbeitet. 
Zeit für Abbruch der Frequenzerzeugung auf 2s erhöht.
Vorbereitung zur Änderung der Portpin-Reihenfolge für TP1-TP3.
Zusätzliche CRLF auf serieller Schnittstelle, bei Option WITH_UART=2 mit Zeilennummer in Spalte 1. (MAURO)
1.12 / 22.01.2017
Zusätzlicher 470k bei der Hälfte der ESR Einzelmessungen.
Doppelte Ausgabe von Vloss bei 2-zeiligem Display verhindern.
Bei NPNp und PNPn Transistoren keinen Typ mit hFE < 5 automatisch wählen.
Unterstützung von ILI9341 Controllern (color Display 320x240).
ESR-Messung mit kürzeren Strompulsen für Kapazitäten > 20nF.
Vorbereitung für bessere Unterstützung anderer Frequenzen als 8 und 16 MHz.
Unterstützung für tschechischen Zeichensatz (Dank an Pavel Kanka). 
Optionales Menü für Einstellung der Vor- und Hintergrundfarbe.
Support für Color-kit mit ST7735 Controller und quer eingebautem Display (horizontal/vertikal vertauscht).
Unterstützung von anderen Quarzfrequenzen bei wait1000ms.
Unterstützung für Arduino UNO im Verzeichnis arduino_uno, strip-line shield in Hardware/ArduinoUno_shield.
Frequenzeinstellung in F-generator flexibler gestaltet.
Texte für fremde Sprachen in langXXX.h aus Transistortester.h ausgelagert. XXX = language
Auflösung des hFE auf 0.01 erhöht.
Detektion von BJT für Optokoppler ab hFE 0.1 angepasst.
hFE bzw. B bei bipolaren Transistoren mit einer Nachkommastelle.
Drehencoder-Test bei Mega328 nur mit Option WITH_ROTARX_CHECK.
Berichtigung der NO_NANO Option in DisplayValue wegen neuer femto "f" Einheit.
Verhindern des Quarztests für größere Kapazitäten.
Quarztest mit Option WITH_XTAL .
Unterstützung von Textdisplays mit anderer DD-RAM Adresse mit der Option DD_RAM_OFFSET=128 .
Verlegung der Messung der Kapazität des Kondensators für die Spulenmessung an das Ende der Kalibration.
Tausch von Counter1 compare match Interrupts wegen samplingADC (benutzt Counter1 compare match A mit).
Menü-Auswahl wird bis zu 6 Zeilen lang, wenn Platz auf dem Display ausreicht.
Überschreiben der Transistor-Icons bei 6x8 und 8x8 Font vermieden.
Optionsbits der samplingADC Funktion anders definiert, damit auch Assembler die Definitionen benutzt.
Funktion samplingADC für 8 MHz angepasst.
Funktion samplingADC für erhöhte Auflösung von Kapazitätsmessung von Pieter-Tjerk (16 MHz).
Problem mit DC_Pwr_mode in Sonderfunktions-Schleifen beseitigt.
Neuer Menüfunktion zum Setzen des Korrekturwertes für große Kapazitätswerte, C_H_KORR .
Kleine Korrekturen, besonders bei Kommentaren.
Die ADC-Ports für die Testfunktion können auch nicht bei 0 beginnen (- TP1).
Neue Organisation der Ausgabe zur Beschleunigung der Ausgabe (Menüfunktion).
Mehr Zeilenwechsel und Leerzeichen für die serielle Ausgabe
Erweiterung für 128x128 und 128x160 pixel Farbdisplay mit SPI Schnittstelle.
Erweiterung für 3-zeiliges DOGM LCD.
Überarbeitung der lcd_init Befehlsfolge für DOG-M (4-line, hflip, vflip).
Serielle Ausgabe für SSD1803 Controller MODE_1803_SERIAL=7 .
Wahlmöglichkeit für Schnittstelle bei Textdisplay (4-Bit parallel, SPI und I2C).
Neue Option LCD_ST7565_Y_START set eine Startzeile für den ST7565/ST7108/SSD1306/ST7920 Controller
Unterstützung des 3-line seriell Interfaces für den PCF8814 Controller.
Unterstützung für Displays mit PCF8812 und PCF8814 Controllern.
Option LCD_SPI_OPEN_COL für SPI Schnittstelle ohne direktes VCC Signal, nur Pull-Up.
Angabe Flußspannung der Schutzdiode von Transistoren auch für ATmega168.
Angabe Kollektor-Reststrom bei BJT auch für ATmega168.
Bei graphischen Displays kann mit der Option NO_LONG_PINLAYOUT die Darstellung der Transistorpins 
 "123=EBC" statt "1=E 2=B 3=C" gewählt werden.
Optimierung mit avr-gcc mit Linker-Option --relax
Bei der Transistoruntersuchung mit dem 470k Widerstand wird das Schalten kurz mit dem 680 Ohm Widerstand unterstützt. 
Option DC_PWR bestimmt die Batteriespannung, oberhalb derer der DC_Pwr_Mode eingeschaltet wird.
Korrekturfaktor bei der C*ESR@TP1:3 Kapazitätsmessung durch 2.5% höhere Spannung.
Auch bei C+ESR@TP1:3 wird negative Restspannung berücksichtigt.
Bei Kondensatormessung mit grosser Kapazität wird negative Restspannung berücksichtigt.
Bei "DC Pwr Mode" keine Zeitbeschränkung der Sonderfunktionen.
Bei graphischen Displays Pin-Belegung von Transistoren als "Pin 1=E 2=B 3=C" in extra Zeile.
Erkennung des "DC Pwr Mode" bei Batteriespannung unter 0.9V .
Zeitsteuerung bei GetESR für mega2560 (arduino) angepasst.
Wartezeit nach Batterie-Unterspannung von 2s auf 5s erhöht.
Wartezeit für Ir Bestimmung von Dioden verlängert wegen möglicher Kapazität.
Bestimmung von RDSon für E-MOS Transistoren mit ATmega328/644/1280.
Frequenz-Eingang für Arduino mega, ATmega2560 ergänzt, PE6 muß mit PE5 gebrückt werden.
Bei Messungen C+ESR, [RL], [C] und Spannungsmessung wird alle 16 Messungen die Batteriespannung geprüft. 
Der Kapazitäts- und  Widerstands-Modus sind für Prozessoren mit mehr als 32k Flash ohne Menü verfügbar.
Der Kapazitäts-Modus wird am Ende der 1. Zeile durch [C] angezeigt.
Der Widerstands-Modus wird am Ende der 1. Zeile durch [R] oder [RL] angezeigt.
Der ESR bei der Kapazitätsmessung im rechten Bildschirmbereich angezeigt, wenn meßbar.
Die Widerstandsmeßfunktion beinhaltet jetzt auch wählbar die Induktivitäten (Option RMETER_WITH_L).
Beim Kondensator-Meßmodus wird bei Displays mit mehr als 2 Zeilen auch Vloss angezeigt.
Bei Kondensatoren an TP1:TP3 wechselt das Programm automatisch in den Kondensator-Meßmodus,
 der durch Tastendruck wieder beendet wird.
Bei Einzelwiderständen an TP1:TP3 wechselt das Programm automatisch in den Widerstands-Meßmodus,
  bei Tastendruck wird der Modus beendet.
Bei kleinen Fonthöhen (<=8) sind 8 Zeilen auf den graphischen Display möglich.
Getrennte Kondensatormessung an TP1:TP3 ab 1pF über Menü wählbar.
Interne Struktur der Daten für die Widerstandsmessung geändert.
Getrennte Widerstandsmessung an TP1:TP3 mit Menü wählbar.
Bei BJT wird die Flußspannung der Schutzdiode mit angezeigt.
Bei D-MOS Transistoren wird auch die Gate-Kapazität gemessen.
Für den ST7108 Controller kann das CS1 / CS2 Signal invertiert werden.
Bei Fortsetzungszeile wird ein + als letztes Zeichen ausgegeben.
Die Anordnung der Meßparameter bei Transistoren wurde neu organisiert.
Bei BJT wird der Kollektor oder Emitterstrom ausgegeben, bei dem hFE gemessen wurde.
Bei Kondensatoren mit ESR wird der Widerstand auch als Symbol angezeigt bei 4-zeiligem Display.
Neuanordnung der gemessenen Parameter für graphisches Display, das Icon wird oben links gezeichnet.
Bei graphischen Display wird auf die zusätzliche Angabe der Pinbelegung und der Schutzdiode als Text verzichtet.
Interne Überarbeitung der Display-Font Parameter.
Tester kann nicht mehr ohne Abgleichkondensator kalibriert werden bei Zeitüberschreitung der C>100nF Schleife.
Überarbeitung der Icons und update bitmaps, großes Fragezeichen bei unbekannten Bauteil.
lcd_draw_trans_pins und lcd_draw_pin brauchen jetzt relative Adresse bezogen auf die Icon-Position.
ShowData Funktion um Demonstration der verwendeten Icons erweitert.
Die Funktion lcd_update_icon() arbeitet immer relativ zur letzten Icon Position.
Die Funktion lcd_big_icon() kann als Ziel eine der 4 Quadranten des LCD angeben. Standard = unten rechts.
SetCursor verwendet als vertikal Position (y) eine Auflösung von 8 Pixel, unabhängig von der Fonthöhe.
Verschiedene Versionen der Transistor-Icons sind mit ICON_TYPE wählbar (1=thin, 2=bold).
Die Spule wird bei graphischer Ausgabe mit zwei neuen Zeichen, beim Character-display mit "-ww-" gezeichnet.
Die Update Teile für die Transistor-Icons werden als bitmap mit relativer Lage + Größe (x+y) definiert.
Die Basis Transistor-Symbole werden als Icons in einem 24x32 pixel font definiert.
Unbenutze Teile der Font-Dateien wurden entfernt, die Lage der kyrillischen Zeichen verschoben.
Organisation der Fontdaten mit Höhe >8 geändert, zuerst alle oberen Daten, dann die unteren Daten.
Doppelte Beschreibung der Schutzdiode bei FET's entfernt, bei langer Form Uf der Diode in Zeile 4.
Bitmap für Testports größer und invers möglich, Option BIG_TP und INVERSE_TP.
Unterstuetzung des ST7108 Controllers mit einem seriell-parallel Wandler 74HC164.
Horizontal und vertical Flip per Software, nicht mehr mit ST7565 Befehl.
Auswahl fuer 8x12, 8x14, 8x15 und 8x16thin Fonts.
Unterstuetzung des ST7920 Controllers mit 4-bit parallel und seriell Interface.
1.11 / 07.02.2015
Die lcd_clear Funktion für den ST7565 Controller umgestellt.
Die Anzeigezeiten für das Impulsdrehgeber-Ergebnis verlängert.
Verkürzung des Strompulses der ESR-Messung von 27us auf 8us.
Sperrschichtkapazität bei Diode wird mit 2 Dezimalstellen ausgegeben. 3 Stellen nur bei LCD_LINE_LENGTH > 16 .
Schutzdiode wird bei graphischer Datestellung auch bei bipolaren Transistoren angezeigt.
Neue Optionen LCD_INTERFACE_MODE=2 und LCD_I2C_ADDR für die I2C Schnittstelle des SSD1306 Kontrollers.
Anpassung der Korrekturfunktion für die ESR-Messung kleiner Kapazitäten.
Spezielle Initialisierung des SSD1306 Kontrollers sowie Anpassung der Kontrasteinstellung.
Neue Option LCD_ST7565_H_OFFSET zur besseren Anpassung an die Lage des Displayfensters.
Bei Beginn des Selbsttest wird PartFound auf unerkanntes Bauteil gesetzt.
Fehler beim Freischalten der internen Pull-Up Widerstände beseitigt (no PULLUP-DISABLE).
Bei Menüfunktion Selbsttest wird der Selbsttest auch ohne verbundene Klemmen nach 30 s gestartet (ohne Nullwiderstand).
Bei Überschreitung des Nullwiderstandwertes wird auf Standard ESR_ZERO zurückgesetzt.
Vorzeichenfehler bei ShowData korrigiert.
Reihenfolge der ST7565 Befehle bei der Initialisierung geändert. 
Ohne die Option POWER_OFF gibt es keine Menüfunktion "Schalte aus".
Menüfunktion um Ausgabe der Kalibrationsdaten erweitert (ShowData).
Standard für Anschluß des Impulsdrehgebers auf PD1 und PD2 geändert.
Korrektur der Pinbelegungen für ATmega324/644/1284 .
FAKTOR_ESR für die ESR Korrektur kleiner Kapazitätswerte angepaßt.
Rücksetzen auf unkalibriert nur bei Kondensatoren > 4.5uF und negativem ESR.
Alle Bitmaps für den ST7565 Controller sind in bitmaps.h definiert.
Optimierte Bitmaps für den ST7565 Controller um Platz zu sparen.
Kondensator für Abgleich muß fünf Mal statt zwei Mal hintereinander erkannt werden.
Überlaufproblem bei GetESR (cap_val_nF) beseitigt.
Erkennung von JFET und BJT mit Reststrom nochmals verbessert.
Wartezeit vor der Ausgabe des Hilfetextes entfernt.
Unterstützung von 8x8 und 8x16 character Fonts für ST7565 Controller, Dank an Nick L. .
Kontrasteinstellung für ST7565 Controller als Menüfunktion.
5ms Wartezeit nach Cursor Home bei der LCD Initialisierung wegen Problem bei Diodensymbol.
Benutzung des internen Kalibrier-Kondensators für ATmega644/1284 .
Anpassung der Initialisierung von OLED Displays.
Externe Spannungsmessung nur mit der Makefile Option WITH_VEXT .
Für die höchste Auflösung bei Impulsdrehgebern ohne Rastung WITH_ROTARY_SWITCH=5 .
Die Vergangenheit der Drehgeber-Zustände wird nicht mehr bei jedem wait_for_key_ms Aufruf gelöscht.
Auch getrennte Up / Down Taster können anstelle des Drehimpulsgebers verwendet werden.
Der automatische Wechsel der Menüfunktion nach 5 Sekunden wurde deaktiviert.
Reihenfolge der Beispielfrequenzen geändert.
Unterstützung eines Drehimpulsgebers an PD2 und PD3 für mega328 für einfachere Menü-Bedienung.
Bei Frequenzmessung mit 4-zeiligem Display werden für Periodenmessung Zeile 3+4 genutzt.
Flip für ST7565 Kontroller horizontal und vertikal getrennt wählbar.
Für den Selbsttest wird der Kalibrationsteil mit dem externen Kondensator nur durchgeführt,
 wenn zum ersten mal kalibriert wird oder der Selbsttest mit der Menufunktion aufgerufen wird.
Menü-Funktion für vollständigen Selbsttest, bei Transistortester mit kurzgeschlossenen Testpins
  wird bei freigeschalteter Menüfunktion nur der Kalibrationsteil aufgerufen.
Menü-Funktion für Test von Impulsdrehgebern.
Unterstützung eines graphischen 128x64 LCD mit ST7565 Kontroller von Wolfgang Sch.
Unterstützung der italienischen Sprache LANG_ITALIAN.
Bei der Frequenzerzeugung wird als Zeitmarke ein Punkt für 30 Sekunden ausgegeben. 
Pinbezeichnungen bei TRIAC von GCA in G12 geändert.
1.10 / 09.04.2014
Bedienung der Menuefunktionen überarbeitet (Zeitsteuerung und POWER_OFF Option).
Erweiterung des Meßbereichs für separate C+ESR Messung, 2uF-50mF .
Vorbereitung zur Unterstützung von mega324/644/1284.
Zusatzabfrage in CheckPins wegen Falschdetektion von TRIAC als NPNp.
Separate C+ESR Messung auf TP1 und TP3 im Menü wählbar.
Prellunterdrückung in wait_for_key_ms() Funktion.
Korrekturen bei der Frequenzmessung, Auflösung der Frequenz bei niedriger Frequenz bis 1uHz.
Generator mit einstellbarer Pulsweite eingebaut (10-Bit PWM).
Makefile Optionen TQFP_ADC6 und TQFP_ADC7 für die Nutzung der zusätzlichen TQFP ADC Eingänge.
Die Periodenmessungsanteil der Frequenzmessung erfolgt mit anähernd gleicher Meßzeit.
Funktion DisplayValue unterstützt bis zu 7 Dezimalstellen.
Bei Frequenzmessung mit 1s Dauer wird der Counter mit ISR sowohl gestartet als auch gestoppt.
Überarbeitung der Frequenzgenerator-Funktion.
Extrafunktion Frequenzgenerator an TP2 über den 680 Ohm Widerstand.
Bei laufendem Timer1 wird der Schlafzustand nicht benutzt.
Extrafunktion Frequenzmessung an Pin PD4/T0, aber nur mit Serienwiderstand!
Extrafunktion Spannungsmessung (ohne Tastendruck, daher ohne DC-DC Wandler).
Menue für Extrafunktionen eingebaut (nur mega328 mit Option WITH_MENU).
Programm für Optionen WITH_SELFTEST und AUTO_CAL überarbeitet.
Unterstützung eines Mega2560 auf einem ARDUINO mit bootloader über USB.
Verwendung vom Assembler Makro AOUT für flexible Port-Auswahl.
Russische und Ukrainische Hilfetexte für mega328.
Vor der Messung eines Widerstandes mit GetESR wird erst die Induktivität gemessen.
Die Abgleichdaten im EEprom werden ohne USE_EEPROM im Programm initialisiert, wenn unbesetzt.
Alle mega328 Beispielkonfigurationen sind ohne USE_EEPROM konfiguriert.
Automatische Konfiguration vom Mega168 an den vorhandenen Speicherplatz angepaßt.
Bei Mega328 wird das UART bei Start deaktiviert wegen möglicherweise vorgeschaltetem Bootloader. 
Organisation der Kalibrierwerte vereinfacht.
Speicherbelegung von DisplayValue.c optimiert und Makefile für alle Versionen angepaßt.
Unterscheidung von Verarmungs-FETs und Anreicherungs-Fets/ bipolare Transistoren angepaßt.
wait_for_key_ms als Speicher optimierte Assembler-Version.
sleep_5ms mit verändertem Aufruf in C und Assembler Version.
getlog als eigene Datei in C und Speicher optimierte Assembler-Version.
TRIAC Erkennung erweitert, falsche Erkennung mit vertauschtem GC Anschluss als Thyristor wird vermieden.
Alle Makefiles auf geänderte Binde-Reihenfolge und Assembler Versionen umgestellt.
config.h in config.h und autoconf.h geteilt, config.h enthält die änderbaren Parameter.
Funktionen  lcd-routines und PinLayout als opimierte Assembler Versionen.
Reihenfolge der Objekt-Dateien beim Binden optimiert wegen rcall statt call.
Funktion i2lcd und u2lcd eingebaut, Assembler und C-Version
Fehler aus RvalOut.S beseitigt.
Der unkalibrierte Tester wird durch einen aktivierten Cursor angezeigt, ? character entfällt.
GetRLmultip.S kann Tabelle im EEprom oder Flash zugreifen, mega168 und mega8.
Slovakischer Hilfetest für unkalibrierten Tester ergänzt.
Für unkalibriert wird in 1. Zeile ein Fragezeichen an 16. Stelle statt Ausrufezeichen in 2. Zeile ausgegeben. 
Problem bei Pinreihenfolge bei Thyristorerkennung beseitigt.
Funktionen GetRLmultip, UfAusgabe, RvalOut und Refvoltage als getrennte C und Assembler-Version.
Für mega328 kann die Pinbelegung von Port B für die Widerstände in config.h frei gewählt werden.
Bei mega328 wird als Kennung für einen Widerstand bei der Diodenmessung ein Symbol statt R genommen.
Kombination von Dioden und Widerstand wird erkannt und nacheinander ausgegeben,
damit wird ein BU508D als zwei Dioden (BC und EC) und ein Widerstand (BE) gemessen.
Diodentest bei mega168/328 erweitert, damit Schutzdioden bei D-MOSFET erkannt werden.
Spannungsgrenze von .488 auf .599mV in Checkpins geändert wegen Erkennung von D-MOS mit Schutzdiode.
Anreicherungs IGBTs werden erkannt, Belegung PartMode angepasst.
Ausgabe von Kollektor-Restströmen für ATmega328, falls nicht Null.
Erkennung von bipolaren Transistoren mit Kollektor-Reststrom verbessert (Unterscheidung von JFET).
Bei Kapazitätsmessungen wird bei Unterschreiten der Nullkapazität um 20pF auf unkalibriert zurückgesetzt.
Beim mega328 wird beim unkalibrierten Tester ein Hilfetext zur Kalibration vor dem Abschalten angezeigt.
Unkalibrierter Tester wird durch ein ! Zeichen vor der Testen... Meldung angezeigt.
Grenze für Nullkapazität von 90pF auf 190pF angehoben (wegen Anschluss einer SMD-Pinzette).
Unterverzeichnisse fuer FiFi und Funkamateur Versionen mit Knopfzelle oder LiPo Akku.
Thyristor und Triac mit Gate-Spannungsausgabe.
Anpassungen bei der Transistorerkennung für parasitäre Transistoren NPNp und PNPn.
Spannungsteiler Verhaeltnis für Batteriespannung und Zener-Spannung in config.h und Makefile aenderbar.
1.09 / 30.11.2013
Beseitigung des Ueberlaufproblems bei der Ladezeitmessung in ReadCapacity mit Sleep Mode.
Die Art der Zaehler-Ueberlaufbehandlung in ReadCapacity mit Sleep Mode geaendert.
Programmierfehler bei der Kalibration der Nullkapazitaet beseitigt.
Vorbereitungen fuer Untersuchungen mit alternativen Messwiderstaenden 330/100k.
Zwei LED werden auch dann erkannt, wenn Schwellspannung >2V und keine gemeinsame Anode oder Kathode.
Mit der Makefile Option NO_TEST_T1_T7 werden die Selbsttests T1 bis T7 weggelassen für eine schnellere Kalibration.
Die Makefile Optionen NO_COMMON_EMITTER_HFE und NO_COMMON_COLLECTOR_HFE ergänzt, um gezielt
eine der beiden Meßmethoden wegzulassen. Beim ATmega168 wird dann der Selbsttest T1 bis T7 benutzt.
Für den ATmega168 werden beide hFE Messungen verwendet, dafür entfallen die Selbsttests T1 bis T7 .
Ergänzung der litauischen Sprache LANG_LITHUANIAN.
Der Selbsttest muss jetzt mit Tastendruck quittiert werden, sonst normale Messung.
Anpassung der Diodenerkennung, Begrenzung der Spannungsdifferenz.
Display-Anzeigezeit in der Dokumentation auf 28 Sekunden berichtigt.
1.08 / 1.10.2013
Bei BAT_POOR Pegel unter 3.25V ist der Warnpegel nur 0.2V höher. (Die Grenze war vorher bei <=2.9V).
Die Ueberpruefung der Ausgangs-Widerstandswerte in Calibrate_UR.c wurde entfernt.
Unterstuetzung von DOG-M LCDs mit ST7036 controller mit Makefile Option LCD_DOGM .
Neue Unterverzeichnisse mega328 und mega328_strip_grid für ATmega328 Daten.
Ergänzung der russischen und ukrainischen Sprache.
Wegen Speichermangel wird die Stromverstärkung nur beim mega328 in Kollektor und Emitterschaltung gemessen.
Bei der Bestimmung des Stromverstärkungsfaktor in Emitterschaltung wird der Kollektor-Reststrom berücksichtigt.
Bei Einzeldioden wird auch der Reststrom in Sperrichtung gemessen, der Text Diode entfällt.
Grenze für die Erkennung von Verarmungs FET von 92 auf 455 erhöht wegen Restströmen bei Germanium Transistoren.
Abhängigkeit von IGBT Erkennung als E-MOS von der gewählten Pinbelegung beseitigt.
Ergänzung der portugiesischen Sprache LANG_BRASIL .
In Makefile den Parameter BitClock fuer avrdude eingebaut zur Anpassung der Programmiergeschwindigkeit.
Reihenfolge 470k/680 Ohm Test bei Dioden vertauscht und vorherige Entladung wegen Falscherkennung von Elkos.
1.07 / 19.04.2013
Makefile Option NO_NANO ergänzt.
Funktion GetVloss fuer Kondensatoren mit mehr als 5nF erweitert, vorher 50nF.
Beim Selbsttest wird das Loesen des Kurzschluss bei Test 4 ueberwacht, AllProbesShorted von Markus R.
Die Funktion GetESR wird beim Abgleich benutzt, um den Nullwiderstand zu bestimmen (pin-abhaengig).
Funktion GetESR wird auch fuer Widerstandswerte unter 10 Ohm benutzt.
Funktion GetESR durch neue Assembler Funktion ersetzt.
Neue Funktion GetVloss, um den Spannungsverlust nach einem Ladepuls bei Kondensatoren kleiner 45uF zu messen.
Die Funktion GetESR auf Assembler umgestellt, um die Zeitfolge unabhaengig von Optimierung des Kompilers zu machen.
Belegung von Flash und EEprom Speicher optimiert.
BAT_POOR Pegel in der Makefile auf mV Angabe umgestellt, bei Angabe unter 1.3V  nur +0.1V Warnung.
ESR-Messung fuer Kondensatoren ab 0.45uF mit 500kHz ADC Clock ergaenzt.
Die Aufloesung der Induktivitaetsmessung wird mit 680 Ohm Widerstand auf 0.1mH gesetzt.
Die Pinreihenfolge bei Einzeldioden wird bei ATmega168/328 entsprechend EBC_STYLE ausgegeben.
1.06 / 23.2.2013
Das My und Omega Zeichen werden bei der seriellen Ausgabe durch u und Ohm ersetzt.
Baudrate für serielle Ausgabe ist 9600 unabhängig der Taktrate.
Korrekturen systematischer Fehler bei der Induktivitätsmessung eingebaut.
Ermittlung der Pin-Ausgangswiderstände vor jeder Messung bei Option AUTO_CAL.
Pinbelegung auch in der Form 321= moeglich mit Option EBC_STYLE=321 .
Beseitigung Compiler Warnung in ReadCapacity.
Warteschleife bei automatischer Abschaltung für Dauerbetrieb geeignet.
wait mit sleep in den lcd-routines verwendet.
Pinbelegung in 123= Form auch bei mega8 möglich.
Thyristor und Triac Pinbelegung in 123= Form wie bei Transistoren.
Sleep bei der Zeitkonstantenmessung mit Counter 1 eingebaut.
Option INHIBIT_SLEEP_MODE zum Abschalten des Schlaf Modus eingebaut.
1.05 / 19.01.2013
Die GetESR Routine wurde überarbeitet und für den 16MHz Betrieb angepasst.
Die 2.5V Referenz wird mit Ausgang PC4 nach der Messung auf GND gezogen,
damit kann ein Relais mit zwei Ruhekontakten zum Schutz der Eingänge geschaltet werden.
Die VCC Spannungsausgabe in Zeile 2 erscheint nur bei der ersten Messung.
Selbsttest 7 misst das Spannungsverhältnis von 680/470k .
ADC Messung mit noise reduction sleep Modus für mega168 und mega328.
Absenkung des Stromverbrauchs bei Wartezeit durch sleep Modus für mega168 und mega328.
BAT_POOR Schwelle kann auch unter 5.4V gesetzt werden wegen step up Wandler Versorgung.
CombineII2long ersetzt durch union Schreibweise.
Testausgabe fuer die Bestimmung der Spannungshöhe für digitalen Input (Zeile 3+4, deaktiviert).
Einbau einer anderen Methode der MOS Vth Spannungsmessung (deaktiviert).
1.04 / 01.12.2012
Die Texte in ReadMe.txt und LiesMich.txt ueberarbeitet.
Kommentare im Konfigurationsteil der Makefile ueberarbeitet.
Ausgabeformat für die Pinbelegung von Transistoren von EBC= auf 123= geaendert
Fehlender interner Pull-Up an Start-Pin ergaenzt.
Bei Version ohne Abschaltung ist die Anzeigezeit auf 14s verlaengert
Ergaenzung der Niederländischen Sprache
1.03 / 23.11.2012
Makefile für ATmega8 mit Option WITH_AUTO_REF.
Standardwert für Referenzspannung des ATmega8 nach Messung mit 9 Exemplaren geändert.
Optionen C_MESS und R_MESS aus der Makefile entfernt.
Ausgabe der VCC Spannung separat in 2. Zeile für eine Sekunde, wenn Präzisionsreferenz erkannt.
1.02 / 01.11.2012
LCD Pin Belegung frei wählbar für Streifenleiterplatine (Dank an Stephen E.)
Meßverfahren ohne 680 Ohm Widerstand für Induktivitäten bis zu einem Widerstand von 24 Ohm (vorher 8 Ohm).
Bei erkannter Diode wird kein Widerstand mehr gesucht (MBR 3045 Problem).
1.01 / 19.10.2012
Induktivitätsmessung nur bei Widerständen kleiner als 2100 Ohm.
ESR Messung  mit Nullabgleich bei "negativem" Widerstand (ESR=?).
Voreinstellung des Nullwertes der ESR-Messung in der Makefile.
Bei Induktivitätsmessung Null-Offset abhängig von 680 Ohm Widerstand.
Vermeidung von negativen Werten fuer "unsigned int" Spannungen bei Kapazitätsberechnung.
ESR-Messung ab 2 uF , kapazitätsabhaengiger Fehler durch Zeitverzug der Einzelmessungen kompensiert.
Organisatorische Änderungen zum Trennen von Programmteilen.
ESR-Messung für Kondensatoren ab 4 uF.
Ergänzung einer ESR-Messung für Kondensatoren über 50 uF (nur mega168 und mega328).
1.00 / 23.09.2012
Messung von Induktivitäten auch ohne 680 Ohm Widerstand, wenn Widerstandswert unter 8 Ohm.
Messung der Spannung bei Widerständen erst, wenn keine Änderung oder Abbruch bei Zeitüberschreitung.
Messung von Induktivitäten > 1mH eingefügt, der Wert wird zusätzlich zum Widerstandswert ausgegeben.
VCC Spannungsabhängigkeit der Kondensatormessung kompensiert.
Verarbeitung der 2.5V Spannungsreferenz, um korrekte VCC Spannung zu verarbeiten.
Bei Selbsttest 10-11 wird nur der Korrekturwert für den Komparatoroffset ausgegeben und
wenn die AUTOSCALE_ADC Funktion gewählt wurde, der Korrekturwert für die interne Referenz.
Bei Selbsttest 9 werden die gefundenen Nullwerte der Kapazitätsmessung ausgegeben.
Die Selbsttest-Funktion 7 und 8 werden nur noch die Port-Innenwiderstände in Ohm ausgegeben.
Die Selbsttestfunktionen 7-11 werden separat mit der AUTO_CAL Funktion angewählt und die
gefundenen Werte im EEprom festgehalten.
Die Wiederholanzahl für Selbsttest Nr. 1-6 wurde auf 4 reduziert.
Die Beschränkung für hFE < 65536 entfällt.
Die Option UF_OUT_MV entfällt.
Die Funktion value_out wurde durch die Funktion DisplayValue ersetzt, Dank an Markus Reschke!
Der CAP_EMPTY_LEVEL wurde in der Makefile von 3 auf 4 angehoben.
Wegen der einstellbaren VCC Spannung die Ausgabe der Selbsttest-Funktion auf Differenzen umgestellt.
Für die Widerstandmessung kann die Auflösung der ReadADC-Funktion um Faktor 4 angehoben werden.
Neue ReadADC Funktion mit einstellbarer VCC Spannung und frei wählbarer ANZ_MESS.
Erweiterung der Autokalibration für AUTOSCALE_ADC (Widerstandsmessung, REF_R_KORR).
Beim avrdude Aufruf für das fuse Setzen beim ATmega328 in der Makefile wird auch efuse gesetzt.
0.99 / 15.08.2012
Autokalibration fuer Kondensatormessung < 40µF (REF_C_KORR).
Ausgabeformat fuer FET Schwellspannung in V.
Makefile und config.h für die PicoPower Prozessorvariante -P angepaßt.
Abgleich der Pin-Ausgangswiderstände bei Selbsttest ergaenzt.
Nullabgleich fuer Kondensatormessung bei Selbsttest ergänzt.
Beseitigung der Ursache fuer falsche Pinnummern-Anzeige bei Widerstandsmessung (Dank an Markus Reschke).
Fuer den Serienmessung kann die Anzeige der Messung verlaengert werden, wenn der Startknopf lang gedrueckt wird
(modifizierter Vorschlag von Markus Reschke).
0.98 / 26.07.2012
Für große Kondensatoren wird der Spannungsverlust während der Ladezeit berücksichtigt.
Beseitigung des rcall & call Problems bei ReadADC.S für den ATmega168
Erweiterung und Anpassungen für 16 MHz Takt Betrieb.
Anpassung des Null-Wertes für die Kondensatormessung für die Platinen-Version 5.2.1 .
Korrektur des Überlaufproblems bei der Kondensatormessung (etwa 6uF bis 11uF).
Verbesserung der Widerstandsmessung im mittleren Bereich.
Korrektur der ANZ_MESS Steuerung (ANZ_MES).
0.97 / 09.06.2012
erste Transistortester Version im svn Archiv

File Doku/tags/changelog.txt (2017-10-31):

Beschreibung maximale Anzahl der Auswahlzeilen für das Menü mit der Option MAX_MENU_LINES wählbar (Standard 5).
Beschreibung einstellbarer Vorteiler für Frequenzmessung mit Option WITH_FREQUENCY_DIVIDER.
Ergänzung einiger Makefile Optionen beim Konfigurations-Kapitel.
Zusätzliche Makefile Option NO_FREQ_COUNTER.
Erkennung von IGBTs mit Batterie in der Gate-Zuleitung beschrieben.
Berechnung von Idss bei JFETs beschrieben und Beispiele ergänzt.
Meßbeispiele für kleine Induktivitäten ergänzt.
1.12 / 18.02.2017
Beschreibung des zusätzlichen 470k Widerstandes bei der Hälfte der Einzelmessungen.
Doku für ESR-Messung von Kondensatoren >20nF imit 2us Pulsen ergänzt.
Vorschlag für eine verbesserte Relais Schutzschaltung ergänzt.
Beschreibung von zwei chinesischen Bausätzen ergänzt.
Beschreibung der Option DD_RAM_OFFSET für bestimmte Text-Displays.
Kurze Beschreibung zum SamplingADC Verfahren im Kapitel Messverfahren.
Erweiterung der Eigenschaften und Bedienungshinweise Kapitels, SamplingADC.
Beschreibung der SHORT_UNCAL_MSG Option.
Beschreibung der WITH_SamplingADC Option.
Beschreibung für Farbdisplay 128x128 und 128x160 ergänzt.
Beschreibung SPI und I2C für Textdisplay ergänzt (Tabelle).
Beschreibung der Option LCD_ST7565_Y_START ergänzt.
Beschreibung für Anschluß von graphischen PCF8812 und PCF8814 Controllern.
Beschreibung der chinesischen LCD-T4 Platine mit graphischem Display.
Beschreibung der LCD_SPI_OPEN_COL Option für die SPI Schnittstelle.
Beschreibung der chinesischen WEI_M8 platine.
Trennung der Display-Pinbelegungstabelle in normal und STRIP_LINE_BOARD.
Erwähnung des RDSon Wertes bei E-MOS Transistoren.
Ergänzung der Beschreibung der Option NO_LONG_PINLAYOUT.
Beschreibung der Option DC_PWR (obere Grenze der Batterieversorgung).
Schaltung für arduino mega (ATmega2560) ergänzt.
Zusätzliche Filterung in VCC Zuleitung von SSD1306 Display ergänzt.
Beschreinung der Fish8840 Änderungen ergänzt.
Neue Menü-Punkte für Ohmmeter und Kondensator-Meßfunktion.
Beschreibung der automatischen Kondensator-Meßfunktion.
Beschreibung der automatischen Ohmmeter-Funktion.
Beschreibung Anschluß SSD1306 mit I2C Schnittstelle.
Beschreibung der Optionen BIG_TP und INVERSE_TP.
Problem mit der Erkennung einer Schutzdiode bei bipolaren Transistoren (Germaniun) mit hohem Reststrom ICE0 beschrieben.
Entwurf eines Interface fuer ein Display mit ST7108 Controller durch einen 74HC164 Chip.
Anschluß eines graphischen Displays mit ST7920 Controller ergaenzt.
1.11 / 07.02.2015
Beschreibung des Impulsdrehgebertests erweitert.
Beschreibung der Programmierung erweitert.
ESR-Messung mit 8us Pulsen dokumentiert.
Beschreibung der Optionen für SSD1306 Kontroller mit I2C Schnittstelle:
 WITH_LCD_ST7565=1306, LCD_INTERFACE_MODE=2 und LCD_I2C_ADDR.
Neue Option LCD_ST7565_H_OFFSET zur besseren Anpassung der horizontalen Displayfenster-Lage.
Beschreibung ESR-Messung überarbeitet.
Beschreibung der Funktionen Kontrast und Zeige Daten ergänzt.
Pinbelegung des Impulsdrehgebers auf PD1 (LCD-D5) geändert.
Beschreibung der Pinbelegung von Displayports für verschiedene ATmega.
Beschreibung der erweiterten Schaltung mit ATmega644/1284 .
Beschreibung des Anschluß eines grafischen Displays mit ST7565 Kontroller. 
Beschreibung der Makefile Option WITH_VEXT für die externe Spannungsmessung ergänzt.
Impulsdrehgeber Typ 4 für Up/Down Taster und Typ 5 für höchste Auflösung des Drehgebers.
Beschreibung des Zusatzes Impulsdrehgeber für die Menübedienung ergänzt.
Abgleich der Quarz Frequenz mit 1PPS Signal eines GPS-Empfängers ergänzt.
Im Vorwort: Dank an weitere Personen eingebaut.
Beschreibung für den ST7565 Kontroller (Optionen) ergänzt.
Beschreibung der Zusatzfunktion Selbsttest, vollständiger Test nur mit Menü-Funktion,
 wenn mit Menü, macht direkter Selbsttest nur Kalibration mit externem Kondensator nur beim ersten Mal.
Beschreibung der Zusatzfunktion Impulsdrehgeber.
1.10 / 09.04.2014
Einige Fehler mit größer und kleiner Zeichen beseitigt.
Das Kapitel Bedienung wegen Menuefunktion überarbeitet.
Das Kapitel Eigenschaften überarbeitet wegen Menuefunktionen.
Beschreibung des Meßverfahrens für separate C+ESR Messung.
Zusatzabfrage wegen Falschdetektion von TRIAC als NPNp ergänzt.
Beschreigung des Frequenzgenerators und des Pulsweitengenerators.
Beschreibung der Makefile Optionen TQFP_ADC6 und TQFP_ADC7 ergänzt.
Beschreibung des Verfahrens der Frequenzmessung ergänzt.
Beschreibung der Auswahl von Zusatzfunktionen mit der Menü-Funktion: Frequenzmessung Frequenzgenerator
Änderung bei der Erkennung von Verarmungstypen im Ablaufplan geändert.
Ablaufplan für Thyristor und TRIAC Erkennung ergänzt.
Beschreibung der Cursor Aktivierung bei unkalibrierten Tester ergänzt.
Transistor Messbeispiele in einer ttinfo.pdf gezeichnet.
Korrektur Ablaufplan wegen D-Mos Erkennung.
Ablaufplan um IGBT Erkennung erweitert
Beschreibung der Ausgabe von Kollektor Restströmen.
Ablaufplan der Transistortests angepaßt.
Beschreibung Kollektor-Reststrom Untersuchung für Germanium und JFET.
Vereinfachter Ablaufplan der Transistor-Tests ergänzt.
1.09 / 30.11.2013
Beschreibung der Makefile Optionen NO_COMMON_COLLECTOR_HFE, NO_COMMON_EMITTER_HFE und NO_TEST_T1_T7 .
Ergänzung der litauischen Sprache.
Hinweis auf das notwendige Drücken des Start-Tasters zum Starten des Selbsttests ergänzt.
Berichtigung der Display-Anzeigezeit auf 28 Sekunden.
1.08 / 1.10.2013
Bei BAT_POOR Pegel unter 3.25V ist der Warnpegel nur 0.2V höher.
Ergänzung der LCD_DOGM Option im Konfigurations-Kapitel.
Ergänzung der Russischen und Ukrainischen Sprache.
Beschreibung für Stromverstärkungsfaktor in Kollektor und Emitterschaltung angepasst.
Beschreibung der Reststrommessung bei Einzeldioden ergänzt.
Grenze für die Erkennung von Verarmungs FET angepasst.
Ergänzung der protugiesischen Sprache LANG_BRASIL  
Ergänzung des Parameters BitClock für avrdude bei der Konfiguration in der Makefile.  
Ergänzung von Programmers Notepad Abbildungen im Hardware-Kapitel.
Ergänzung von ESR-Messungen verschiedener Elektrolyt-Kondenstoren.
1.07 / 19.4.2013
Beschreibung der Option NO_NANO ergänzt.
Unterkapitel der Kondensatormessung zu Spannungsverlust Vloss ergänzt.
Widerstandsmessung kleiner 10 Ohm mit neuer ESR-Meßmethode als Tabelle ergaenzt.
Kalibrationsanweisungen und Eigenschaften an die neue ESR-Messung angepasst.
Neue ESR-Meßmethode beschrieben mit Meßbeispielen.
Umstellung BAT_POOR Pegel auf mV Einheiten beschrieben, bei unter 1.3V nur 0.1V Warnoffest.
ESR-Messung ab 0.45uF mit 500kHz ADC Clock mit Messbeispielen beschrieben.
Beschreibung der Auflösung der Induktivität 0.1mH oder 0.01mH ergänzt.
1.06 / 23.2.2013
Beschreibung Option REF_L_KORR ergänzt.
Wahlmöglichkeit für Pinbelegung 321=... ergänzt.
Option externe Spannungsmessung im Hardware-Kapitel und bei Konfiguration ergänzt.
Fehler mit fehlendem Pull-Up im Hardware-Kapitel ergänzt.
Unterkapitel China Clone im Hardware-Kapitel ergänzt.
Unterkapitel Umrüstung alter Tester im Hardware-Kapitel ergänzt.
Tippfehler bei ESR-Messdaten beseitigt.
Beschreibung der Option INHIBIT_SLEEP_MODE im Konfigurationsteil ergänzt.
1.05 / 19.01.2013
Erweiterung mit Relais-Schutz im Hardware-Kapitel ergänzt.
Oszillogramm der ESR-Messung eines 4.4uF Kondensators ergänzt.
Seriell Ausgang PC3 in Schaltplan ergänzt.
Ergänzung der Option RESTART_DELAY_TICS für den Schlafmodus ohne Quarz.
Ergänzung der Dokumentation Selbsttest Spannungsteiler 470k/680 .
Fehlersuche Hardware um Hinweis mit LED ergänzt.
Oszilloskop Bild des 50Hz Testsignals ergänzt (Selbsttest).
Hinweise für Gate Schwellwertspannung von E-MOS Transistoren ergänzt
1.04 / 01.12.2012
Bedienungshinweise J-FET / D-MOS Messung
Bedienungshinweise NPN, PNP Transistormessung
Option EBC_STYLE im Konfigurationsteil ergänzt
Halbleitertests mit ATmega8 und ATmega168 wiederholt.
Bedienungshinweise überarbeitet
1.03 / 24.11.2012
Dank an Beteiligte im Vorwort ergänzt.
Ergebnisse der Widerstandsmessung von 9 ATmega8 ergänzt.
Ergebnisse der Kondensator Messung von 9 ATmega8 ergänzt.
Optionen C_MESS und R_MESS fuer die Konfiguration entfernt.
1.02 / 01.11.2012
Beschreibung der Änderungen für die Streifenleiterversion ergänzt.
Weitere Beispiele für Induktivitätsmessungen ergänzt.
Meßverfahren für Induktivitäten ohne 680 Ohm Widerstand bis zu einem Widerstandswert von 24 Ohm, nicht 8 Ohm.
1.01 / 19.10.2012
Induktivitätsmessung bei Widerständen kleiner 2100 Ohm, nicht 2800 Ohm.
Englische Beschreibung der Induktivitätsmessung ergänzt.
Ergänzung von Beispielmessungen zur ESR-Messung.
Ergänzung des Kondensatorkapitels um die Beschreibung der ESR Messung.
1.00 / 23.9.2012
Ergängung der JFET Messung.
Ergänzung Kapitel Induktivitätsmessung.
Beschränkung hFE < 65536 ist entfallen, Text angepaßt.
Beschreibung der Option UF_OUT_MV entfernt, Option ist entfallen.
Erläuterung der Selbsttest-Funktionen ergänzt und umgestellt wegen Differenzausgaben.
Beispiele fuer Autocalibration der Widerstandsmessung eingefuegt.
0.99 / 15.8.2012
Beispiele fuer Autocalibration der Kondenstormessung eingefuegt.
Autokalibration fuer Kondensatormessung beschrieben.
Nullabgleich fuer Kondensatoren und Pin-Ausgangswiderstands Abgleich beschrieben.
Fehlerverlauf der Kondensatormessung mit mehr Folien-Kondensatoren anstelle von Elkos.
Fehlerverlauf der unkorrigierten Kondensatormessung für jeweils 3 mega168, mega168A und mega168PA eingefuegt.
Kapitel Bedienungshinweise eingefuegt
Bei Konfiguration die Anzeigeverlaengerung bei Mehrfachmessung durch laengeres Druecken des Startknopfs beschrieben.
0.98 / 26.7.2012
Beschreibung der neuen Option C_H_KORR für große Kondensatoren.
Beschreibung der Makefile Option UF_OUT_MV ergänzt.
Änderung der Makefile Option REF_KORR zu REF_C_KORR, probeweise REF_R_KORR eingefügt.
Anpassungen der Widerstandsmessung.
Fehlerkurven der Widerstandsmessung mit Minimal und Maximalwerten aus 10 Messungen.
0.97 / 09.06.2012
erste Transistortester Dokumentation in deutsch und englisch

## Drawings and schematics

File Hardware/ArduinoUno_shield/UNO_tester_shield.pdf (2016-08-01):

10K

## Finp

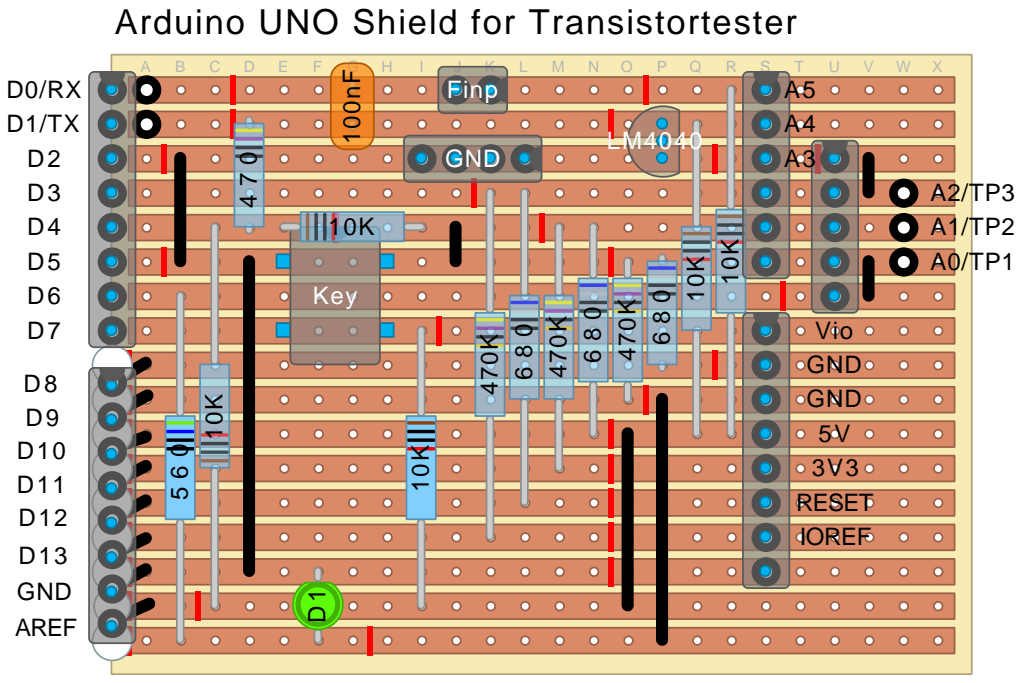
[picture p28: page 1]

Arduino UNO Shield for Transistortester

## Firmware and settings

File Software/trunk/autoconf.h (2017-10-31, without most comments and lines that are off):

#if ((LCD_ST_TYPE == 7565) || (LCD_ST_TYPE == 1306) || (LCD_ST_TYPE == 7108) || (LCD_ST_TYPE == 7920) || (LCD_ST_TYPE == 7735) || (LCD_ST_TYPE == 9163) || (LCD_ST_TYPE == 9341))
 #if ((SCREEN_HEIGHT > 127) && (SCREEN_WIDTH > 255))
  #define ONE_B 16
 #else
  #define ONE_B 8
 #endif
 #define WITH_GRAPHICS 1
 #undef PAGES_PER_LINE
 #define PAGES_PER_LINE ((FONT_HEIGHT + 7) / 8)
 #undef LCD_LINES
 #define LCD_LINES ((SCREEN_HEIGHT/ONE_B) / PAGES_PER_LINE)
 #undef LCD_LINE_LENGTH
 #define LCD_LINE_LENGTH (SCREEN_WIDTH / (ONE_B/8) / FONT_WIDTH )
 #define TEXT_RIGHT_TO_ICON ((ICON_WIDTH + 16 + 5 + 7) / FONT_WIDTH)
#elif (LCD_ST_TYPE == 8812)
 #define ONE_B 8
 #define WITH_GRAPHICS 1
 #undef PAGES_PER_LINE
 #define PAGES_PER_LINE ((FONT_HEIGHT + 7) / 8)
 #undef LCD_LINES
 #define LCD_LINES ((SCREEN_HEIGHT/8) / PAGES_PER_LINE)
 #undef LCD_LINE_LENGTH
 #define LCD_LINE_LENGTH (SCREEN_WIDTH / FONT_WIDTH)
 #define TEXT_RIGHT_TO_ICON ((ICON_WIDTH + 16 + 5 + 7) / FONT_WIDTH)
#elif (LCD_ST_TYPE == 8814)
 #define ONE_B 8
 #define WITH_GRAPHICS 1
 #undef PAGES_PER_LINE
 #define PAGES_PER_LINE ((FONT_HEIGHT + 7) / 8)
 #undef LCD_LINES
 #define LCD_LINES ((SCREEN_HEIGHT/8) / PAGES_PER_LINE)
 #undef LCD_LINE_LENGTH
 #define LCD_LINE_LENGTH (SCREEN_WIDTH / FONT_WIDTH)
 #define TEXT_RIGHT_TO_ICON ((ICON_WIDTH + 16 + 5 + 7) / FONT_WIDTH)
#else
 #define TEXT_RIGHT_TO_ICON 0
  #define FONT_HEIGHT 8
#endif
 #define LCD_ST7565_H_OFFSET 0
 #define LCD_ST7565_Y_START  0
#if LCD_ST7565_Y_START >= SCREEN_HEIGHT
 #warning LCD_ST7565_Y_START is set higher than SCREEN_HEIGHT!
#endif
#ifndef LCD_LINE_LENGTH
 #define LCD_LINE_LENGTH 16
#endif
#if (defined(WITH_GRAPHICS) && (((SCREEN_WIDTH-(TEXT_RIGHT_TO_ICON*FONT_WIDTH))/FONT_WIDTH) < 9))
 #define LOW_H_SPACE 1
#else
 #define LOW_H_SPACE 0
#endif
#if (LCD_ST_TYPE != 7920)
#define lcd_refresh()
#endif
#if (LCD_LINES < 2)
 #warning LCD_LINES is not correctly set!
 #if (SCREEN_HEIGHT < 32)
  #warning SCREEN_HEIGHT is not correctly set!
 #endif
 #if (FONT_HEIGHT < 8)
  #warning FONT_HEIGHT is not correctly set!
 #endif
#endif
#if (LCD_LINES < 7) && defined(WITH_6_SELECTION_MENU)
 #warning Display has not sufficient count of lines for WITH_6_SELECTION_MENU !
 #undef WITH_6_SELECTION_MENU
#endif
#if (PROCESSOR_TYP == 8) || (PROCESSOR_TYP == 168) || (PROCESSOR_TYP == 328)
 #if FLASHEND > 0x1fff
  #ifdef TQFP_ADC6
    #undef TPext
    #define TPext ((1<<MUX2) | (1<<MUX1))
    #ifdef TQFP_ADC7
      #define TPex2 ((1<<MUX2) | (1<<MUX1) | (1<<MUX0))
    #endif
  #else
    #ifdef TQFP_ADC7
      #undef TPext
      #define TPext ((1<<MUX2) | (1<<MUX1) | (1<<MUX0))
    #else
     #if (WITH_UART != 0) && (WITH_VEXT != 0)
      #warning "WITH_VEXT deselected, PC3 is used for UART"
      #undef WITH_VEXT
     #endif
    #endif
  #endif
 #else
  #ifndef BAT_CHECK
    #ifdef TQFP_ADC6
      #undef TPext
      #define TPext ((1<<MUX2) | (1<<MUX1))
    #endif
    #ifdef TQFP_ADC7
      #undef TPext
      #define TPext ((1<<MUX2) | (1<<MUX1) | (1<<MUX0))
    #endif
    #if (WITH_UART == 1) && (TQFP_ADC6 == 0) && (TQFP_ADC7 == 0) && (WITH_VEXT != 0)
      #warning "WITH_VEXT deselected, PC3 is used for UART"
      #undef WITH_VEXT
    #endif
  #endif
 #endif
#endif
#if BAT_NUMERATOR < BAT_DENOMINATOR
 #warning "Wrong BAT_NUMERATOR / BAT_DENOMINATOR setting!"
#endif
#if EXT_NUMERATOR < EXT_DENOMINATOR
 #warning "Wrong EXT_NUMERATOR / EXT_DENOMINATOR setting!"
#endif
  #define R_L_VAL 6800          // standard value 680 Ohm, multiplied by 10 for 0.1 Ohm resolution
  #define R_H_VAL 47000         // standard value 470000 Ohm, multiplied by 10, divided by 100
#if R_ANZ_MESS < ANZ_MESS
 #undef R_ANZ_MESS
 #define R_ANZ_MESS ANZ_MESS
#endif
#if U_SCALE < 1
 #undef U_SCALE
 #define U_SCALE 1
#endif
#if U_SCALE > 4
 #undef U_SCALE
 #define U_SCALE 4
#endif
 #define REF_L_KORR 50
#ifdef USE_EEPROM
 #define MEM_TEXT EEMEM
 #define lcd_MEM_string(a)  lcd_fix_string(a)
 #if E2END > 0X1FF
  #define MEM2_TEXT EEMEM
  #define MEM2_read_byte(a)  eeprom_read_byte(a)
  #define MEM2_read_word(a)  eeprom_read_word(a)
  #define lcd_MEM2_string(a)  lcd_fix_string(a)
  #define use_lcd_pgm
 #else
  #define MEM2_TEXT PROGMEM
  #define MEM2_read_byte(a)  pgm_read_byte(a)
  #define MEM2_read_word(a)  pgm_read_word(a)
  #define lcd_MEM2_string(a)  lcd_pgm_string(a)
  #define use_lcd_pgm
 #endif
 #define MEM_EEPROM
 #define MEM_read_word(a)  eeprom_read_word(a)
 #define MEM_read_byte(a)  eeprom_read_byte(a)
#else
 #define MEM_TEXT PROGMEM
 #define lcd_MEM_string(a)  lcd_pgm_string(a)
 #define MEM2_TEXT PROGMEM
 #define MEM_read_word(a)  pgm_read_word(a)
 #define MEM_read_byte(a)  pgm_read_byte(a)
 #define MEM2_read_byte(a)  pgm_read_byte(a)
 #define MEM2_read_word(a)  pgm_read_word(a)
 #define lcd_MEM2_string(a)  lcd_pgm_string(a)
 #define use_lcd_pgm
#endif
#if FLASHEND > 0X1FFF
 #define ACALL call
#else
 #define ACALL rcall
#endif
#if PROCESSOR_TYP == 168
  #define MCU_STATUS_REG MCUCR
  #define ADC_COMP_CONTROL ADCSRB
  #define TI1_INT_FLAGS TIFR1
  #define DEFAULT_BAND_GAP 1070
 #if R_H_VAL == 10000
  #define DEFAULT_RH_FAKT 4022      // mega168 1101 mV, 100.0 kOhm
 #else
  #define DEFAULT_RH_FAKT  856      // mega168 1101 mV, 470.0 kOhm
 #endif
  #define LONG_HFE
  #define PIN_RM 196
  #define PIN_RP 221
  #define CC0 36
  #define COMP_SLEW1 4000
  #define COMP_SLEW2 220
  #define C_NULL CC0+CABLE_CAP+(COMP_SLEW1 / (CC0 + CABLE_CAP + COMP_SLEW2))
  #define MUX_INT_REF 0x0e
#elif PROCESSOR_TYP == 328
  #define MCU_STATUS_REG MCUCR
  #define ADC_COMP_CONTROL ADCSRB
  #define TI1_INT_FLAGS TIFR1
  #define DEFAULT_BAND_GAP 1070
 #if R_H_VAL == 10000
  #define DEFAULT_RH_FAKT 4022      // mega328 1101 mV, 100.0 kOhm
 #else
  #define DEFAULT_RH_FAKT  856      // mega328 1101 mV, 470.0 kOhm
 #endif
  #define LONG_HFE
  #define PIN_RM 200
  #define PIN_RP 220
  #define CC0 36
  #define COMP_SLEW1 4000
  #define COMP_SLEW2 180
  #define C_NULL CC0+CABLE_CAP+(COMP_SLEW1 / (CC0 + CABLE_CAP + COMP_SLEW2))
  #define MUX_INT_REF 0x0e
#elif PROCESSOR_TYP == 644
  #define WITH_ROTARY_CHECK
  #define WITH_UJT
  #define WITH_PUT
  #define MCU_STATUS_REG MCUCR
  #define ADC_COMP_CONTROL ADCSRB
  #define TI1_INT_FLAGS TIFR1
  #define DEFAULT_BAND_GAP 1070
 #if R_H_VAL == 10000
  #define DEFAULT_RH_FAKT 4022      // mega1280 1101 mV, 100.0 kOhm
 #else
  #define DEFAULT_RH_FAKT  856      // mega1280 1101 mV, 470.0 kOhm
 #endif
  #define LONG_HFE
  #define PIN_RM 200
  #define PIN_RP 220
  #define CC0 36
  #define COMP_SLEW1 4000
  #define COMP_SLEW2 180
  #define C_NULL CC0+CABLE_CAP+(COMP_SLEW1 / (CC0 + CABLE_CAP + COMP_SLEW2))
  #define MUX_INT_REF 0x1e
#elif PROCESSOR_TYP == 1280
 #ifndef WITH_ROTARY_CHECK
  #define WITH_ROTARY_CHECK
 #endif
  #define MCU_STATUS_REG MCUCR
  #define ADC_COMP_CONTROL ADCSRB
  #define TI1_INT_FLAGS TIFR1
  #define DEFAULT_BAND_GAP 1070
 #if R_H_VAL == 10000
  #define DEFAULT_RH_FAKT 4022      // mega1280 1101 mV, 100.0 kOhm
 #else
  #define DEFAULT_RH_FAKT  856      // mega1280 1101 mV, 470.0 kOhm
 #endif
  #define LONG_HFE
  #define PIN_RM 200
  #define PIN_RP 220
  #define CC0 36
  #define COMP_SLEW1 4000
  #define COMP_SLEW2 180
  #define C_NULL CC0+CABLE_CAP+(COMP_SLEW1 / (CC0 + CABLE_CAP + COMP_SLEW2))
  #define MUX_INT_REF 0x1e
#else
  #define MCU_STATUS_REG MCUCSR
  #define ADC_COMP_CONTROL SFIOR
  #define TI1_INT_FLAGS TIFR
  #define DEFAULT_BAND_GAP 1298		//mega8 1298 mV
 #if R_H_VAL == 10000
  #define DEFAULT_RH_FAKT 3328      // mega8 1298 mV, 100.0 kOhm
 #else
  #define DEFAULT_RH_FAKT  740      // mega8 1250 mV, 470.0 kOhm
 #endif
  #define LONG_HFE
  #define PIN_RM 196
  #define PIN_RP 240
  #define CC0 27
  #define COMP_SLEW1 0
  #define COMP_SLEW2 33
  #define C_NULL CC0+CABLE_CAP+(COMP_SLEW1 / (CC0 + CABLE_CAP + COMP_SLEW2))
  #define MUX_INT_REF 0x0e
  #define INHIBIT_SLEEP_MODE
  #warning "SLEEP_MODE not possible with mega8"
#endif
 #define REF_R_KORR 0
 #define REF_C_KORR 0
#ifdef POWER_OFF
 #if (POWER_OFF+0) > 2
  #define OFF_WAIT_TIME SHORT_WAIT_TIME
 #else
  #define OFF_WAIT_TIME (LONG_WAIT_TIME - 1)
 #endif
#else
 #define OFF_WAIT_TIME  (LONG_WAIT_TIME - 1)
#endif
#define F_ADC 200000
#if F_CPU/F_ADC <= 2
 #define TICS_PER_ADC_CLOCK 2
 #define AUTO_CLOCK_DIV ((0<<ADPS2) | (0<<ADPS1) | (1<<ADPS0))
#elif F_CPU/F_ADC <= 4
 #define TICS_PER_ADC_CLOCK 4
 #define AUTO_CLOCK_DIV ((0<<ADPS2) | (1<<ADPS1) | (0<<ADPS0))
#elif F_CPU/F_ADC <= 8
 #define TICS_PER_ADC_CLOCK 8
 #define AUTO_CLOCK_DIV ((0<<ADPS2) | (1<<ADPS1) | (1<<ADPS0))
#elif F_CPU/F_ADC <= 16
 #define TICS_PER_ADC_CLOCK 16
 #define AUTO_CLOCK_DIV ((1<<ADPS2) | (0<<ADPS1) | (0<<ADPS0))
#elif F_CPU/F_ADC <= 32
 #define TICS_PER_ADC_CLOCK 32
 #define AUTO_CLOCK_DIV ((1<<ADPS2) | (0<<ADPS1) | (1<<ADPS0))
#elif F_CPU/F_ADC <= 64
 #define TICS_PER_ADC_CLOCK 64
 #define AUTO_CLOCK_DIV ((1<<ADPS2) | (1<<ADPS1) | (0<<ADPS0))
#else
 #define TICS_PER_ADC_CLOCK 128
 #define AUTO_CLOCK_DIV ((1<<ADPS2) | (1<<ADPS1) | (1<<ADPS0))
#endif
#ifndef PIN_RP
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

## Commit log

2012-06-08 Neue Doku und Software
2012-06-09 Version 0.97k der Doku hinzugefügt
2012-06-09 Version 0.97k der Software hinzugefügt
2012-06-10 Anpassungsmöglichkeit für leeren Kondensator in der Makefile
2012-06-28 Verbesserung Widerstandsmessung und ANZ_MESS Fehler
2012-07-09 Overflow Problem bei Kondensatormessung
    [main.c]
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2012-07-26 Untersuchung und Anpassung mega168
2012-07-28 automatische Entfernung von überflüssigen Code, wenn keine POWER_OFF=5 Option
2012-08-03 Vergleich der Kondensatormessungen, Multimeter,LCR, TTester hinzugefügt
2012-08-06 Autokalibration Kondensator-Nullwert und Pin-Ausgangswiderstände
2012-08-07 kleine Korrektur und Doku ergänzt
2012-08-08 Neue Halbleitermessung in der Doku
2012-08-09 PicoPower Version in Makefile und config.h berücksichtigt
2012-08-10 Ausgabeformat Schwellspannung FET in V
2012-08-12 Eintragefehler 56nF und ATmega8 Anpassung
2012-08-13 Kondensatormessungen mit ATmega328 und ATmega328P ergänzt
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2013-01-25 Pin layout with 123= style for thyristor and mega8
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2013-02-06 Problem ohne Abschaltelektronik beseitigt
    [main.c]
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2013-03-05 ESR Messung ab 0.45uF mit 500kHz ADC Clock
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2013-06-21 Anpassung der Erkennung von Verarmungs FET wegen Reststrom
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2013-09-25 Anpassung des 0.2V Offsets bis 3.25V BAT_POOR Pegel
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2013-11-13 Ergaenzung der Programmfiles fuer DOGM LCD mit Streifenrasterlayout
2013-11-30 Overflow Problem der Kondensatormessung mit Sleep Mode beseitigt
    [main.c]
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2013-12-18 Umbau Transistor Tests wegen NPNp und PNPn Erkennung
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2013-12-28 Hinweis auf unkalibrierten Tester und Nullkapazitaet < 190pF
2014-01-02 Kollektor Reststrom Ausgabe und bessere Germanium Transistor Erkennung
2014-01-04 Doku/tags mit Unterverzeichnissen fuer Sprache und alte Versionen
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2014-01-14 in einem Messzyklus wird Diode und Widerstand erkannt, BU508D
2014-01-14 Widerstandssymbol statt R als Hinweis bei Diodenmessung fuer mega328
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2014-01-21 Thyristorerkennung korrigiert, Fragezeichen in Zeile 1 = unKalibriert
    [main.c]
2014-01-22 Fehlerbeseitigung RvalOut.S und neue Funktionen i2lcd und u2lcd
2014-01-25 PinLayout und lcd-routines in Assembler, TRIAC Erkennung erweitert und dokomentiert
2014-01-26 geaenderte D-mode Erkennung und Aseembler wait_for_key_ms und get_log
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2014-01-31 UART reset fuer Mega328 , Konfiguration Mega168 an flash angepasst
    [autoconf.h, main.c]
2014-02-01 Initialisierung der Abgleichdaten, wenn USE_EEPROM nicht gesetzt ist, mega328
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2014-02-04 Vor Widerstandsmessung mit GetESR wird erst Induktivität geprüft
2014-02-07 Makro AOUT für Port-Zugriff, Russischer und Ukrainischer Hilfetext
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2014-03-03 Optionen TQFP_ADC6 und TQFP_ADC7 fuer 32 Pin SMD Versionen
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2014-03-24 separate ESR-Messung, TRIAC Erkennung korrigiert, m324 Serie vorbereitet
    [autoconf.h, main.c]
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2014-05-23 Bugfix ST7565 display driver
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2014-05-24 Korrekturen und Nachtrag in der russischen Doku Version
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2014-06-07 Flip of ST7565 display horizontal und vertikal getrennt
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2014-06-30 Option WITH_VEXT in der Makefile fuer externe Spannung
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2014-07-31 kein Warten bei 4-zeiligem Display bei Diode und Widerstand
2014-08-01 Pin setting for rotary switch and ST7565 controller
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2014-08-11 Adapter fuer Impulsdrehgeber und Frequenz-Eingang von Markus R.
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2014-09-08 Korrektur der Reihenfolge der R0 Werte in ShowData
2014-10-05 Bei Start von AutoCheck wird PartFound auf unerkannt gesetzt
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2014-12-20 I2C support for SSD1306, new ESR correction for low capacity
    [autoconf.h, main.c]
2014-12-20 Schutzdiode bei bipolaren Transistoren auch in der Graphik.
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2015-01-27 russische Version der 371er Doku und Korrektur der Doku
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2015-02-18 fixing the problem with the protection diode for ST7920
    [main.c]
2015-02-24 H/V Flip with software, untested ST7108 support with 74HC164
    [autoconf.h, main.c]
2015-02-26 Correction of ST7108 circuit
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2015-03-08 Makefile Problem mit russisch ohne LCD_CYRILLIC beseitigt
    [autoconf.h]
2015-03-12 Neuanordnung von Icon und Messparametern auf graphischen Displays
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2015-03-17 automatischer Start der Kondensator und Widerstandsmessfunktion an TP1:TP3
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2015-03-23 Resistor and capacity measurement without menu possible + documentation update
2015-03-26 ST7920 Korrektur, VBat check bei [RL] und [C], russische Doku
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2015-04-06 Correction, enable frequency out arduino
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2015-04-16 longer display time for low Battery, GetESR for mega2560
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2015-04-23 correcting wrong IC4 connection of ATmega644 circuit
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2015-09-13 First part of the "sampling ADC" measurement code: - the actual sampling code - capacitance measurement (not yet calibration/subtraction of null capacity) - modification to DisplayValue.c to handle e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
2015-09-15 SamplingADC capacitance measurements: - autocalibration - allow negative results - diode measurement: show capacitance both at low and high voltage to identify varicap
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2015-09-16 Initalize the null capacitance values in EEPROM with reasonable defaults.
2015-09-19 Fixed top line of [RL] mode for case of no coil detected, and for 20-char wide display.
2015-09-20 Error in Battery_check, switch off
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2015-09-23 Rewrite of the code displaying R and L results: - is now shared between main() and show_Resis_Cap() - also sampling L measurement between TP1:2 and TP2:3 - avoids flashing lcd by overwriting instead 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
    [main.c]
2015-09-23 Save 30 bytes of flash by revising sorting of display data for 2 resistors.
2015-09-30 Correction no ESR >1000uF
    [main.c]
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2015-10-03 Vak-Diodes problem with ILI9163,ST7735
2015-10-05 Correct of range check for graphical display
    [main.c]
2015-10-18 correction of middle menu entry
    [main.c]
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2015-11-06 Measure capacitance of double diode if compiled with samplingADC, since double diodes are often varicaps.
2015-11-11 New compile option #define big_cap_no_float enables 470 kOhm pull-up during ADC cycle in big cap measurement routine. This prevents detection of spurious big caps when in fact nothing is connected.
2015-11-23 Rewrote samplingADC.S; now takes same arguments as samplingADC_cnt.S (which removed conditional code elsewhere), but has precisely periodic measurements and code is shorter.
    [main.c]
2015-11-27 Tausch von Counter1 compare match Interrupts wegen samplingADC
2015-11-30 spezieller PWM-Modus fuer Modellbau Servo mit Option PWM_SERVO
2015-12-01 Correcting error of standard PWM with SVN version 614
    [autoconf.h]
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2016-01-02 Correction of missing Selection: without POWER_OFF option
    [autoconf.h]
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2016-02-21 Abschalten des Testers nach Beenden des [C] oder [RL] Auto-Modus
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2016-02-24 Improvements to the crystal code: - only try crystals if cap < 100 pF - on weak crystal signals (typ. at high freq.), repeat 4 times and add to improve SNR - better sine approximation in minifourier(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
2016-03-07 Correction of f-generator problem without POWER_OFF
2016-03-28 sure instead of shure correction
    [main.c]
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2016-04-23 Arduino UNO shield with LM4040 Correction
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2016-06-01 correction for mega8, english documentation
    [main.c]
2016-08-01 correction for Arduino Uno shield
2016-08-23 Enable interruption by keypress of the ceramic resonator and crystal measurements, since they take a lot of time and can easily be started accidentally.
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2016-12-25 correction of capacity limit for ESR mwasurement
2017-01-19 additional 470k resistor for the half amount of single ESR measurements
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2017-03-28 Hardware Entwurf von Max
    [fritzing_sketch2.fzz]
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2017-05-23 Made text "DC Pwr Mode" configurable from Makefile. (Useful e.g. for devices which use USB rather than an AC/DC power adapter.)
2017-05-23 Enable 470k resistor from HiPin to ground during pin discharge, to prevent not detecting completion of discharge if there's some leakage in the circuit (e.g., via protection diodes).
2017-05-24 For JFETs only show cut-off voltage if measured value is not near 5 V (as then JFET may not really have been cut-off).
    Added measurement of I_{DSS} for JFET.
    Compliation onditional on #ifdef FET_Idss.
    So far only for N-channel, and output only on text display.
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2017-05-27 neue russische Doku-Uebersetzung + Korrektur der englischen Doku
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

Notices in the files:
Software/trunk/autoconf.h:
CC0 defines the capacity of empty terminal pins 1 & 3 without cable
